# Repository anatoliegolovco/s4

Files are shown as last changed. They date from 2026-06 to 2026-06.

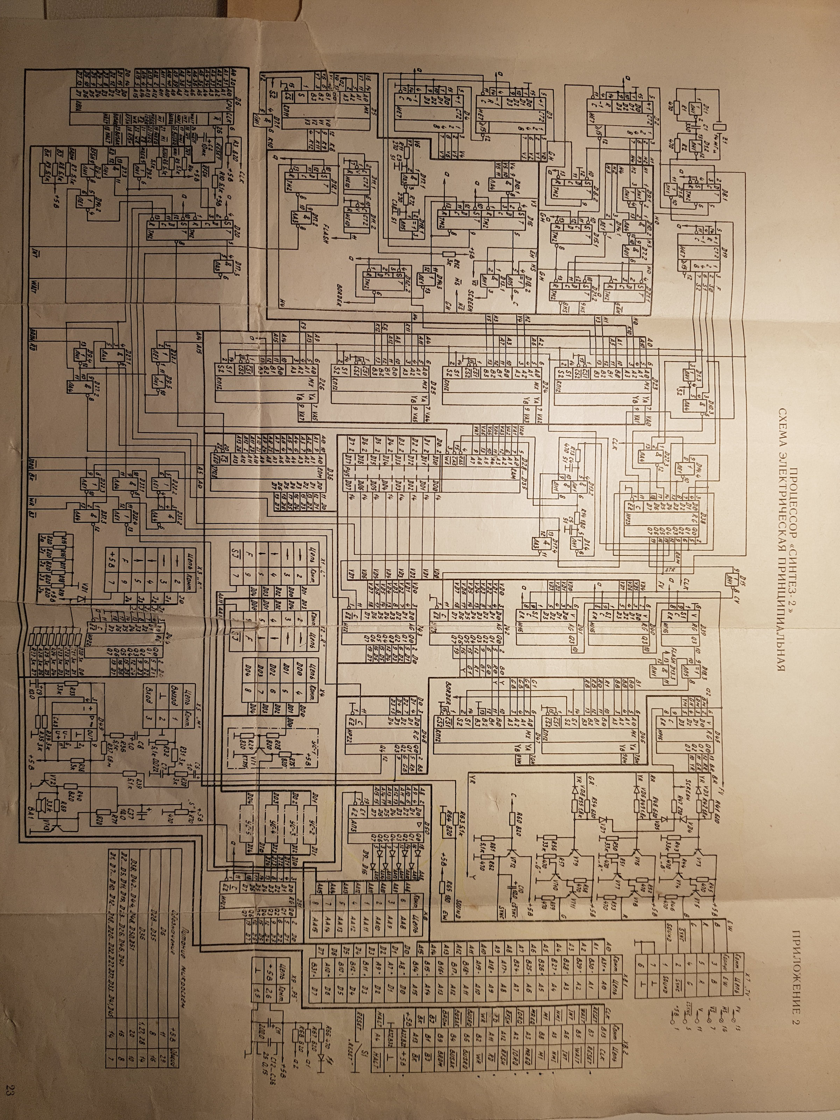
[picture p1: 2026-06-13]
reference/schematics/sintez2-mainboard-photo.jpg

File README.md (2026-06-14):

# s4 — Sintez 4

**Sintez 2 — Modern Reconstruction & LLM-Driven Visual Simulation.**

A modern, sourceable recreation of the Soviet/Moldovan discrete-TTL ZX Spectrum
clone (keeping a real Zilog Z80), a visual open-source simulator (SimulIDE) the
owner can watch, and a text-only LLM control plane that drives the full
iterate→simulate→verify→layout loop with zero clicks. KiCad is the source of
truth for the PCB.

## Start here

- **Technical spec (canonical):** [`docs/spec/sintez2-recon-spec.md`](./docs/spec/sintez2-recon-spec.md)
- **Docs index:** [`docs/README.md`](./docs/README.md)
- **Decisions:** [`docs/decisions/`](./docs/decisions/)
- **Discussion ledger:** [`docs/ledger/README.md`](./docs/ledger/README.md)
- **Repo layout:** [`docs/repo-layout.md`](./docs/repo-layout.md)

## Source tree

`schematics/` · `kicad/` · `bridge/` · `sim/` · `llm/` · `cpu/` · `tests/` ·
`parts_map.json` — all currently skeletons, populated per milestones T0–T9 in
the spec. All Markdown lives under `docs/` (project rule).

## License

**Proprietary and confidential — © 2026 Lightcypher SRL. All rights reserved.**
This is **not** open-source software. See [`LICENSE`](./LICENSE). Third-party
tools (KiCad, SimulIDE, ngspice, SKiDL) keep their own licenses; mirrored
datasheets/scans under `reference/` belong to their respective owners.

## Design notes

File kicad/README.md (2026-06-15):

# kicad — canonical project (source of truth for the PCB)

See `docs/spec/sintez2-recon-spec.md` §5.1 and milestones T2/T8.
Gerbers ordered from here. The LLM mostly edits `.kicad_sch` as text and uses
`kicad-cli` for ERC/DRC/netlist/Gerber export (IPC API is PCB-only in 9.0).

(Skeleton — no project authored yet.)

## T8 — PCB (in progress)

The PCB is seeded from the SKiDL netlist (no hand layout):
```bash
# 1. netlist -> board with all footprints (run once to seed)
PYTHONPATH=/usr/lib/python3/dist-packages KICAD9_FOOTPRINT_DIR=/usr/share/kicad/footprints \
  .venv/bin/kinet2pcb -i kicad/sintez2.net -o kicad/sintez2.kicad_pcb -w
# 2. spread footprints + add board outline
PYTHONPATH=/usr/lib/python3/dist-packages python3 kicad/place_board.py
# 3. fab outputs
kicad-cli pcb export gerbers -o kicad/gerbers/ kicad/sintez2.kicad_pcb
kicad-cli pcb export drill   -o kicad/gerbers/ kicad/sintez2.kicad_pcb
```
**Status:** `kicad/sintez2.kicad_pcb` has all 85 footprints placed on a 9×10 grid
(337×320 mm) with an Edge.Cuts outline; Gerber + drill export verified (26 files).
DRC: 23 courtyard/silk overlaps + 421 unconnected pads = **not routed yet**.
**Next:** tighten placement by block; route (manual or Freerouting .dsn/.ses);
then DRC-clean + final Gerbers/BOM. `kicad/sintez2.kicad_pcb` is the layout source
of truth — do NOT re-run kinet2pcb once routing starts (it overwrites the board).

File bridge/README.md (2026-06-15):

# bridge — KiCad ↔ SimulIDE converter

See `docs/spec/sintez2-recon-spec.md` §7 and milestone T3.

- `net2sim.py` — KiCad netlist (`kicad/sintez2.net`, from SKiDL) → SimulIDE
  circuit (`sim/circuits/*.sim1`), canonical direction.
- `sim2net.py` — optional reverse.

Mapping is driven by `../parts_map.json`.

## SimulIDE `.sim1` format (1.1.0-SR2, learned from `examples/Logic/*.sim1`)

```xml
<circuit version="" rev="2221" stepSize="1000000" stepsPS="1000000" ...>
  <item itemtype="Subcircuit" CircId="74XX90-3" Pos="x,y" label="7490"
        Input_High_V="2.5 V" Out_High_V="5 V" Out_Low_V="0 V" Out_Imped="40 Ω"
        Tpd_ps="10000 ps" Tr_ps="3000 ps" Tf_ps="4000 ps" .../>     <!-- IC -->
  <item itemtype="Clock" CircId="Clock-2" Freq="2 Hz" Voltage="5 V" .../>
  <item itemtype="Node"  CircId="Node-112" Pos="x,y" />              <!-- fan-out -->
  <item itemtype="Connector" uid="connector-113"
        startpinid="Clock-2-outnod" endpinid="74XX90-3-CP0" pointList="x,y,..." />
</circuit>
```
- Each component = one `<item>`; pins referenced as `"<CircId>-<pinname>"`.
- Each net with N endpoints → one `Node` + N `Connector`s (star), or chained connectors.
- **Per-part logic-family timing** (`Tpd_ps`, `Out_High_V`, `Out_Imped`, input
  thresholds/impedance) is set on each Subcircuit — this is where the К555 (LS) vs
  К1533 (ALS) distinction lives (spec §3). net2sim sets these from `parts_map.json`.

## Part mapping (Soviet → SimulIDE library item)

SimulIDE ships everything needed (data dir): a **Z80** model (`z80.xml` — use it,
NOT "ULA ZX48k"), the full 74xx series (`data/ic74.xml`), RAM/ROM/EEPROM, CD4000
(`icCD.xml`), and a USSR lib (`ussr.xml`).

| Sintez (ref) | KiCad/SKiDL part | SimulIDE item |
| --- | --- | --- |
| D6 Z80 | Z84C00 | `Z80` |
| D36 ROM 27128 | 27128 | `Memory`/`EEPROM` (16Kx8, load ROM bin) |
| D28-D35 К565РУ5 | K565RU5 | `RAM` (initial); behavioral РУ5 w/ RAS-CAS = T5 custom |
| ИЕ7 (D2/3/4/19) | K1533IE7 | `74HC193` |
| КП11 (D5) | K1533KP11 | `74HC257` |
| КП12 (D23-26) | K1533KP12 | `74XX253` |
| ИР22 (D43/44/48/51) | K1533IR22 | `74HC373` |
| ИР23 (D42) | K1533IR23 | `74HC374` |
| ИР27 (D38) | KR1533IR27 | `74XX273` |
| АП3 (D50) | K1533AP3 | `74XX244` |
| ИР16 (D39-41/45) | K555IR16 | 4-bit shift (`74XX166`-class), KEEP LS timing |
| ЛН1/ЛА3/ЛА4/ЛИ1/ЛЕ1 | K1533LN1/LA3/LA4/LI1/LE1 | `74XX04/00/10/08/02` |
| СА3 (D49) | K544SA3 | comparator (analog) |

## Validation goal (why the bridge exists)

Load the generated `.sim1` in SimulIDE, run, and validate the nodes the
trace-verify workflow could NOT resolve visually (see
`docs/references/validation-trace-verify-2026-06-14.md`): ROM /CE-/OE gating,
the arbitration screen-address select, RAS-before-CAS, beep/port-0xFE — and the
overall "boots to the © prompt" bar (spec T7). Contention tests must NOT pass.

## Status

- **net2sim.py — v1, LOADS CLEANLY in SimulIDE (0 errors).** Parses
  `kicad/sintez2.net` and emits `sim/circuits/sintez2.sim1`:
  - **Z80** → `itemtype="MCU"` (pins PORTA*/PORTD*/CPORT0*); 74xx → `Subcircuit`
    (pin number→id from SimulIDE `.package`, `_LS` variant for К555 timing);
    R/C → Resistor/Capacitor; crystal → 14 MHz Clock.
  - **Nets → drawn orthogonal wires, channel-routed.** Components sit in a single
    ROW; each net gets a unique horizontal TRACK in the channel BELOW the row, with
    a 3-pin Node under each pin and a vertical drop from pin→track. Because every
    track is below the components, **no wire crosses a component body** (wires only
    cross each other — SimulIDE has no auto-router; confirmed via its docs). Run:
    36 comps → 27 items, 98 nodes, 171 connectors.
  ```bash
  .venv/bin/python bridge/net2sim.py
  DISPLAY=:0 simulide sim/circuits/sintez2.sim1 &   # opens cleanly
  ```
  Verified headless: `simulide <file>` reports **0 load errors**.
  Coverage caveats it prints: DRAM (D28–D35) + ROM (D36) skipped (need SimulIDE
  Memory/DynamicMemory items — next); D5 follows the netlist (still КП12 in SKiDL —
  set to КП11 when arbitration is finished); КП12→74HC153, ИР16→74XX166 (8 vs 4-bit),
  ЛА4→74HC00 (no 3-in NAND in lib) are approximations.
- **Next:** (a) add ROM (`itemtype="Memory"`, load the ROM bin) + DRAM
  (`itemtype="DynamicMemory"` — ideal for РУ5 RAS/CAS) with their pin maps;
  (b) set per-part family timing (Tpd/Out_V) from parts_map on each Subcircuit;
  (c) run + validate boot-to-© and RAS-before-CAS.
- **Template:** `examples/Micro/Z80/ZX_Spectrum/ULA_Z80-MCU.sim1` (a ZX48 in
  SimulIDE) — reference for Z80-MCU + Memory + Tunnel wiring (but it uses a ULA,
  which the Sintez does NOT — we keep discrete TTL).

(`sim/circuits/*.sim1` is a generated build artifact — gitignored; regenerate.)

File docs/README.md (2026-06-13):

# s4 — Documentation

Code name **Sintez 4**.

**Project:** *Sintez 2 — Modern Reconstruction & LLM-Driven Visual Simulation.*
A modern, sourceable recreation of the Soviet/Moldovan discrete-TTL ZX Spectrum
clone (keeping a real Zilog Z80), a visual open-source simulator the owner can
watch, and a text-only LLM control plane that drives the whole
iterate→simulate→verify→layout loop zero-click.

The canonical technical specification is
[`spec/sintez2-recon-spec.md`](./spec/sintez2-recon-spec.md). **Read it first.**

## Layout

| Path | Purpose |
| --- | --- |
| `docs/README.md` | This index. Start here. |
| `docs/RULES.md` | Rules for writing and maintaining docs and the ledger. |
| `docs/spec/` | Canonical technical specification. |
| `docs/decisions/` | Decision records (ADR-style) for lasting choices. |
| `docs/datasheets/` | Datasheet links + key parameters per part. |
| `docs/references/` | Catalog of owner-supplied primary sources (in `reference/`). |
| `docs/repo-layout.md` | The source-tree layout (spec §9) and deviations. |
| `docs/templates/` | Reusable templates for docs, decisions, and ledger entries. |
| `docs/ledger/` | Discussion ledger: timestamped Q&A grouped by topic. |

## Key decisions (non-negotiable constraints)

- [0001 — Keep a genuine Zilog Z80](./decisions/0001-keep-real-zilog-z80.md)
- [0002 — KiCad is the source of truth for the PCB](./decisions/0002-kicad-source-of-truth-for-pcb.md)
- [0003 — Text-only, zero-click LLM control plane](./decisions/0003-text-only-llm-control-plane.md)
- [0004 — Fidelity over improvement: no memory contention](./decisions/0004-fidelity-no-memory-contention.md)

## Conventions (summary)

- **Language:** every written record is in **English**, even when the
  discussion happened in another language.
- **Files and folders:** `kebab-case` (lowercase, words joined by `-`).
- **Timestamps:** UTC, ISO 8601 (`YYYY-MM-DDTHH:MM:SSZ`).

See [`RULES.md`](./RULES.md) for the full set of rules.

## Quick start

1. Understand the project → read [`spec/sintez2-recon-spec.md`](./spec/sintez2-recon-spec.md).
2. See where work stands → [`ledger/README.md`](./ledger/README.md) (open questions).
3. Adding a doc? Copy [`templates/doc.md`](./templates/doc.md).
4. Recording a decision? Copy [`templates/decision-record.md`](./templates/decision-record.md).
5. Logging a discussion? See [`ledger/README.md`](./ledger/README.md).

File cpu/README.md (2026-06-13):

# cpu — Z80 soft-core integration (simulation only)

See `docs/spec/sintez2-recon-spec.md` §4. In simulation we always use a
behavioral Z80 core (TV80 / A-Z80); the real Z84C00 only lives on the
fabricated PCB.

(Skeleton — not yet implemented.)

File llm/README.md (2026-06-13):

# llm — text-only LLM command surface

See `docs/spec/sintez2-recon-spec.md` §6 and milestone T4. Zero-click, text in/out.

- `kicad_cmds.py` — kicad-cli / kicad-python / IPC wrappers.
- `sim_cmds.py` — SimulIDE control + probe/scope/assert.
- `vcd_to_json.py` — compact JSON from VCD.
- `verdicts.py` — M1 timing, RAS/CAS, sync, boot checks.

(Skeleton — not yet implemented.)

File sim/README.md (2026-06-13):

# sim — SimulIDE components & generated circuits

See `docs/spec/sintez2-recon-spec.md` §5.2, §6.2 and milestones T5/T6.

- `components/` — extended SimulIDE component classes / subcircuits
  (К565РУ5 behavioral DRAM, КП12 mux, ИЕ7 counter, ИР16 shift register).
- `circuits/` — generated `.sim` files (not committed).

(Skeleton — not yet implemented.)

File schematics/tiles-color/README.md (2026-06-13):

# Color schematic (redraw) — tiles & extraction

The colorized **vector** redraw `reference/schematics/sintez2-original.pdf`
(842×595 pt, A4 landscape) is far cleaner than the photographic scan and, decisively,
**names its nets and prints exact part numbers**. It is the *primary* source for
the netlist; the scan (`../tiles/`) is the cross-check.

## Color semantics (decoded from per-color layer separations)

| Stroke RGB | Meaning |
| --- | --- |
| `(0.63,0,0)` dark red | **component symbols + pins** (IC bodies, R/C, transistors, connectors) |
| `(0,0,1)` blue | **text labels** — net names, bus names, designators, pin names |
| `(0,0.63,0.63)` cyan, `(0,0.63,0)` green, `(0,0,0.75)` dk-blue, `(1,0,0)` red, black | **wires/nets**, color-grouped for routing legibility |

The text is vector outlines (not selectable — `get_text()` returns 0 chars), so
labels are still read visually, but at this clarity transcription is reliable.

## Files

- `c_r{row}c{col}.png` — 4×3 overlapping grid @400 dpi (same scheme as `../tiles/`).
- `_overview.png` — whole sheet @200 dpi.
- `_grid_overview.png` — overview with a 50-pt magenta coordinate grid (use it to
  pick clip rectangles for tight high-zoom crops).
- `layers/layer_<color>.png` — each stroke color rendered in isolation. `layer_darkred`
  = the parts layer; `layer_blue` = the net-name layer; the rest are wire groups.
  **These are the net-tracing aid**: follow one wire color to see a net group alone.
- `zoom/zoom_*.png` — high-zoom crops where exact part numbers / pinouts were read
  (color stage, DRAM, RGB output + connectors, X8 bus pinout).

## Reproduce a tight crop

```python
import fitz
p = fitz.open("reference/schematics/sintez2-original.pdf")[0]
p.get_pixmap(matrix=fitz.Matrix(1000/72, 1000/72),
             clip=fitz.Rect(615, 278, 725, 340)).save("zoom_x8.png")  # X8 bus pinout
```

## What this pass corrected vs the scan

- **Logic family is К1533** (≈74ALS/F), not К555, for the glue/counters/muxes.
  Registers/shift-registers are **К555ИР16/ИР22/ИР23** (LS) and DRAM is **К565РУ5**.
- **D41** (not "D61") is the third pixel shift register — matches the spec text.
- **D13 = К1533ЛИ1** generates **/RAS** and **/CAS** (with R15 470 + C5).
- **D14 = К1533ЛЕ1** (NOR) — original scan read was right.
- CPU is labeled **Z80A** (D6); D28–D35 block is labeled **DRAM**.
- Net names harvested: see `../wiring.json`.

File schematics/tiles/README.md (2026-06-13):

# Schematic tiles — segmentation map

High-resolution segments of the Sintez-2 mainboard schematic, kept so the
visual extraction is reproducible and reviewable without re-rendering.

- **Source:** `reference/schematics/sintez2-schematic.pdf` (page is 2040×1560 pt).
- **Render:** PyMuPDF at **350 DPI** with overlapping clip rectangles.
- **Naming:** `t_r{row}c{col}.png` — a 3-row × 4-col grid (rows top→bottom,
  cols left→right). Overlap avoids cutting components at seams.

## Grid → page rectangle (PDF points) and dominant content

| Tile | clip rect (x0,y0,x1,y1) | Dominant content |
| --- | --- | --- |
| `t_r1c1` | 15,25,560,500 | Z1 14 MHz; sync counters D2/D19; D8 ТМ2; D1 ЛН1 |
| `t_r1c2` | 520,25,1060,500 | address mux D23; RAM addr latch D38; sheet title |
| `t_r1c3` | 1020,25,1545,500 | pixel chain D39/D40/D61; color D45/D46; RGB ladder |
| `t_r1c4` | 1480,25,2035,500 | connectors X7 "TV", X8.1/X8.2 bus; RGB transistors |
| `t_r2c1` | 15,470,560,930 | vertical counters D3/D4; sync gates; D31 ИЕ10 |
| `t_r2c2` | 520,470,1060,930 | **DRAM D28–D35**; address muxes D24/D25 |
| `t_r2c3` | 1020,470,1545,930 | video latches D42/D43/D48; attr mux D47; D50 |
| `t_r2c4` | 1480,470,2035,930 | connectors X8 cont.; D50 buffer; sync transistors |
| `t_r3c1` | 15,895,560,1305 | **CPU D6 (Z80)**; WAIT D20; keyboard mux КП11 |
| `t_r3c2` | 520,895,1060,1305 | **ROM D36**; addr mux D26; decode gates |
| `t_r3c3` | 1020,895,1545,1305 | tape X5 "M"; УС-1 (VT1 КТ315); modules УС-2..5 |
| `t_r3c4` | 1480,895,2035,1305 | D51 latch; X9 power; **"Питание микросхем"** table |

Extra full-context renders:
- `_full_overview.png` — whole sheet at 150 DPI.
- `_right_connectors_top.png` / `_right_connectors_bot.png` — the right-edge
  connector + power tables at 300 DPI.

## Reproduce

```python
import fitz
d = fitz.open("reference/schematics/sintez2-schematic.pdf"); p = d[0]
m = fitz.Matrix(350/72, 350/72)
p.get_pixmap(matrix=m, clip=fitz.Rect(15, 895, 560, 1305)).save("t_r3c1.png")  # CPU
```

Extraction results live in `../bom.json` (parts) and `../wiring.json` (nets).

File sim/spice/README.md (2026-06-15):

# sim/spice — analog corner validation (ngspice)

Batch SPICE decks (`ngspice -b *.cir`) validating the analog parts of the Sintez-2
that digital simulation can't (spec §5.3). Run, e.g.:

```bash
ngspice -b sim/spice/psu_mod.cir
```

## psu_mod.cir — the factory 39 Ω GND-lift mod ✅ VALIDATED

The unit had a 39 Ω resistor between the LM7805 GND pin and ground; the repair video
measured **~5.35 V** no-load. A 78xx regulates 5 V between OUT and its GND pin, and
its ground-pin current `Ignd` flows through that resistor: **Vout = 5 + Ignd·Rgnd**.

| Ignd | Vout (39 Ω, factory) | Vout (39‖15 = 10.6 Ω, repair) |
| --- | --- | --- |
| 4.3 mA (typ) | 5.17 V | 5.05 V |
| 6 mA | 5.23 V | 5.06 V |
| 8 mA | 5.31 V | 5.08 V |
| 9 mA | **5.35 V** | 5.10 V |

**Result:** the measured 5.35 V corresponds to Ignd ≈ 9 mA — exactly the documented
behavior. The 15 Ω parallel repair pulls Vout back to ~5.05–5.10 V (near nominal,
effect reduced but not removed — matches the video). Mechanism confirmed quantitatively.

## rgb_level.cir — RGB output levels (КТ315 follower) ✅ representative

One colour channel: TTL colour + BRIGHT bits → resistor DAC → КТ315 emitter follower
→ 75 Ω TV/SCART input. Validates distinct, monotonic levels and that the КТ315
(Vbe/hFE) sets them (spec class-4: 2N3904/BC237 would shift the levels).

| State | Vout into 75 Ω |
| --- | --- |
| OFF | ~0 V |
| NORMAL | 0.96 V |
| NORMAL + BRIGHT | 1.37 V |

**Result:** normal vs bright are cleanly separated → the analog levels are real and
КТ315-dependent. ⚠ Weights here are representative (R48 620, R49 1.8k, R43 33k);
the exact per-board ladder topology is still to be traced
(`docs/references/validation-trace-verify-2026-06-14.md`), after which this deck
becomes the board-exact RGB model (milestone T6).

## Not modeled here
- **14 MHz crystal oscillator** — high-Q crystal start-up is impractical in plain
  transient SPICE; treat the clock as an ideal source in the digital/SimulIDE model.
- **К565РУ5 DRAM RAS/CAS timing** — behavioral, belongs in the SimulIDE model (T5).

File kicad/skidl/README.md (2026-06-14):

# kicad/skidl — canonical schematic authored in SKiDL (text → KiCad netlist)

Per decision [0005](../../docs/decisions/0005-skidl-text-schematic.md), the
Sintez-2 schematic (spec milestone T2) is authored as **Python/SKiDL**, which
emits a **KiCad netlist** that feeds Pcbnew for layout (T8, decision 0002) and
`bridge/net2sim.py` for SimulIDE. SKiDL is the text-only surface the LLM drives
zero-click (decision 0003); no graphical `.kicad_sch` is hand-drawn.

## Files
- `sintez_parts.py` — the Sintez part library: each IC defined with its real pin
  list (number/name/type) from `docs/datasheets/` + `schematics/bom.json` (v0.3).
  No KiCad symbol library needed; footprints reference KiCad's standard `Package_DIP:*`.
- `sintez2.py` — the top-level design, built block by block. Generates
  `kicad/sintez2.net` and runs ERC.

## Run
```bash
.venv/bin/python kicad/skidl/sintez2.py
```
(`.venv` has `skidl`; create with `python3 -m venv .venv && .venv/bin/pip install skidl`.)
The generated `*.net` is a build artifact (gitignored) — regenerate from the Python.

## Status — block by block (spec §8)
- [x] **Block 1 — CPU + clock + reset** (D6 Z80, Z1 14 MHz osc + D1 К1533ЛН1,
      reset RC C2/R10, control-input pull-ups R4–R7). Netlist generates, **0 ERC
      errors** (warnings are unconnected bus pins — expected until the blocks
      below are wired).
- [x] **Block 2a — ROM (D36 27128)** wired to the A0–A13 / D0–D7 buses + power
      (VPP/PGM=VCC). Verified: A0=D6.30+D36.10 … D0=D6.14+D36.11; A14 CPU-only
      (27128 is 16K). /CE,/OE are named decode nets pending the decode sub-block.
- [x] **Block 2b — ROM decode** (D22 ЛЕ1, D9 ЛН1, D17 ЛА3): ~ROMCS =
      NAND(A14 NOR A15, ¬/MREQ); ROM /OE = /RD. Logic verified in the netlist,
      0 ERC errors. ⚠ Functional: exact gate-section/pin mapping to verify vs the
      scan. Screen / I/O (port 0xFE) selects + D10/D27/D37/D26 still to add.
- [x] **Block 3 — DRAM array (D28–D35 К565РУ5)** — 8×1-bit = 64 KB, sharing VA0–VA7
      (address-pin map from wiring.json), /RAS, /CAS, /WE; per-bit DIN←Dn, DOUT→DDn.
      /RAS,/CAS from D13 ЛИ1; /WE=/WR. Verified, 0 ERC errors. ⚠ Timing strobes into
      D13 + refresh come from the arbitration/sync blocks (4/5); РУ5 timing model = T5.
- [~] **Block 4 — bus arbitration ("crown jewel"), PARTIAL.** D5/D23/D24/D25/D26
      КП12 + D38 ИР27 placed + powered; mux outputs mapped to VA0–VA5 (drives the
      DRAM address bus). ⚠ The data-INPUT mapping (screen-address generator: which
      CPU/video bit → which 4:1 input, + select/enable timing) is deliberately NOT
      guessed — it must be traced pin-by-pin from the scan (most intricate logic on
      the board). VA6/VA7 source + D26 paging + D38 latch nets also pending.
- [~] **Block 5 — /4 CPU-clock divider + sync counters.** D8 ТМ2 ripple-divides
      CLK14 → 7 MHz (dot) → 3.5 MHz **CLK** (resolves the CPU clock; was undriven).
      D2/D19 (H) + D3/D4 (V) ИЕ7 counters placed/powered/clocked + cascaded.
      ⚠ H/V sync DECODE (counter bits → HSYNC/VSYNC/blank via D10/D14/D21) functional/TODO.
- [ ] Block 6 — pixel chain (D39/D40/D41 ИР16) + colour (D42–D48) + RGB out.
- [ ] Block 7 — tape/audio (D49 К544СА3, beep) + disk I/O (D44/D50/D51) + connectors.

Each block draws its pin-level nets from `schematics/wiring.json` (filled in as
blocks are traced).

## KiCad version
For PCB layout + headless ERC you need **KiCad 9** (kicad-cli 7 has no `sch erc`):
```bash
sudo add-apt-repository -y ppa:kicad/kicad-9.0-releases
sudo apt update && sudo apt install -y kicad
```
The SKiDL netlist generation here does **not** need KiCad installed.

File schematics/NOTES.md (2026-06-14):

# schematics/NOTES.md — block inventory & scan-error reconciliation

> **Status: T1 essentially COMPLETE (v0.3).** Every functional block listed with
> source + discrepancies resolved; **all 51 ICs identified** (see `bom.json`).
> Deliverable for T1 in the spec (`docs/spec/sintez2-recon-spec.md` §8). Primary
> sources in the repo (`reference/`, catalogued in
> `docs/references/sources-catalog.md`). Remaining work is pin-level net tracing
> (→ `wiring.json`, milestone T2).

## Sources in hand

| Source | Location | Used for | Notes |
| --- | --- | --- | --- |
| Sintez-2 mainboard schematic (scan) | `reference/schematics/sintez2-schematic.pdf` | mainboard nets + BOM | "ПРИЛОЖЕНИЕ 2", clean scan, BOM table on right edge |
| Sintez-2 mainboard schematic (redraw) | `reference/schematics/sintez2-original.pdf` | cross-check | colorized re-draw of the same sheet |
| Beta Disk board photo | `reference/photos/betadisk-original.png` | TR-DOS controller | КР1818ВГ93 (WD1793) confirmed |
| 128 KB expansion writeup | `reference/photos/sintez128.jpg` | banking mod | port #7FFD paging |
| SCART/Jack video mod | `reference/pinouts/video-pinout.png` | RGB output stage | 200 Ω sync resistor note |
| MCbx (corrected pinouts) | https://oldcomputer.info/8bit/sintez/index.htm | TBD | online cross-check |
| speccy.info (RU) | https://speccy.info/Sintez | TBD | online cross-check |
| zx-pk.ru | https://zx-pk.ru | TBD | repair threads |

## Block inventory

Designators below were transcribed from the segmented tiles
(`schematics/tiles/`). Full structured data is in `schematics/bom.json`
(parts) and `schematics/wiring.json` (nets). `[x]` = block identified;
pin-level nets are tracked in `wiring.json`'s per-block `status`.

- [x] **CPU & clock** — **D6 = Z80** (power pins 11/29 confirm DIP-40); Z1
      14 MHz pixel clock; clock R3 820, reset C2 10µF + R10 5.1k, pull-ups
      R4/R5 5.1k; WAIT gen D20/D12 ТМ2. (tile r3c1)
- [x] **Address decode** — D26 КП12 mux (A9/A13/A14/A15); decode gates
      D22 (ЛЕ1), D9 (ЛН1), D10/D27/D37 (ЛА4), D17 (ЛА3); ROM /CE pin20, /OE pin22;
      decode signals /BROM,/RD,/WR,/IORQ,/BK,/WAIT,/BJ. (tiles r2c1, r3c2)
- [x] **DRAM + refresh** — **D28–D35 = К565РУ5** ×8 (power pins 8/16); address
      muxes D24/D25 → VA; refresh address from ИЕ7 counters; WAIT to slow РУ5.
      (tile r2c2)
- [x] **Video bus arbitration ("crown jewel")** — D23/D24/D25/D26 КП12
      (≈74ALS253) + D38 ИР23 latch → VADDR + RAS/CAS. (tiles r1c2, r2c2)
- [x] **Sync generation** — D2/D19 (H), D3/D4 (V) = ИЕ7 (СТ2 counters); D8/D21
      ТМ2; D10 ЛА4; D14 ЛЕ1; D18 ЛП5 (FLASH). (tiles r1c1, r2c1)
- [x] **Pixel chain** — **D39/D40/D41 = К555ИР16** @ 14 MHz; **keep LS timing**.
      ⚠ К555ИР16 is a **4-bit / 14-pin** shift register (PE/SI/C/OE, D0-D3→Q0-Q3),
      **NOT 74LS165** (which is 8-bit/16-pin). D39=VD0-VD3, D40=VD4-VD7 (=8-bit
      pixel shifter), D41=3rd nibble/attribute. (redraw symbols, tile r1c3)
- [x] **RGB output stage** — VT3–VT18 (КТ315Г/КТ361Г) + ladder R41 620/R42
      1.8k/R47 270/R48 620/R49 1k/R54 620/R55 1.8k/R60 820 + VD3–VD8; УС-1
      emitter follower (VT1). SCART mod: **200 Ω sync** (100 Ω → color loss).
      Color stage D42/D43/D45/D46/D47/D48. (tiles r1c3, r2c3, r3c3)
- [x] **Audio/tape** — port 0xFE (BEEP/border/tape); X5 "M" connector
      (TAPE_IN/GND/TAPE_OUT); R30/R31 3k, R32 5.1k. ⚠ Tape-IN is squared by
      **D49 = К544СА3, an analog COMPARATOR** (R37 1.8M feedback) — **NOT** a
      К5545АЗ/LM567 tone decoder as the spec §2.5 states. BEEP: port-0xFE bit →
      R69 33k → VT2/VT13 КТ315 → BA1 speaker. (tiles r3c3, r3c4)
- [x] **TR-DOS / Beta Disk** — **КР1818ВГ93 ≈ WD1793** (FDC on daughterboard;
      schematic now in `reference/schematics/betadisk-controller-bdi.pdf`).
      Mainboard carries **D50 = К1533АП3** (74244 buffer, AA8-AA15 disk address
      via КД522 diodes) + **D51/D44 = К1533ИР22** (74373 disk-data latches).
      Joystick/disk connectors X1('L')/X2('R')/X3('K')/X4/X6. Board `СМП59-96Г-16-2`.
- [ ] **(Optional) 128 KB expansion** — port `#7FFD` paging; mod chips
      К555ТМ9 / К1533КП11 / К555ЛЛ1 / К1533ЛА3 (`reference/photos/sintez128.jpg`).
      Opt-in variant — see `docs/ledger/architecture/bank-switching-ram-size.md`.

## Two source documents

- **Scan** `reference/schematics/sintez2-schematic.pdf` — authoritative original;
  carries the connector + power tables. Tiled in `schematics/tiles/`.
- **Colorized vector redraw** `reference/schematics/sintez2-original.pdf` — cleaner,
  **names nets and prints exact part numbers**. Tiled in `schematics/tiles-color/`
  (+ `layers/` per-color separations, + `zoom/` high-zoom crops). **Primary**
  net-naming source; the scan is the cross-check. Color code: dark-red=parts,
  blue=net labels, other colors=wire groups.

## Redraw cross-check corrections (v0.2)

- Logic family is **К1533** (≈74ALS/F); registers **К555ИР16/ИР22/ИР23** (keep LS);
  DRAM **К565РУ5**; CPU labeled **Z80A**.
- **D41** (not "D61") is the 3rd pixel shift register (К555ИР16) — matches spec.
- **D13 = К1533ЛИ1** generates **/RAS** and **/CAS** (R15 470 + C5).
- **D14 = К1533ЛЕ1** (NOR). **D45 = К555ИР16** color register; **D46/D47 = К1533КП12**.
- **X8** is a 64-pin expansion bus, pinout now high-confidence (`tiles-color/zoom/zoom_x8.png`).
- **УС-1…УС-5 = YC-1…YC-5**: five identical single-transistor analog driver modules.

## BOM & wiring — structured outputs

- `schematics/bom.json` — every identified package (ref → Soviet type → western
  equivalent → block), with `confidence` flags and a `gaps_to_resolve` list.
- `schematics/wiring.json` — buses, control signals, connector pinouts, power
  pins, and block-to-bus relations; pin-level intra-block nets are the next pass.
- Pipeline & status: `docs/schematic-extraction.md`.

## v0.3 — full IC resolution & corrections (2026-06-14)

Read directly from the **KiCad/Eeschema redraw** `Sintez_II_orig.sch` (NPO Signal
Chișinău, 29 oct 2012 — title block confirms it), rendered at 600–800 dpi from
`reference/schematics/sintez2-original.pdf` and cross-checked against the
"Питание микросхем" power table for pin counts.

**Previously-open designators — now resolved:**

| Ref | Type | ≈ Western | Pins | Role |
| --- | --- | --- | --- | --- |
| D37 | К1533ЛА4 | 74ALS10 | 14 | triple 3-in NAND — keyboard/joystick decode |
| D44 | К1533ИР22 | 74ALS373 | 20 | octal latch — disk-data path |
| D49 | **К544СА3** | LM311-class comparator | 14 | **tape-IN comparator** |
| D50 | К1533АП3 | 74ALS244 | 20 | octal buffer — disk address AA8-AA15 |
| D51 | К1533ИР22 | 74ALS373 | 20 | octal latch — disk data-in |

**Corrections to the spec / earlier BOM:**

1. **D38 = КР1533ИР27** (74273 octal D-FF, 20-pin) — earlier read as ИР23/74LS374.
2. **К555ИР16 (D39/D40/D41/D45) is a 4-bit / 14-pin shift register, NOT 74LS165**
   (8-bit/16-pin). The redraw symbol shows PE/SI/C/OE + D0-D3→Q0-Q3; the power
   table puts them in the 14-pin group. D39(VD0-3)+D40(VD4-7) = the 8-bit pixel
   shifter. This resolves the v0.2 "discrepancy to reconcile". Exact 74xx
   equivalent (4-bit, 14-pin, 3-state, parallel-load) still TBD.
3. **Tape decoder is wrong in the spec:** the part is **К544СА3 (a comparator)**,
   not К5545АЗ/LM567. Spec §2.5 / §3 / §11 should be updated when convenient.

**Connectors captured (→ `wiring.json`):** X7 "TV" (SOUND/SYNC/B/G/R/GND, +
monitor group FV/HS/VS/Y/CSYNC/+5V), X8 64-pin expansion = full Z80 bus
(SNP58-64), X5 tape "M", X1/X2 Sinclair joysticks, X3 keyboard, X4/X6 disk,
X9 power. Full power-pin table transcribed.

## Known scan errors to reconcile

- [ ] Some connector pinouts in public scans relate to the mainboard rather
      than the wired connectors → cross-check MCbx re-mastered pinouts.
- [ ] Cross-check the in-repo scan against the colorized redraw
      (`sintez2-original.pdf`); log any net that disagrees here with resolution.

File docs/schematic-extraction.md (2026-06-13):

# Schematic extraction pipeline

How the paper Sintez-2 schematic becomes machine-readable design data, and the
text format we capture **before** anything goes into KiCad or SimulIDE.

## Two source documents

1. **Scan** `sintez2-schematic.pdf` (2040×1560 pt raster) — the authoritative
   original; has the connector + "Питание микросхем" power tables. Tiled in
   `schematics/tiles/`.
2. **Colorized redraw** `sintez2-original.pdf` (842×595 pt **vector**) — cleaner,
   and it **names nets and prints exact part numbers**. Tiled in
   `schematics/tiles-color/` with per-color layer separations. This is the
   **primary** source for the netlist and part numbers; the scan is the cross-check.

The redraw's color code: dark-red = parts/pins, blue = net-name labels, other
colors = wire groups. Text is vector outlines (not selectable), so labels are
still read visually — but at this clarity, transcription is reliable. Rendering
one wire color in isolation (`tiles-color/layers/`) is the net-tracing aid.

## Pipeline

```
sintez2-schematic.pdf (scan)      sintez2-original.pdf (vector redraw)
   │ render @350dpi, grid             │ render @400dpi grid + per-color layers
   ▼                                  ▼
schematics/tiles/             schematics/tiles-color/  (+ layers/, zoom/)
   └──────────────┬───────────────────┘
                  ▼  visual transcription (designators, types, nets, pins)
   schematics/bom.json    ← parts: ref → type → western equiv → block
   schematics/wiring.json ← nets: buses, connectors, power, block relations
                  │  (incremental, per-block, with confidence flags)
                  ▼
   parts_map.json + bridge/net2sim.py → KiCad (.kicad_sch) / SimulIDE (.sim)
```

The two JSON files are the **canonical intermediate**. They are plain text, so
the LLM owns them (spec §6), and they are filled **one block at a time** with a
`confidence`/`status` flag on every entry — we never silently promote a guess.

## Why JSON before software

- KiCad's schematic API is text-only in 2026 (decision
  [0003](./decisions/0003-text-only-llm-control-plane.md)); authoring from a
  structured netlist is far more reliable than drawing by hand.
- The same JSON drives the KiCad→SimulIDE bridge (spec §7), so BOM and wiring
  stay in one source of truth.
- Confidence flags let us author the **high-confidence blocks first** (CPU,
  ROM, DRAM) and leave low-confidence nets clearly marked for verification
  against the colorized redraw (`sintez2-original.pdf`) and zx-pk.ru.

## Current status (2026-06-13)

- **Tiles:** both sources segmented and committed — scan (3×4 grid,
  `schematics/tiles/`) and color redraw (4×3 grid + 7 color-layer separations +
  high-zoom crops, `schematics/tiles-color/`).
- **Redraw cross-check (v0.2):** logic family confirmed **К1533** (≈74ALS/F),
  registers **К555ИР16/22/23**, DRAM **К565РУ5**, CPU **Z80A**. Corrections:
  **D41** (not "D61") is the 3rd pixel shift register; **D13 = ЛИ1** makes
  /RAS+/CAS; **D14 = ЛЕ1**. **X8** 64-pin bus pinout now high-confidence.
- **BOM:** ~40 packages identified — CPU **D6 = Z80** (confirmed via power
  table), **D28–D35 = К565РУ5 DRAM**, **D36 = 16 KB ROM**, pixel chain
  **D39/D40/D61 = ИР16 (74LS165)**, address arbitration **D23–D26 = КП12
  (74ALS253) + D38 ИР23 latch**, sync counters **D2/D3/D4/D19 = ИЕ7**. See
  `schematics/bom.json`.
- **Wiring:** buses, control signals, connectors (X5/X9 high-confidence;
  X7/X8 medium), power pins, and block-to-bus relations captured. Pin-accurate
  intra-block nets are the next pass (`schematics/wiring.json` → `todo`).

## Next

Trace nets pin-by-pin in milestone order: **cpu → decode → dram →
addr-arbitration** (T2/T3), mark each block `status: done`, then feed it to
`bridge/net2sim.py` for a SimulIDE smoke test. See `schematics/NOTES.md`.

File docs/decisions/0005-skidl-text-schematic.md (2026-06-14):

# 0005 — Author the schematic in SKiDL (Python → KiCad netlist)

- **Status:** accepted
- **Date:** 2026-06-14
- **Deciders:** project owner
- **Related:** [0002 KiCad source of truth](0002-kicad-source-of-truth-for-pcb.md) ·
  [0003 text-only LLM control plane](0003-text-only-llm-control-plane.md) ·
  spec §5.1 / §8 (T2)

## Context

T2 needs the canonical Sintez-2 schematic (~51 ICs). The spec §5.1 assumed we
"edit `.kicad_sch` as text". Hand-authoring KiCad `.kicad_sch` S-expressions
(symbol placement coordinates, wires, labels) for 51 ICs is slow and error-prone,
and KiCad has **no Soviet-part symbols** anyway. kicad-cli 7 (Ubuntu noble) also
lacks headless `sch erc` (added in v8+).

## Decision

**Author the schematic as Python using SKiDL**, which emits a **KiCad netlist**.
- Parts are defined once in `kicad/skidl/sintez_parts.py` from the datasheets /
  `schematics/bom.json` (pin number/name/type) — these definitions ARE the parts;
  no KiCad symbol library is required to produce a netlist.
- Standard through-hole **DIP footprints are reused** from KiCad's `Package_DIP:*`
  (every Sintez IC is a DIP) — no custom footprints to draw.
- The generated netlist → Pcbnew for PCB layout (T8) and → `bridge/net2sim.py`
  for SimulIDE. **KiCad remains the source of truth for the PCB** (decision 0002
  unchanged); SKiDL is just the text front-end that authors it.

## Consequences

- Positive: the design is plain Python — ideal for the zero-click LLM loop
  (decision 0003), git diffs, parameterization, and reuse; SKiDL runs its own ERC
  without KiCad installed.
- Trade-off: no hand-drawn graphical `.kicad_sch`. If a human-viewable schematic
  is ever wanted, generate `.kicad_sym`/a schematic from the same pin data — it is
  not on the fabrication path.
- Follow-ups: KiCad **9** still needed for Pcbnew layout + headless ERC at T8
  (`ppa:kicad/kicad-9.0-releases`); `parts_map.json` continues to drive the bridge.

## Alternatives considered

- **Hand-author `.kicad_sch` text** (spec §5.1 literal) — rejected: too tedious /
  error-prone for 51 ICs, no Soviet symbols, needs KiCad 8+ for headless ERC.
- **Generate `.kicad_sch` from `wiring.json`** — real graphical schematic, but
  requires building a robust auto-placement generator first; deferred (can still
  be added later for human viewing).

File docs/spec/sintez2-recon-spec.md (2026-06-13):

# Sintez 2 — Modern Reconstruction & LLM-Driven Visual Simulation

## Technical Specification / Hand-off Brief for a Claude Code Context

> **Read me first.** You are a fresh Claude Code agent inheriting an ongoing
> retro-computing project. You did **not** participate in the prior design
> conversations; this document is your entire context. It is intentionally
> dense and self-contained. Treat every section as authoritative project
> knowledge. Where you must search, the canonical links are in
> [§12 References](#12-references). When in doubt about Sintez-specific
> hardware quirks, the Russian community at **zx-pk.ru** has people with the
> physical machine and corrected schematics.

-----

## 0. TL;DR — What we are building

Three deliverables, one loop:

1. **A modern recreation of the Sintez 2** — a Soviet/Moldovan ZX Spectrum
   clone built entirely from discrete TTL logic (no ULA chip) — rebuilt with
   **modern, sourceable components** while keeping a **real Zilog Z80** CPU.
1. **A visual, open-source electronics simulator** where the human owner can
   **watch the signals propagate** (buses, /MREQ, RAS/CAS, pixel clock, RGB).
1. **An LLM “puppeteering” layer**: the simulator and EDA tools are open
   source so we **extend their internal classes / APIs** with **text-friendly
   functions** an LLM can drive **fully automatically, zero-click** — no GUI
   pixel-clicking, no human in the inner loop.

The board is fabricated by exporting to / authoring in **KiCad** (Gerbers →
PCB fab). The visual play happens in **SimulIDE**. A **text↔text bridge**
connects the two so the LLM owns the full iterate→simulate→verify→layout loop.

**Non-negotiable constraints**

- Keep a genuine **Zilog Z80** (Z84C00 family) in the physical build.
- **KiCad is the source of truth for the PCB** (you order from its Gerbers).
- Everything the LLM touches must be **text** (netlists, `.kicad_sch`, SimulIDE
  XML, VCD, JSON) — never screen automation.
- **Fidelity over “improvement”:** the Sintez has no memory contention. If a
  contention-dependent test passes, the model is *wrong* for this machine.

-----

## 1. Project background — what the Sintez 2 actually is

- **Origin:** Soviet-era ZX Spectrum 48K-compatible clone manufactured at the
  **“Signal” plant (НПО «Сигнал»)** in **Chișinău, Moldovan SSR**, ~1989.
  It is **not** a Romanian clone (do not confuse with ICE Felix HC-85, Cobra,
  CIP from Băneasa/Politehnica) and **not** Băneasa.
- **CPU:** Uses the Soviet **UA 880D / КР1858ВМ1**-class part, which is
  **pin- and opcode-compatible with the Zilog Z80**. Runs at **3.5 MHz**.
- **Defining hardware trait — NO ULA.** Unlike a real Spectrum (Ferranti ULA),
  the Sintez 2 implements all video/timing/glue with **discrete TTL** (Soviet
  К555 / К1533 families ≈ 74LS / 74ALS). The RGB output is generated directly
  at TTL level (clean digital), not through a ULA.
- **Consequence — NO MEMORY CONTENTION.** There is no ULA disputing the bus,
  so the Z80 runs at a constant 3.5 MHz with **no slowdown** on any memory
  region. This is the single most important behavioral fact:
  - The Z80 core uses **canonical T-state counts** — no contention table, no
    `6,5,4,3,2,1,0,0` pattern.
  - Software that depends on tight contention timing (multicolor demos,
    Nirvana engine, rainbow-border effects) **will not run** on real Sintez 2
    hardware and must **not** run in our model. That is fidelity, not a bug.
- **ROM/BASIC:** Runs the **stock ZX Spectrum 48K 16 KB ROM**. All BASIC
  interpreter / FP-calculator internals are standard Spectrum documentation.
- **Storage:** Beta Disk + **TR-DOS** (WD1793 FDC, separate TR-DOS ROM with
  bank switching) on 5.25” floppies, in addition to tape.

**Schematic caveat:** the publicly scanned Sintez schematics contain **known
errors** (some connector pinouts relate to the mainboard rather than the
wired connectors). A re-mastered schematic on the MCbx page has corrected
pinouts. Always cross-check against zx-pk.ru repair threads.

-----

## 2. Target hardware architecture (what the recreation must implement)

### 2.1 CPU & clock

- **Z80** @ **3.5 MHz** (canonical T-states; 69,888 T-states per 50 Hz frame:
  224 × 312).
- **Pixel clock 14 MHz = 2× CPU clock**, asynchronous to the CPU clock. Drives
  the pixel shift register chain.

### 2.2 Memory map (standard 48K Spectrum)

|Region |Address |Notes |
|---|---|---|
|ROM (BASIC + FP calculator + I/O) |`0x0000–0x3FFF` |16 KB, stock 48K ROM |
|RST handlers / vectors |`0x0000, 0x0008, 0x0010, …, 0x0038`|entry points |
|BASIC interpreter |`0x0000–0x1CFF` |main logic |
|FP calculator (5-byte float stack machine)|`0x1D00+` (`CALCULATE` ≈ `0x335B`) |RPN-like calc stack |
|Keyboard scan |`~0x028E` | |
|Character font (8×8) |`0x3D00–0x3FFF` |96 chars × 8 bytes = 768 bytes|
|Screen bitmap |`0x4000–0x57FF` |256×192, ZX interleaved layout|
|Screen attributes |`0x5800–0x5AFF` |32×24, byte = `FLASH |
|System vars / BASIC area / RAM |`0x5B00–0xFFFF` | |

- **Bank switching:** native Z80 addresses 64 KB. If the modern build wants
  more RAM, page it through a window with latches/registers holding a wide
  bank address (the Z80 doesn’t care what’s behind the address decoder).
  128–512 KB is typical; >1 MB is possible but software-impractical. The
  Z180/Z280 have built-in MMUs (up to ~1 MB) if a successor CPU is ever
  considered — but **we keep the Z80**.

### 2.3 Video subsystem (the most Sintez-specific part — all discrete TTL)

- **ULA-replacement logic:** discrete TTL generates H/V sync and bus
  arbitration. **No ULA chip exists** — this entire arbitration circuit is the
  “crown jewel” to visualize.
- **Sync/refresh counters:** **К1533ИЕ7** counters (≈ 74ALS counter) generate
  H/V sync and the DRAM refresh addresses.
- **CPU/video bus arbitration:** **КП12** multiplexers switch the address/data
  bus between CPU and video fetch.
- **Pixel shift registers:** **D39/D40/D41 = К555ИР16** (≈ **74LS165**),
  clocked at **14 MHz** to serialize pixel data. **Deliberately К555 (LS), not
  К1533 (ALS)** — the designer chose the slower family for more forgiving
  setup/hold margin against the pixel clock. **Preserve this choice.**
- **RGB output stage:** emitter-follower level shifters built from
  **КТ315Г (NPN) / КТ361Г (PNP)** transistors (VT13–VT18 region), with trimmer
  resistors (~R41–R60 region) to calibrate output levels per transistor batch.

### 2.4 Memory (DRAM) — timing is analog and matters

- **DRAM:** **К565РУ5** (≈ 4164, 64Kx1 DRAM). Requires **RAS-before-CAS**
  refresh; **RAS-only refresh cycles interleaved** with CPU accesses, addressed
  by the К1533ИЕ7 counter.
- The Sintez **WAIT generator was calibrated to the *slow* Soviet РУ5 timing**
  (tRAS, tCAS, tRCD, precharge, sense-amp recovery). zx-pk.ru repair threads
  confirm that dropping faster imported 4164s in can cause **instability**
  (WAIT pulse mismatch, marginal address setup). For simulation, **model DRAM
  behaviorally with actual К565РУ5 timing parameters** — do not silently swap
  to a generic 4164 or SRAM model, which would make the machine look more
  reliable than reality.

### 2.5 Audio & tape

- **BEEP** via port `0xFE` (also border + tape). Port `0xFE` writes must be
  **timestamped in T-states**, not collapsed at end-of-frame, because the
  raster exists regardless of TTL-vs-ULA implementation.
- **Tape tone decoder:** **К5545АЗ** ≈ **LM567**. **Do not substitute** for
  accurate analog behavior.

-----

## 3. Soviet → modern component substitution guide (encyclopedic)

Soviet ICs were **clones, not exact copies** — same nominal datasheet, but
different process nodes and fab tolerances, occasionally subtle circuit
changes. Risk of behavioral divergence splits into categories:

|#|Class |Examples |Substitution risk |Rule |
|-|---|---|---|---|
|1|**Pure Boolean logic** (~95% of the board)|К1533ЛА3 ≈ 74ALS10, decoders, bus muxes, control glue|**Zero** for logic state|Free to swap to 74ALS/74HC equivalents; truth tables identical |
|2|**DRAM** |К565РУ5 ≈ 4164 |**High (timing)** |Model with real РУ5 timing; swapping to fast 4164/SRAM changes WAIT behavior |
|3|**Pixel shift registers** |К555ИР16 ≈ 74LS165 (D39/D40/D41) |**Subtle (setup/hold)** |Keep **LS** family timing (~20–25 ns setup) — ALS (~7–10 ns) gives ~3× false margin |
|4|**Video-output transistors** |КТ315Г/КТ361Г (VT13–VT18) |**Analog levels** |RGB level depends on Vbe/hFE; real boards used trimmers. 2N3904/BC237 ≈ wrong levels|
|5|**Tape tone decoder** |К5545АЗ ≈ LM567 |**Do not substitute** |Keep equivalent function exactly |

**Practical guidance for the recreation:**

- For everything in **Class 1**, choose modern, **sourceable** logic
  (74HC/74HCT or 74ALS) — these are the parts you can buy and put on a PCB.
- For **Class 2 (DRAM)**: a real recreation may legitimately replace DRAM with
  **modern SRAM + glue** to drop the refresh complexity *in hardware*, but the
  **simulation model must keep РУ5 timing** if you want bug-for-bug fidelity.
  Decide explicitly per build target (faithful vs. “improved & reliable”).
- For **Class 3/4/5**: preserve family/part choices where analog/timing
  behavior is observable (pixel chain, RGB stage, tape).

> Tool note: AI-assisted “legacy → modern part” suggestion exists in
> **Flux (flux.ai / buildwithflux)** — Copilot can propose cheaper/in-stock
> alternatives, create parts from datasheets, and import **KiCad** libraries
> (schematic import from Altium ASCII / Cadence EDIF; **layout import not
> supported**). Optional aid, not a core dependency.

-----

## 4. Keeping a real Z80 — sourcing

|Part |What |Notes / where |
|---|---|---|
|**Zilog Z84C00** (e.g. Z84C0020)|Genuine modern CMOS Z80, in production|€3–5 at Mouser / Digi-Key / TME; ships to Moldova; **recommended default**|
|КР1858ВМ1 / КР1858ВМ3 |Soviet NMOS/CMOS Z80 clone |eBay / au.ru / orion43.ru; shipping restrictions vary |
|U880 / UB880D |East German (MME) clone |eBay; often easier to find than Soviet parts |
|MMN 80 CPU |Romanian (Microelectronica) clone |from Romania (EU neighbor) |
|MME “80A CPU” |Z80A 4 MHz NMOS clone |~$10 + shipping from Ukraine |

**FPGA fallback (if a physical Z80 ever becomes unavailable):** run an
open-source soft core — **TV80** or **A-Z80** — on a small FPGA
(Lattice iCE40, Gowin GW1N; boards: iCEBreaker, Tang Nano), optionally
pin-compatible with a Z80 socket. **In simulation we always use a soft/
behavioral Z80 core** (TV80 / A-Z80) because a physical chip can’t be
co-simulated; the real Z84C00 only lives on the fabricated PCB.

-----

## 5. Tool stack

### 5.1 KiCad — schematic + PCB + fabrication (source of truth for the board)

- **License:** GPL v3. Full EDA: schematic capture, PCB layout, Gerber output;
  runs on Windows/Linux/macOS.
- **Why it’s the hub:** you **order the PCB from KiCad’s Gerbers** — it is the
  destination, so there is **no “export to KiCad” step** if the schematic is
  authored here. Huge symbol/footprint libraries (74xx, Z80, modern parts).
- **Built-in simulation:** integrates **ngspice** for graphical SPICE
  simulation inside the Schematic Editor (good for analog: PSU, clock, RGB
  output path). Improved substantially in KiCad 8; usable for mixed-signal.
- **Puppeting surface (text/Python — this is the LLM control plane):**
  - **IPC API** (KiCad **9.0+**): stable, language-agnostic interface to a
    running KiCad session over a Unix socket / named pipe. **In 9.0 it covers
    the PCB editor only**; schematic-editor support is on the roadmap.
  - **`kicad-python`** (PyPI): official Python bindings for the IPC API.
    Requires a running KiCad with the API server enabled
    (Preferences → Plugins). Depends on `protobuf`, `pynng`.
  - **Legacy SWIG `pcbnew`** bindings: still present in 9/10, **deprecated**,
    **removed in KiCad 11** — do not build new work on SWIG.
  - **`kicad-cli`**: headless CLI for ERC/DRC, netlist export, plotting
    Gerbers, BOM, etc. — the backbone for zero-click batch steps.
  - **Schematic automation reality (2026):** because IPC doesn’t yet cover the
    schematic editor, the LLM mostly **edits `.kicad_sch` / `.kicad_pro` as
    text** and uses `kicad-cli` for netlist/ERC/exports. Plan around this.

### 5.2 SimulIDE — the visual signal playground (what the human watches)

- **License:** AGPL v3. C++/Qt. Real-time, drag-drop, “push the power button”
  interactive simulation; optimized for speed/low CPU.
- **Why it fits the TTL machine:** **event-driven engine, 1 ps accuracy**, and
  **no digital/analog split — everything runs in analog mode**: logic pins have
  **configurable impedance, output voltage, and LH/HL thresholds**, so it
  models **fan-in/fan-out and different logic families** (LS vs ALS vs HC) —
  exactly the К555-vs-К1533 distinction we must preserve.
- **Observability built-in:** **Oscilloscope**, **Logic Analyzer**, **circuit
  animation**, **VCD export** (configurable base time step, e.g. 100 ps; can
  export at pause), serial-port connection, subcircuits, DIP/logic symbols.
- **Extensibility (your “extend its classes” requirement):** custom components
  via **(a) subcircuits, (b) modular components, (c) script-based components**;
  modules exist for memories, displays, console, comms. For Sintez-specific
  parts (К565РУ5 behavioral DRAM, КП12 mux, ИЕ7 counter, ИР16 shift register)
  you add component classes in the C++ source and/or as subcircuit/script
  modules.
- **Limitation:** SimulIDE is a *simulator*, **not** a PCB/layout tool — it
  does **not** export KiCad/Gerber. Hence the bridge in §7.

### 5.3 ngspice

- The SPICE engine inside KiCad; also usable standalone in **batch mode
  (`-b`)** for the analog corners (PSU, 14 MHz/3.5 MHz clock generation, RGB
  emitter-follower levels with КТ315/КТ361 models). Text netlist in, data out.

### 5.4 Optional reference / cross-check tooling (from prior project work)

- **Software emulator** (separate track): C23 → WASM Z80 core + passive video
  renderer; validated headless via **ZEXDOC/ZEXALL** (Frank Cringle, CRC),
  **FUSE test suite** (`tests.in`/`tests.expected`, per-instruction T-states &
  memory accesses), **Patrik Rak** contention/floating-bus tests. **For Sintez
  2, contention tests must NOT pass** (no contention) — passing them means a
  wrong machine. Use ZEXDOC + “boots to the `©` prompt” as the bar.
- **Disassembly/RE:** Fuse (+ gdbserver fork `github.com/speccytools/fuse`,
  `--gdbserver <port>`), `z80dasm`, Ghidra (Z80 module), radare2/rizin,
  `z88dk-gdb`.
- **Floppy ingest (TR-DOS):** SAMdisk, Keir Fraser’s `disk-utilities`,
  `trdtool`/`trd2scl`, Fuse/libspectrum utils.

-----

## 6. LLM puppeteering layer (the core new work)

**Goal:** a thin, text-only control plane so an LLM iterates the design with
**zero clicks**. The LLM never drives a GUI; it edits text artifacts and calls
functions that return text/JSON.

### 6.1 Principle

- **GUI automation is forbidden.** No Playwright/Selenium pixel puppeting.
- The LLM operates on: `.kicad_sch`, `.kicad_pcb`, KiCad netlists (`.net`),
  SimulIDE circuit XML, VCD waveforms, and JSON status blobs.
- We **extend the open-source tools’ internal classes/APIs** to expose exactly
  the verbs the LLM needs, each producing **parseable text**.

### 6.2 The command surface to build (wrap, don’t reinvent)

Expose a small CLI/library (Python preferred) with verbs such as:

- **KiCad side (via `kicad-cli` + `kicad-python`/IPC + text edits):**
  - `kicad.netlist_export()` → canonical netlist (text)
  - `kicad.erc()` / `kicad.drc()` → JSON pass/fail + violations
  - `kicad.plot_gerbers()` → fab outputs
  - `kicad.place(ref, x, y)` / `kicad.list_footprints()` (PCB, IPC API)
  - `kicad.sch_edit(...)` → structured edits to `.kicad_sch` text (until IPC
    covers eeschema)
- **SimulIDE side (via extended C++ classes + a control socket/CLI you add):**
  - `sim.load(circuit.sim)` / `sim.run(t)` / `sim.pause()` / `sim.reset()`
  - `sim.probe(net)` → current logic level / voltage
  - `sim.scope(net, window)` → samples
  - `sim.export_vcd(path)` → waveform file
  - `sim.add_component(type, params)` / `sim.connect(a_pin, b_pin)`
  - `sim.assert(net, expected, at_t)` → JSON verdict
- **Analysis glue (write this):**
  - `vcd_to_json(path, nets=[…])` → compact JSON the LLM reads cheaply
  - Verdict helpers: “Is `/MREQ` low at T2 of an M1 fetch?”, “Is RAS-before-CAS
    honored?”, “Does boot reach the `©` prompt?”, “Are H/V sync periods within
    spec?”

> **Why this matches the requirement:** these are the “internal functions that
> are already text-compatible for an LLM.” KiCad’s Python/IPC API *is* such a
> surface (text in/out); for SimulIDE you create the equivalent by extending
> its classes and adding a headless control entry point.

### 6.3 The zero-click loop

```
        ┌─────────────────────────────────────────────────────┐
        │  LLM (Claude Code)                                   │
        │  reads JSON/VCD verdicts → edits netlist / sch text  │
        └───────────────┬─────────────────────────────────────┘
                        │ text edits + CLI calls
        ┌───────────────▼───────────────┐     ┌──────────────────┐
        │ KiCad (source of truth)        │     │ SimulIDE          │
        │ .kicad_sch / .kicad_pcb        │◄───►│ circuit XML       │
        │ kicad-cli: ERC/DRC/netlist/    │ §7  │ run → scope/LA →  │
        │ gerbers ; IPC(PCB) ; py edits  │bridge│ VCD export        │
        └───────────────┬───────────────┘     └─────────┬────────┘
                        │ netlist                        │ VCD/JSON
                        ▼                                ▼
                ┌───────────────────────────────────────────────┐
                │ Analysis glue: vcd_to_json + verdict library   │
                │ returns PASS/FAIL + reasons (text/JSON)         │
                └───────────────────────────────────────────────┘
                        ▲                                │
                        └────────── verdicts ────────────┘
```

One iteration: LLM edits canonical netlist/schematic → bridge regenerates the
SimulIDE circuit → `sim.run` → `export_vcd` → `vcd_to_json` + verdicts →
LLM reads text result → corrects. Periodically: `kicad-cli` ERC/DRC and
Gerber plot as sanity gates. **No human click anywhere in the inner loop.**
The human watches SimulIDE’s animated schematic when they *want* to (“vreau să
văd și eu”), but it is not required for progress.

-----

## 7. KiCad ↔ SimulIDE bridge (build this — both ends are text)

**Problem:** SimulIDE doesn’t export KiCad/Gerber; KiCad’s digital-logic
*visualization* is weak compared to SimulIDE’s animated TTL. **Solution:** keep
**one canonical design in KiCad** (so the PCB is automatic) and **generate the
SimulIDE circuit from it** (so the human sees signals and the LLM gets VCD).

- **Canonical direction (recommended):** `KiCad netlist (.net) → SimulIDE circuit XML`. Map each KiCad component (by value/footprint) to a SimulIDE
  component class + parameters (incl. the family timing: LS vs ALS vs HC), and
  each KiCad net to SimulIDE wires/tunnels.
- **Reverse direction (optional):** `SimulIDE XML → KiCad netlist` if you ever
  prefer to draft in SimulIDE; then KiCad imports the netlist for layout.
- Both formats are **plain text/XML**, so the **LLM owns the converter** and
  can extend the mapping table as new Sintez parts are modeled.
- **Component mapping table** is a first-class artifact: `parts_map.json`
  (Soviet part ↔ modern part ↔ KiCad symbol/footprint ↔ SimulIDE class ↔
  timing params). Drives both substitution (§3) and the bridge.

-----

## 8. Concrete tasks (milestones with “done” criteria)

> Execute roughly in order; each task is self-contained enough to hand to a
> sub-agent. “Done” = the stated, machine-checkable criterion.

**T0 — Environment & repo skeleton**

- Install KiCad 9+ (IPC API enabled), SimulIDE (latest dev), ngspice, Python.
- Create repo layout (§9). Commit `parts_map.json` stub.
- **Done:** `python -c "import pcbnew"` works *and* `kicad-cli version` works
  *and* SimulIDE launches and runs a 2-gate test circuit headlessly.

**T1 — Acquire & sanity-check the Sintez schematics**

- Pull schematics/pinouts from the §12 sources; flag the known scan errors;
  reconcile against the re-mastered MCbx pinouts and zx-pk.ru threads.
- **Done:** a `schematics/NOTES.md` listing every block (CPU, decode, DRAM+
  refresh, video arbitration, pixel chain, RGB, audio, tape, TR-DOS) with the
  source used and any discrepancy resolved.

**T2 — Canonical KiCad schematic, block by block**

- Author the schematic in KiCad using **modern Class-1** logic, behavioral
  decisions per §3 for Classes 2–5. Keep Z80 socket for a real Z84C00.
- **Done:** `kicad-cli sch erc` passes (no unconnected/no ERC errors), netlist
  exports cleanly.

**T3 — KiCad→SimulIDE bridge v1**

- Implement `net2sim` using `parts_map.json`. Start with the CPU + memory
  decode + DRAM blocks only.
- **Done:** generated `.sim` loads in SimulIDE; the Z80 (TV80/A-Z80 model)
  fetches from ROM and address/data lines toggle in the scope.

**T4 — LLM command surface (§6.2)**

- Wrap `kicad-cli`/`kicad-python` and the SimulIDE control entry point; build
  `vcd_to_json` + verdict library.
- **Done:** a single script runs sim, exports VCD, and prints JSON verdicts for
  at least: M1 fetch timing, RAS-before-CAS, H/V sync periods.

**T5 — DRAM timing model (К565РУ5)**

- Behavioral DRAM with real РУ5 tRAS/tCAS/tRCD/precharge; refresh via ИЕ7
  counter; correct WAIT generation.
- **Done:** verdict “RAS-before-CAS honored & refresh interleaved” passes;
  swapping to a fast-4164 timing profile *changes* the WAIT verdict (proves the
  model is timing-sensitive, per §2.4).

**T6 — Video chain & RGB**

- КП12 bus arbitration, ИЕ7 sync, К555ИР16 pixel chain @14 MHz, RGB stage
  (ngspice for КТ315/КТ361 levels). Preserve LS timing on the shift chain.
- **Done:** generated framebuffer matches the standard ZX screen layout for a
  known test image; pixel-clock vs CPU-clock asynchrony visible in scope;
  contention tests are confirmed **inapplicable**.

**T7 — Boot validation**

- Run the stock 48K ROM to the `©` prompt in the integrated model.
- **Done:** boot reaches `©`; ZEXDOC passes on the CPU core; Patrik Rak
  contention tests are intentionally **not** run / documented as N/A.

**T8 — PCB layout & fabrication outputs**

- Lay out in KiCad Pcbnew; DRC clean; generate Gerbers/drill/BOM; target a fab
  (e.g. JLCPCB) reachable from Moldova; source the Z84C00 and Class-1 parts.
- **Done:** `kicad-cli pcb drc` clean; Gerbers + BOM produced; a sourcing sheet
  lists in-stock modern equivalents for every line in `parts_map.json`.

**T9 — Full zero-click loop hardening**

- Make the entire iterate→simulate→verify→(layout sanity) loop runnable as one
  command with structured logs; add regression verdicts to CI.
- **Done:** a single `make iterate` (or equivalent) runs end-to-end with no GUI
  interaction and emits a pass/fail report.

-----

## 9. Suggested repository layout

```
sintez2-recon/
├─ SINTEZ2-RECON-SPEC.md        # this file
├─ schematics/
│  ├─ NOTES.md                  # block inventory + scan-error reconciliation
│  └─ sources/                  # downloaded references (uncommitted if large)
├─ kicad/                       # canonical project (.kicad_pro/.kicad_sch/.kicad_pcb)
├─ parts_map.json               # Soviet ↔ modern ↔ KiCad symbol ↔ SimulIDE class ↔ timing
├─ bridge/
│  ├─ net2sim.py                # KiCad netlist → SimulIDE XML
│  └─ sim2net.py                # (optional) reverse
├─ sim/
│  ├─ components/               # extended SimulIDE component classes / subcircuits
│  └─ circuits/                 # generated .sim files
├─ llm/
│  ├─ kicad_cmds.py             # kicad-cli / kicad-python / IPC wrappers
│  ├─ sim_cmds.py               # SimulIDE control + probe/scope/assert
│  ├─ vcd_to_json.py
│  └─ verdicts.py               # M1 timing, RAS/CAS, sync, boot checks
├─ cpu/                         # TV80 / A-Z80 model integration for sim
├─ roms/                        # NOT versioned; user supplies 48K ROM
└─ tests/                       # ZEXDOC/ZEXALL, FUSE tests harness, regressions
```

-----

## 10. Known pitfalls (read before you waste a day)

1. **No contention is a feature.** Do not “fix” missing slowdown. Passing
   Patrik Rak contention tests = wrong machine. Bar is ZEXDOC + boots to `©`.
1. **DRAM timing is analog-ish.** Don’t swap К565РУ5 → generic 4164/SRAM in the
   *model* without flagging it; the WAIT generator was tuned to slow Soviet
   parts (zx-pk.ru repair evidence). Hardware *may* modernize; the model must
   stay honest about which target it represents.
1. **Keep LS on the pixel shift chain.** К555ИР16 (LS) was a deliberate timing
   choice; ALS timing inflates setup margin ~3×.
1. **RGB transistors aren’t 1:1.** КТ315/КТ361 ≠ 2N3904/BC237 for output
   *levels*; real boards had trimmers. Only matters for the analog RGB path.
1. **KiCad schematic scripting is immature (2026).** IPC API in 9.0 is **PCB
   only**; SWIG is deprecated (gone in 11). Plan to edit `.kicad_sch` as text +
   use `kicad-cli` for ERC/netlist/exports. Don’t assume an eeschema Python API.
1. **SimulIDE has no PCB export.** That’s why the bridge exists — KiCad stays
   the fabrication source of truth.
1. **Schematic scans have errors.** Trust the re-mastered MCbx pinouts and
   cross-check zx-pk.ru before committing a net.
1. **14 MHz pixel clock is async to the 3.5 MHz CPU clock.** Visualizing it
   correctly needs sub-T-state resolution — SimulIDE’s 1 ps engine handles it,
   but keep the two clock domains explicitly separate in the model.

-----

## 11. Glossary (quick decode of Soviet part numbers)

|Soviet |Western ≈ |Role in Sintez |
|---|---|---|
|КР1858ВМ1 / UA880D / U880|Z80 |CPU |
|К1533… (e.g. ЛА3) |74ALS… (74ALS10) |fast glue logic |
|К555… (e.g. ИР16) |74LS… (74LS165) |shift registers, slower glue |
|К565РУ5 |4164 |64Kx1 DRAM |
|К1533ИЕ7 |74ALS-class counter |refresh address + H/V sync counters|
|КП12 |bus multiplexer |CPU/video bus arbitration |
|КТ315Г / КТ361Г |(≈) NPN / PNP small-signal|RGB output level shifters |
|К5545АЗ |LM567 |tape tone decoder |

-----

## 12. References

**Sintez 2 hardware / schematics**

- MCbx Old Computer Collection (best English deep-dive; corrected pinouts):
  `https://oldcomputer.info/8bit/sintez/index.htm`
- speccy.info (Russian, most detailed Sintez technical wiki):
  `https://speccy.info/Sintez`
- Sintez-M schematics (predecessor, shares logic design):
  `https://trastero.speccy.org/cosas/JL/Sintez-M/sintez-m.html`
- retropages.hu hardware photos:
  `https://retropages.hu/Gepek/Sintez`
- zx-pk.ru — Russian forum, most active for Soviet clones, repair threads, PCB
  scans, corrected schematics: `https://zx-pk.ru`

**ROM / BASIC internals (stock 48K ROM)**

- “The Complete Spectrum ROM Disassembly” (Logan & O’Hara) PDF:
  `https://primrosebank.net/computers/zxspectrum/docs/CompleteSpectrumROMDisassemblyThe.pdf`
- Annotated `.asm` (reclaimed/prettybasic):
  `https://github.com/reclaimed/prettybasic`
- Geoff Wearmouth annotated disassembly (search online)

**Z80 references**

- `https://z80.info`
- Opcode tables: `https://clrhome.org/tables/`
- Soft cores: TV80 (`https://github.com/hutch31/tv80`), A-Z80
  (`https://github.com/gdevic/A-Z80`)

**KiCad**

- IPC API for add-on developers:
  `https://dev-docs.kicad.org/en/apis-and-binding/ipc-api/for-addon-developers/index.html`
- APIs & bindings (SWIG deprecation notice, removed in v11):
  `https://dev-docs.kicad.org/en/apis-and-binding/index.html`
- `kicad-python` (PyPI): `https://pypi.org/project/kicad-python/`
- SPICE/ngspice integration: `https://www.kicad.org/discover/spice/`
- ngspice-in-KiCad examples (labtroll): `https://github.com/labtroll/KiCad-Simulations`

**SimulIDE**

- Site / features: `https://simulide.com/p/`
- Knowledge base (engine, custom components): `https://simulide.com/p/simulidekb/`
- Component list (scope/VCD/logic analyzer details): `https://simulide.com/p/component-list/`

**RE / debug / floppy ingest**

- Fuse + gdbserver fork: `https://github.com/speccytools/fuse`
- Keir Fraser disk-utilities: `https://github.com/keirf/disk-utilities`
- SAMdisk: `https://simonowen.com/samdisk/`

**Validation suites**

- ZEXDOC/ZEXALL (Frank Cringle) — CPU correctness via CRC
- FUSE test suite (`tests.in` / `tests.expected`) — per-instruction T-states &
  memory accesses
- Patrik Rak tests — contention/floating bus (**N/A for Sintez 2 — must NOT pass**)

-----

## 13. How to start (first three moves for the inheriting agent)

1. Confirm tools (T0). If KiCad’s IPC server or SimulIDE headless run isn’t
   available, say so and propose the text-file fallback path.
1. Build `schematics/NOTES.md` (T1) from §12 sources; surface every place the
   public scans disagree with zx-pk.ru / MCbx before drawing a single net.
1. Stand up `parts_map.json` + `bridge/net2sim.py` against the CPU+decode+DRAM
   blocks (T2→T3) so the zero-click loop has something real to chew on.

Keep the human’s two hard wants in view at all times: **(a) a real Zilog Z80 on
a KiCad-fabricated PCB, and (b) a visual simulator they can watch — driven by an
LLM through text functions, zero-click.**

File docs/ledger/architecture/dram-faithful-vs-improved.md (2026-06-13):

# Q: Faithful К565РУ5 timing vs modern SRAM in hardware?

- **Topic:** architecture ([index](./README.md))
- **Status:** open
- **Opened:** 2026-06-13T10:33:56Z
- **Resolved:** —
- **Decision:** —

## Context

Spec §2.4 / §3 (Class 2) / §10.2. The Sintez WAIT generator was calibrated to
the *slow* Soviet К565РУ5 DRAM timing. A real recreation *may* legitimately
replace DRAM with modern SRAM + glue to drop refresh complexity in hardware —
but the **simulation model must keep РУ5 timing** for bug-for-bug fidelity.
The build target must be decided explicitly: faithful vs "improved & reliable."

## Discussion

### 2026-06-13T10:33:56Z — claude

Opened from the spec. Two separable choices:
1. **Hardware build:** keep DRAM (К565РУ5-equiv 4164) with refresh + WAIT gen,
   OR modernize to SRAM + glue (simpler, more reliable, less authentic).
2. **Simulation model:** MUST model real РУ5 timing (tRAS/tCAS/tRCD/precharge)
   regardless, and a fast-4164 swap must *change* the WAIT verdict (T5 proves
   timing-sensitivity). This part is already settled by decision 0004's
   fidelity stance.

Open part is the hardware target. Recommendation: support **both as build
targets** with the choice recorded per fabrication run; default to faithful
DRAM for the first board to validate the model end-to-end.

## Outcome

<!-- pending owner decision on hardware target -->

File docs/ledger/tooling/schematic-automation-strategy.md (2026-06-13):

# Q: How does the LLM automate KiCad schematics in 2026?

- **Topic:** tooling ([index](./README.md))
- **Status:** resolved
- **Opened:** 2026-06-13T10:33:56Z
- **Resolved:** 2026-06-13T10:33:56Z
- **Decision:** [0003](../../decisions/0003-text-only-llm-control-plane.md)

## Context

Spec §5.1 / §10.5. KiCad's IPC API (9.0+) covers the **PCB editor only**;
schematic-editor support is on the roadmap. The legacy SWIG `pcbnew` bindings
are deprecated and **removed in KiCad 11**.

## Discussion

### 2026-06-13T10:33:56Z — claude

Resolved from the spec's stated reality. Strategy:

- **Schematic:** the LLM edits `.kicad_sch` / `.kicad_pro` **as text** and uses
  `kicad-cli` for ERC, netlist export, and Gerber/BOM plotting. Do **not**
  assume an eeschema Python API.
- **PCB:** use the IPC API via `kicad-python` (placement, footprints, DRC) once
  the netlist exists.
- **Do not** build new work on SWIG `pcbnew` (gone in v11).

## Outcome

Schematic automation = text edits + `kicad-cli`; PCB automation = IPC API.
Captured in decision 0003 and the `llm/` skeleton (`kicad_cmds.py`).
Re-evaluate if/when IPC gains eeschema coverage.

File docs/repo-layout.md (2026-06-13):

# Source repository layout

This repository follows the layout in the spec (`docs/spec/sintez2-recon-spec.md`
§9), with one deviation: **all Markdown lives under `docs/`** per the project
documentation rules (`docs/RULES.md`). The spec itself therefore lives at
`docs/spec/sintez2-recon-spec.md` rather than the repo root.

| Path | Purpose | Spec task |
| --- | --- | --- |
| `docs/` | All documentation, decisions, and the discussion ledger. | — |
| `schematics/` | Block inventory (`NOTES.md`) + downloaded references. | T1 |
| `kicad/` | Canonical KiCad project (source of truth for the PCB). | T2, T8 |
| `parts_map.json` | Soviet ↔ modern ↔ KiCad symbol ↔ SimulIDE class ↔ timing. | T0 |
| `bridge/` | `net2sim.py` (KiCad netlist → SimulIDE XML) + reverse. | T3 |
| `sim/` | Extended SimulIDE component classes + generated circuits. | T5, T6 |
| `llm/` | Text-only LLM command surface + analysis glue. | T4 |
| `cpu/` | TV80 / A-Z80 soft-core integration for simulation. | T3 |
| `roms/` | NOT versioned; user supplies the stock 48K ROM. | — |
| `tests/` | ZEXDOC/ZEXALL, FUSE harness, regression verdicts. | T7, T9 |

All code directories are currently empty skeletons; they are populated as the
T0–T9 milestones are executed. Track progress in the ledger
(`docs/ledger/`).

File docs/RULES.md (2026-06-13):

# Documentation & Ledger Rules

These rules govern how documentation and the discussion ledger are written
and maintained in this repository. They are intentionally short. When in
doubt, prefer clarity and consistency over cleverness.

## 1. Where things live

- All documentation is Markdown under `docs/`.
- No documentation Markdown lives outside `docs/`, with one exception:
  the top-level `README.md`, which stays minimal and links into `docs/`.
- The discussion ledger lives under `docs/ledger/`.
- Reusable templates live under `docs/templates/`.

## 2. Language

- **Every written record is in English.** Discussions may happen in any
  language (e.g. Romanian), but what gets committed is always English.
- Translate faithfully; do not summarize away meaning when translating.

## 3. Naming

- Files and folders use `kebab-case`: lowercase ASCII, words joined by `-`.
  - Good: `data-ingestion.md`, `why-postgres.md`
  - Bad: `Data Ingestion.md`, `whyPostgres.md`
- File names describe the content, not the date. Dates live inside the file.

## 4. Timestamps

- All timestamps are **UTC** in **ISO 8601**: `YYYY-MM-DDTHH:MM:SSZ`.
  - Example: `2026-06-13T10:20:11Z`.
- Dates without a time use `YYYY-MM-DD`.

## 5. The ledger

The ledger is an append-mostly record of discussions, grouped two ways:

1. **By topic** — one folder per topic under `docs/ledger/`.
2. **By question** — one Markdown file per question inside a topic folder.

Rules:

- One question per file. A file holds the full discussion of that one
  question as a chronological list of timestamped entries.
- **Append, don't rewrite.** Add new entries at the bottom. Do not edit or
  delete past entries; if something was wrong, add a correcting entry.
- Each entry records: timestamp, who/what said it, and the content.
- When a question is settled, set its `Status` to `resolved` in the header
  and, if a decision came out of it, link the decision record.
- Keep a `docs/ledger/README.md` index of topics and open questions.

See `docs/ledger/README.md` for the exact structure and `docs/templates/`
for the entry formats.

## 6. Decisions

- Decisions of lasting consequence get a decision record (ADR-style) under
  `docs/decisions/`, created from `docs/templates/decision-record.md`.
- A decision record is numbered (`0001-...`, `0002-...`) and never deleted;
  superseded ones are marked `superseded` and link to their replacement.

## 7. General writing

- One sentence per line is allowed and encouraged for clean diffs, but not
  required.
- Prefer relative links between docs so they survive moves and clones.
- Keep line length reasonable (~80–100 cols) for readability in diffs.

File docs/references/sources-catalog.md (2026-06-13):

# Primary-source materials catalog

Authoritative reference assets supplied by the project owner. The binaries live
under [`reference/`](../../reference/) at the repo root (committed so they
survive the ephemeral container); this catalog records what each one is, its
provenance hash, and what we learned from it.

> Language note: source documents are in Russian; all extracted notes here are
> in English per `docs/RULES.md`.

## Inventory

| File | Type | What it is | SHA-256 (short) |
| --- | --- | --- | --- |
| `reference/schematics/sintez2-schematic.pdf` | PDF, 1 sheet (2040×1560 pt) | **"ПРОЦЕССОР «СИНТЕЗ-2» — СХЕМА ЭЛЕКТРИЧЕСКАЯ ПРИНЦИПИАЛЬНАЯ, ПРИЛОЖЕНИЕ 2."** Clean scan of the full mainboard schematic with a component table down the right edge (the BOM). | `1d8cf4f1…` |
| `reference/schematics/sintez2-original.pdf` | PDF, 1 sheet (A4) | Re-drawn / colorized version of the same mainboard schematic (KiCad-style nets). Useful cross-check against the scan. | `b37f7be2…` |
| `reference/photos/betadisk-original.png` | PNG 1200×1600 | Photo of the **original Beta Disk interface board** (TR-DOS controller), board marking `СМП59-96Г-16-2 8903`. | `a7975b58…` |
| `reference/photos/sintez128.jpg` | JPEG 560×920 | **"Расширение памяти Синтеза-2 до 128 кб"** — ©1997 PREDATOR/FAST Group writeup of the 128 KB RAM expansion mod, including its schematic. | `d2e74c1b…` |
| `reference/pinouts/video-pinout.png` | PNG 921×2048 | Screenshot (pvsm.ru) of a **SCART / Jack video output modification** with connector pinouts (RGB + sync + cassette). | `849fa38f…` |
| `reference/board/sintez2-element-placement.jpg` | JPEG (from 5144×3183 scan) | **"ПРИЛОЖЕНИЕ 2", page 25 — element-placement / silkscreen layout** of the mainboard. Locates every Dxx package physically; the single artifact that resolved the open designators D37/D44/D49/D50/D51. From the Muravyev Google-Drive set. | `99947620…` |
| `reference/schematics/sintez2-power-supply.jpg` | JPEG (from 5100×2989 scan) | **PSU schematic** — linear: toroidal transformer + LM7805, K50-24 main smoothing cap, K50-35 post-regulator. | `770eb3e2…` |
| `reference/schematics/sintez2-keyboard.jpg` | JPEG (from 5021×2879 scan) | **Keyboard schematic** — 8×5 = 40-key matrix (5-layer membrane); two Sinclair-joystick ports duplicating keypad 1–5 / 6–0. | `7ffcda00…` |
| `reference/manual/sintez2-user-manual.pdf` | PDF, 11 pages | **Full factory user manual** (signal characteristics, TV-mod instructions, keyboard schematic, PSU schematic, acceptance certificate dated March 1992). | `34e68014…` |

| `reference/schematics/betadisk-controller-bdi.pdf` | PDF, 2 pp (raster) | **"КОНТРОЛЛЕР ДИСКОВОДА «Ленинград 2»"** — the Beta-Disk / TR-DOS controller schematic (WD1793-class FDC + ИР16/ИЕ10/ТМ9 glue, system connector, board layout). Fills the TR-DOS block that previously had only a board photo. From the zx-pk t-29397 mods thread. | `48e7a4c4…` |
| `reference/schematics/sintez2-128k-ay-mod.pdf` | PDF, 7 pp (raster) | **128 KB RAM + AY sound-processor expansion** schematics (Odessa boards, Leningrad-2 origin). Feeds the optional banking + audio paths. | `bce3afa7…` |
| `reference/schematics/sintez2-mainboard-photo.jpg` | JPEG (from 4032×3024) | Photographed copy of the Sintez-2 mainboard schematic — independent cross-check of the canonical scan. | `6b68875e…` |

> Full-resolution originals of the rows above (incl. the 8283×6956
> `Schematic_Full.png`, the raw manual PNGs, and the author's EasyEDA keyboard
> redesign) are kept locally under `schematics/sources/sintez2-drive-2022/`
> (gitignored per repo policy — large reference downloads are not versioned).
> The ROM, captured as an audio tape signal `roms/sintez2-rom.wav`, and the
> Sintez-**M** ROM dump `roms/sintez-M.rom` (José Leandro, 2007), also live
> under the gitignored `roms/`.

## Key facts extracted

### Mainboard schematic (`sintez2-schematic.pdf`)
- Confirms the discrete-TTL design (К555 / К1533 families), matching the spec.
- Right-edge component table is the canonical BOM — to be transcribed in full
  during milestone T1 (high-resolution renders are reproducible via PyMuPDF;
  see `schematics/NOTES.md`).

### Beta Disk / TR-DOS controller (`betadisk-original.png`)
- FDC is **КР1818ВГ93 ≈ WD1793** (Western FDC), per the spec's TR-DOS section.
- Carries a ROM (TR-DOS) + К555 / КР1533 glue logic and bank-switch control.
- Board ident: `СМП59-96Г-16-2`, date code `8903` (1989, week 03) — consistent
  with the ~1989 manufacture date.

### 128 KB expansion (`sintez128.jpg`)
- Adds **port `#7FFD` paging** (ZX-128-style) to expand the stock 48 K to 128 K.
- Mod chips: **К555ТМ9** (≈74LS175 quad D latch — the paging register),
  **К1533КП11** (≈74ALS257 mux), **К555ЛЛ1** (≈74LS32 OR),
  **К1533ЛА3** (≈74ALS00 NAND).
- Documents screen selection and full system-port blocking behavior.
- Feeds the open question
  [`architecture/bank-switching-ram-size`](../ledger/architecture/bank-switching-ram-size.md).

### Video output / SCART mod (`video-pinout.png`)
- RGB + sync wiring to SCART and a 3.5 mm jack; cassette connector pinout.
- Note: a **200 Ω resistor on the sync channel**; dropping it to **100 Ω causes
  loss of color** — an analog-level detail relevant to the RGB stage (spec §2.3).

### Element-placement layout + power table (`sintez2-element-placement.jpg` + schematic)
- **Physically locates all 51 ICs.** Resolved the previously-open designators:
  - **D37** — small DIP, left-centre near D9/C16 (a 14-pin gate).
  - **D44** — wide DIP, top-centre by connector X4 + R31/R32 (tape/IO area), 20-pin.
  - **D49** — wide DIP, bottom-left near D17, 20-pin.
  - **D50** — wide DIP, top-right by X6/X9, 20-pin (the disk/IO address buffer).
  - **D51** — wide DIP, top-left by X1/X2, 20-pin.
- The **"Питание микросхем" (chip-power) table** down the schematic's right edge
  gives the package size of every IC by its power pins (authoritative inventory):

  | Power (+5 V / GND) | Pins | Designators |
  | --- | --- | --- |
  | 11 / 29 | 40 | D6 (Z80) |
  | 8 / 16 | 16 | D28…D35 (DRAM К565РУ5) |
  | 1,27,28 / 14 | 28 | D36 (ROM 27128) |
  | 20 / 10 | 20 | D38, D42…D44, D48, D50, D51 (octal latch/buffer) |
  | 16 / 8 | 16 | D2…D5, D11, D19, D23…D26, D46, D47 (counters/muxes) |
  | 14 / 7 | 14 | D1, D7…D10, D12…D18, D20…D22, D27, D37, D39…D41, D45 (gates) |

  > ⚠ **Discrepancy to reconcile:** the table places the pixel/colour shift
  > registers **D39–D41 and D45 in the 14-pin group**, but the spec/earlier
  > reads call them К555ИР16 (a 16-pin part). Re-check the ИР16 symbol vs. a
  > 14-pin shift register before freezing the BOM. Pin-count is from the scan;
  > the type letter must come from the schematic symbol.

### Connector pinouts (schematic right-edge tables)
- **X7 "TV":** FV=13, HS=16, VS=7, Y=11, CSYNC=5, +5 V=1; B=3, R=5, G=4,
  SYNC=2, SOUND=1 (pins 6,7 = GND). Matches the video-output stage (spec §2.3).
- **X8.1 / X8.2 (expansion bus):** full Z80 bus on the card edge — A0–A15 plus
  CLK, RESET, WAIT, INT, NMI, M1, MREQ, IORQ, RFSH, RD, WR. This is the
  **SNP58-64** connector the manual/video call out ("all CPU pins + power").

### Video transcript corroboration (`transcripts/sintez2-repair-short-*.txt`)
- **CPU = КР1858ВМ1**, fitted in place of a Z80A ("higher speed", per the
  manual page read on camera). Crystal **14.3 MHz ÷ 4 ≈ 3.575 MHz** CPU clock —
  note this is master ÷4, refining the spec's "14 MHz = 2× CPU" wording.
- **ROM is a UV-erasable EPROM** (window sealed on camera) → confirms the
  27128-class D36.
- **PSU:** linear, toroidal transformer + LM7805; a factory **39 Ω resistor**
  to ground biases the output to ~5.35 V (intentional). Caps K50-24 / K50-35.
- **RGB trimmers = SP3-38A**; **piezo buzzer = ЗП-3** (support parts present on
  board even when the buzzer itself was omitted at the factory).
- Keyboard: **5-layer membrane, 8×5 = 40 keys**; two Sinclair joystick ports
  (1–5 and 6–0), **no Kempston** (would need a register chip). Built **03/1992**.

### KiCad-source search (owner request — outcome)
- The colorized redraw `sintez2-original.pdf` was produced by **Eeschema (KiCad)
  on 2012-11-09** (PostScript title `Sintez_II_orig.ps`) — so a KiCad redraw
  exists, but its **`.sch` source is not published anywhere reachable**: not on
  GitHub, not on habr, not in the zx-pk t-240/27280 threads, not in José
  Leandro's trastero set (that's Sintez-M, a JPEG). We only have the exported
  PDF (already vector, re-renderable at any DPI — `pdftocairo -svg/-r 600`).
- **Useful adjacent KiCad assets found** (for authoring our own T2 schematic):
  `github.com/alvaroalea/8bits_kicad_libraries` (К155/К555/К1533 + Spectrum
  symbols) and `github.com/krzys9876/ZX_Spectrum_diy` (full DIY Spectrum in
  KiCad). Per the spec, **KiCad is our source of truth**, so we author the
  canonical `.kicad_sch` fresh rather than inherit the 2012 file.

## Online sources (web)

Not committed binaries — links discovered/used during research. External content;
treat as secondary to the committed primary sources above.

| Link | Type | Notes |
| --- | --- | --- |
| https://youtu.be/0_mFe5sdLsc | Video (YouTube) | **Dmitry Muravyev**, "Импортозамещение" (2022-07-30) — Sintez-2 revival, supplied by the project owner. Auto-caption transcript saved at `docs/references/transcripts/sintez2-repair-short-{ru,en}.txt`. |
| https://youtu.be/hP12QHBkZDM | Video (YouTube) | Muravyev's **full 36-min restoration** of the same unit (no captions available; visual board close-ups only). |
| https://drive.google.com/drive/folders/1PBfw-9AaOMJzl4I1Lhckx7aKGpiDoIub | Google Drive | **Muravyev's reference set** linked in the video description: full schematic scan, board element-placement, PSU + keyboard schematics, 11-page user manual, ROM-as-audio, and his EasyEDA keyboard redesign. Mirrored into the repo (see inventory above). |
| https://trastero.speccy.org/cosas/JL/Sintez-M/sintez-m.html | Page | **José Leandro Novellan** (2007): Sintez-**M** (predecessor) schematic JPEG + a 16 KB `sintez-M.rom` dump. The M shares the logic design; not the same board. |
| https://zx-pk.ru/threads/29397-dorabotki-klona-sintez-2.html | Forum | **"Доработки клона SINTEZ 2"** (user *jil2*, 2018) — owner of a Sintez-2 with Odessa 128K + AY + Beta-Disk(PLL) mods originally for Leningrad-2; discusses INT-signal fix and port #FF. Found via Yandex during the forum dig. |
| https://cloud.mail.ru/public/MwCe/wVycd7nSd | File host | **SCHEMES.zip** (24 MB) linked from thread 29397: BDI, 128K+AY, Leningrad-2 PLL schematics (photos + raster PDFs). Mirrored into the repo. **No KiCad source here — all raster.** |
| https://habr.com/ru/articles/222569/ | Article | "Синтез-2 — отечественный клон ZX-Spectrum"; source of the 1920×1278 board photo (`reference/photos/sintez2-board-habr.jpg`) and rear-panel shot. |
| https://zx-pk.ru/threads/27280-remont-sintez-2.html | Forum | "Ремонт Синтез 2"; text corroborates D39–D42 / КР1533КП12 / ИР16; 27128 ROM → W27C512 flash. |
| https://zx-pk.ru/archive/index.php/t-240.html | Forum | Sintez-2 schematic/repair; 128K mod lifts 3 pins of the КП12 A14/A15 mux. |
| https://priborazbor.ru/sintez-2-sintez-evm-kompyuter-igrovoj/ | Page | Scrap/teardown; rough IC count (~18 DRAM + 17 155/1533 + Z80 + 17 КТ315) and a 696px top-view board photo. |

> Reachability note (this environment): image CDNs (habrastorage, wp.com,
> zx-pk attachments) are fetchable; **web.archive.org and archive.ph are blocked**
> by the egress policy. No higher-res board photo than 1920px exists online.

## Reproducing the renders

PDFs render with PyMuPDF (no poppler needed):

```python
import fitz
d = fitz.open("reference/schematics/sintez2-schematic.pdf")
pix = d[0].get_pixmap(matrix=fitz.Matrix(400/72, 400/72),
                      clip=fitz.Rect(1470, 40, 2040, 1300))  # right-edge BOM
pix.save("bom.png")
```

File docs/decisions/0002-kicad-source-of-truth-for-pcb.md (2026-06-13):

# 0002 — KiCad is the source of truth for the PCB

- **Status:** accepted
- **Date:** 2026-06-13
- **Deciders:** project owner (via spec)
- **Related question:** [tooling/schematic-automation-strategy](../ledger/tooling/schematic-automation-strategy.md)

## Context

The board is fabricated by ordering from Gerbers. SimulIDE — the visual
playground — has no PCB/Gerber export. We need one canonical design that
produces the fab outputs.

## Decision

**KiCad is the single canonical design and the source of truth for the PCB.**
Gerbers/drill/BOM are produced from KiCad. SimulIDE circuits are *generated
from* the KiCad netlist via the bridge (`bridge/net2sim.py`), never the other
way around for fabrication purposes.

## Consequences

- Positive: no "export to KiCad" step; fabrication is automatic from the hub.
- Trade-offs: KiCad's digital-logic visualization is weak → hence SimulIDE +
  the bridge (decision 0003 / spec §7).
- Follow-ups: keep `parts_map.json` as the mapping that drives the bridge.

## Alternatives considered

- **Draft in SimulIDE, import to KiCad** — allowed as optional reverse path,
  but KiCad remains authoritative for the PCB.

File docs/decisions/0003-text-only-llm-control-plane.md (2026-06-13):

# 0003 — Text-only, zero-click LLM control plane (no GUI automation)

- **Status:** accepted
- **Date:** 2026-06-13
- **Deciders:** project owner (via spec)
- **Related question:** [tooling/schematic-automation-strategy](../ledger/tooling/schematic-automation-strategy.md)

## Context

The owner wants an LLM to own the full iterate→simulate→verify→layout loop
with zero clicks. GUI pixel-puppeting (Playwright/Selenium) is brittle and
forbidden.

## Decision

Everything the LLM touches is **text**: `.kicad_sch`, `.kicad_pcb`, KiCad
netlists, SimulIDE circuit XML, VCD waveforms, JSON. We **extend the
open-source tools' internal classes/APIs** to expose exactly the verbs the LLM
needs, each returning parseable text/JSON (spec §6.2). **GUI automation is
forbidden.**

## Consequences

- Positive: robust, scriptable, CI-able; human watches SimulIDE only when they
  want to ("vreau să văd și eu"), never required for progress.
- Trade-offs: SimulIDE needs a headless control entry point we must build.
- Follow-ups: build `llm/` command surface (T4) and the bridge (T3).

## Alternatives considered

- **GUI automation** — rejected: brittle, against the core requirement.

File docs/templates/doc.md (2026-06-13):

<!--
Template: generic document.
Copy this file into docs/, rename to kebab-case, and fill it in.
Delete these comments before committing.
-->

# <Document title>

- **Status:** draft | active | deprecated
- **Last updated:** YYYY-MM-DD
- **Owner:** <name or role>

## Summary

One short paragraph: what this document is about and who should read it.

## Details

The body of the document.

## References

- Related docs, ledger questions, or decision records.

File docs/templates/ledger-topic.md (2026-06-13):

<!--
Template: ledger TOPIC index.
A topic is a folder under docs/ledger/. This file is that folder's README.md.
Copy into docs/ledger/<topic>/README.md and fill it in.
Delete these comments before committing.
-->

# Topic: <topic name>

- **Created:** YYYY-MM-DD
- **Status:** active | dormant | closed

## Scope

One short paragraph describing what belongs in this topic.

## Questions

| Question file | Title | Status | Opened | Resolved |
| --- | --- | --- | --- | --- |
| [`<file>.md`](./<file>.md) | <short title> | open / resolved | YYYY-MM-DD | YYYY-MM-DD or — |

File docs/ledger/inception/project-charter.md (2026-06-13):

# Q: What are we building and what are the hard constraints?

- **Topic:** inception ([index](./README.md))
- **Status:** resolved
- **Opened:** 2026-06-13T10:33:56Z
- **Resolved:** 2026-06-13T10:33:56Z
- **Decision:** [0001](../../decisions/0001-keep-real-zilog-z80.md),
  [0002](../../decisions/0002-kicad-source-of-truth-for-pcb.md),
  [0003](../../decisions/0003-text-only-llm-control-plane.md),
  [0004](../../decisions/0004-fidelity-no-memory-contention.md)

## Context

A technical specification was handed off as the project inception document:
*Sintez 2 — Modern Reconstruction & LLM-Driven Visual Simulation*
(`docs/spec/sintez2-recon-spec.md`).

## Discussion

### 2026-06-13T10:33:56Z — user

Provided the full spec and instructed: use it as the tech spec and project
inception.

### 2026-06-13T10:33:56Z — claude

Registered the spec as the canonical document. Extracted the charter:

**Three deliverables, one loop:**
1. A modern recreation of the **Sintez 2** — a Soviet/Moldovan ZX Spectrum 48K
   clone built from discrete TTL (no ULA), rebuilt with modern sourceable parts
   while keeping a **real Zilog Z80**.
2. A **visual open-source electronics simulator** (SimulIDE) where the owner
   can watch signals propagate (buses, /MREQ, RAS/CAS, pixel clock, RGB).
3. An **LLM puppeteering layer**: extend the open-source tools' classes/APIs
   with text-friendly functions the LLM drives fully automatically, zero-click.

**Non-negotiable constraints (→ decision records):**
- Keep a genuine Zilog Z80 (Z84C00) in the physical build — [0001](../../decisions/0001-keep-real-zilog-z80.md).
- KiCad is the source of truth for the PCB — [0002](../../decisions/0002-kicad-source-of-truth-for-pcb.md).
- Everything the LLM touches is text; no GUI automation — [0003](../../decisions/0003-text-only-llm-control-plane.md).
- Fidelity over improvement: **no memory contention** — [0004](../../decisions/0004-fidelity-no-memory-contention.md).

Also created the §9 repository skeleton, `parts_map.json` stub,
`schematics/NOTES.md` stub (T1), and opened follow-up questions under the
`architecture`, `tooling`, and `sourcing` topics.

## Outcome

Project formally inaugurated. The spec is canonical
(`docs/spec/sintez2-recon-spec.md`); the four hard constraints are recorded as
accepted decisions; the repo skeleton and open questions are in place. Next
concrete work is milestones T0→T3 (environment, schematic notes, parts map +
bridge against CPU/decode/DRAM).

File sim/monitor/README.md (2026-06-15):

# sim/monitor — "monitor output" of the simulation (headless screenshot)

The Sintez-2 video hardware displays exactly the screen-RAM contents
(0x4000–0x57FF bitmap + 0x5800–0x5AFF attributes). So a connected monitor's image
can be reconstructed **zero-click, headless** by rendering that RAM — no SimulIDE
GUI, no screen capture needed.

`scr2png.py` renders a 6912-byte ZX screen dump to a colour PNG (ZX palette, ×3).

## Pipeline
```bash
tests/boot/boot                      # boots the ROM, dumps /tmp/s4work/screen.scr
.venv/bin/python sim/monitor/scr2png.py /tmp/s4work/screen.scr sim/monitor/boot-screen.png
```

## boot-screen.png — the reconstructed machine's video output at boot
Shows the ZX sign-on screen with **"© 1990 Intercomplex"** — the clone ROM in
`roms/sintez-M.rom`. This is the "monitor as if connected to our electronic
simulation" the project wants, produced from the simulated screen RAM.

## On SimulIDE extensibility (researched 2026-06-15)
- SimulIDE's scripting language is **AngelScript** (`.as` component scripts:
  `getPin()/getPort()/setVoltage()`, `setup()/reset()/voltChanged()` callbacks,
  RAM/ROM/interrupt access). Good for **behavioural** parts (e.g. a К565РУ5 DRAM
  model) — but scripted components **cannot draw graphics** ("custom draw" is only a
  forum feature-request).
- A true in-SimulIDE raster/CRT monitor would be a **C++ built-in/modular component**
  compiled into SimulIDE's (AGPL) source — the spec's "extend its classes" path.
- Until/unless that's built, this RAM→PNG renderer is the practical monitor view.

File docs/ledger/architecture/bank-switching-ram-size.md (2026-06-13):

# Q: How much RAM / what bank-switching scheme?

- **Topic:** architecture ([index](./README.md))
- **Status:** open
- **Opened:** 2026-06-13T10:33:56Z
- **Resolved:** —
- **Decision:** —

## Context

Spec §2.2. The Z80 natively addresses 64 KB. The stock 48K layout is the
baseline. If the modern build wants more RAM, it is paged through a window via
latches/registers holding a wider bank address. 128–512 KB is typical; >1 MB is
possible but software-impractical.

## Discussion

### 2026-06-13T10:33:56Z — claude

Opened from the spec. Baseline = stock 48K (no banking) to reach the `©` boot
and run standard software. Optional extension: 128 KB (ZX-128-like paging) or
more. Recommendation: ship **48K faithful first**; treat banked RAM as an
opt-in later variant so it doesn't complicate the initial fidelity validation.

### 2026-06-13T11:31:15Z — claude

New evidence: the owner supplied a ©1997 PREDATOR/FAST Group writeup,
**"Расширение памяти Синтеза-2 до 128 кб"** (`reference/photos/sintez128.jpg`),
documenting a real **128 KB expansion** for this exact machine via **port
`#7FFD` paging** (ZX-128 style). Mod chips: К555ТМ9 (≈74LS175 paging latch),
К1533КП11 (≈74ALS257 mux), К555ЛЛ1 (≈74LS32), К1533ЛА3 (≈74ALS00). This makes
128 KB the natural, historically-attested banked variant.

Refined recommendation: **48 K stock as the faithful baseline** (first build,
boot-to-`©` validation), with the **#7FFD 128 KB expansion as the documented
opt-in variant** modeled from this writeup. Decision still pending owner sign-off.

### 2026-06-13T14:05:00Z — claude

Forum corroboration (zx-pk.ru t-240, `Sintez-128.zip`): the 128K mod **lifts 3
pins of the КП12 address mux that carry A14/A15** and feeds A14'/A15' from the
paging logic, plus a **2nd-storey row of К565РУ5 with CAS split** across levels.
This matches our extracted **D26 КП12 = A9/A13/A14/A15 mux** — i.e. the stock
board already routes A14/A15 through a КП12, and the 128K mod intercepts exactly
there. Strengthens the "#7FFD opt-in variant" plan with a concrete tap point.

## Outcome

<!-- pending owner sign-off: 48K baseline + optional #7FFD 128K variant -->

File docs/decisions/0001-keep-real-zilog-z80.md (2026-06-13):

# 0001 — Keep a genuine Zilog Z80 in the physical build

- **Status:** accepted
- **Date:** 2026-06-13
- **Deciders:** project owner (via spec)
- **Related question:** [sourcing/z80-part-selection](../ledger/sourcing/z80-part-selection.md)

## Context

The Sintez 2 is a discrete-TTL ZX Spectrum clone. The owner's first hard want
is a real Zilog Z80 on the fabricated board, not a soft core. The original used
a Soviet UA880D / КР1858ВМ1 Z80-compatible part.

## Decision

The physical build uses a **genuine modern CMOS Zilog Z80 (Z84C00 family)**.
In simulation, where a physical chip cannot be co-simulated, we use a
behavioral soft core (TV80 / A-Z80). An FPGA soft core is only a fallback if
a physical Z80 ever becomes unavailable.

## Consequences

- Positive: faithful to the machine; Z84C00 is in production and sourceable.
- Trade-offs: soft core in sim must match Z80 behavior (validated by ZEXDOC).
- Follow-ups: source Z84C00 (€3–5, Mouser/Digi-Key/TME) → see T8.

## Alternatives considered

- **Soviet КР1858ВМ1 / U880** — authentic but harder to source; kept as option.
- **Z180/Z280 with MMU** — rejected; changes the machine, owner wants Z80.

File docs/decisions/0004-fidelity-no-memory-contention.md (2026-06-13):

# 0004 — Fidelity over improvement: no memory contention

- **Status:** accepted
- **Date:** 2026-06-13
- **Deciders:** project owner (via spec)
- **Related question:** [architecture/dram-faithful-vs-improved](../ledger/architecture/dram-faithful-vs-improved.md)

## Context

A real Spectrum's ULA disputes the bus, causing memory contention. The Sintez 2
has **no ULA** (all discrete TTL), so there is **no memory contention** — the
Z80 runs a constant 3.5 MHz with canonical T-states. This is the single most
important behavioral fact about the machine.

## Decision

The model is **faithful, not "improved."** It uses canonical T-state counts
with **no contention table**. Software depending on tight contention timing
(multicolor demos, Nirvana, rainbow-border) **must not run** in our model, just
as it does not on real hardware. The validation bar is **ZEXDOC + boots to the
`©` prompt**. Patrik Rak contention tests are **N/A and must NOT pass** —
passing them means the model is a wrong machine.

## Consequences

- Positive: bug-for-bug fidelity to the actual Sintez 2.
- Trade-offs: some famous ZX demos won't run — this is correct, not a defect.
- Follow-ups: DRAM timing model keeps real К565РУ5 timing (T5); document the
  faithful-vs-improved hardware target separately (see related question).

## Alternatives considered

- **Add contention for broader software compat** — rejected: wrong machine.

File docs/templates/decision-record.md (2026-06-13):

<!--
Template: decision record (ADR-style).
Copy into docs/decisions/, name it NNNN-short-title.md (e.g. 0001-use-postgres.md).
Delete these comments before committing.
-->

# NNNN — <Decision title>

- **Status:** proposed | accepted | rejected | superseded
- **Date:** YYYY-MM-DD
- **Deciders:** <names or roles>
- **Related question:** <link to docs/ledger/...> (optional)
- **Supersedes / superseded by:** <link> (optional)

## Context

What is the problem or force that requires a decision? What constraints apply?

## Decision

The decision, stated plainly in one or two sentences.

## Consequences

- Positive: ...
- Negative / trade-offs: ...
- Follow-ups: ...

## Alternatives considered

- **<Option A>** — why not chosen.
- **<Option B>** — why not chosen.

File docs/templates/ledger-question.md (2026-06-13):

<!--
Template: ledger QUESTION file.
One question per file. Copy into docs/ledger/<topic>/<question>.md.
Append new entries at the bottom; never rewrite past entries.
Delete these comments before committing.
-->

# Q: <the question, phrased as a question>

- **Topic:** <topic name> ([index](./README.md))
- **Status:** open | resolved | parked
- **Opened:** YYYY-MM-DDTHH:MM:SSZ
- **Resolved:** YYYY-MM-DDTHH:MM:SSZ or —
- **Decision:** <link to docs/decisions/...> or —

## Context

Why this question came up. One short paragraph.

## Discussion

<!-- Append one block per entry. Newest at the bottom. -->

### YYYY-MM-DDTHH:MM:SSZ — <author>

The point made at this timestamp.

### YYYY-MM-DDTHH:MM:SSZ — <author>

The next point.

## Outcome

<!-- Fill in when Status becomes resolved. -->

The conclusion, and a link to any decision record or doc that resulted.

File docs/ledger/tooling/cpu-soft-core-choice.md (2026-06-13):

# Q: TV80 or A-Z80 for the simulation core?

- **Topic:** tooling ([index](./README.md))
- **Status:** open
- **Opened:** 2026-06-13T10:33:56Z
- **Resolved:** —
- **Decision:** —

## Context

Spec §4 / §5.4. A physical Z80 can't be co-simulated, so simulation always uses
a behavioral soft core. Two open-source candidates: **TV80**
(`github.com/hutch31/tv80`) and **A-Z80** (`github.com/gdevic/A-Z80`).

## Discussion

### 2026-06-13T10:33:56Z — claude

Opened from the spec. Selection criteria: ZEXDOC correctness, accurate
per-instruction T-states (FUSE suite), ease of integration into the SimulIDE
model, and clean reset/M1 timing for the verdict library (T4). A-Z80 is a
gate-level reconstruction (very accurate timing); TV80 is a compact synthesizable
core (easier to embed). Decision deferred until T3 integration trials.

## Outcome

<!-- pending integration trial in T3 -->

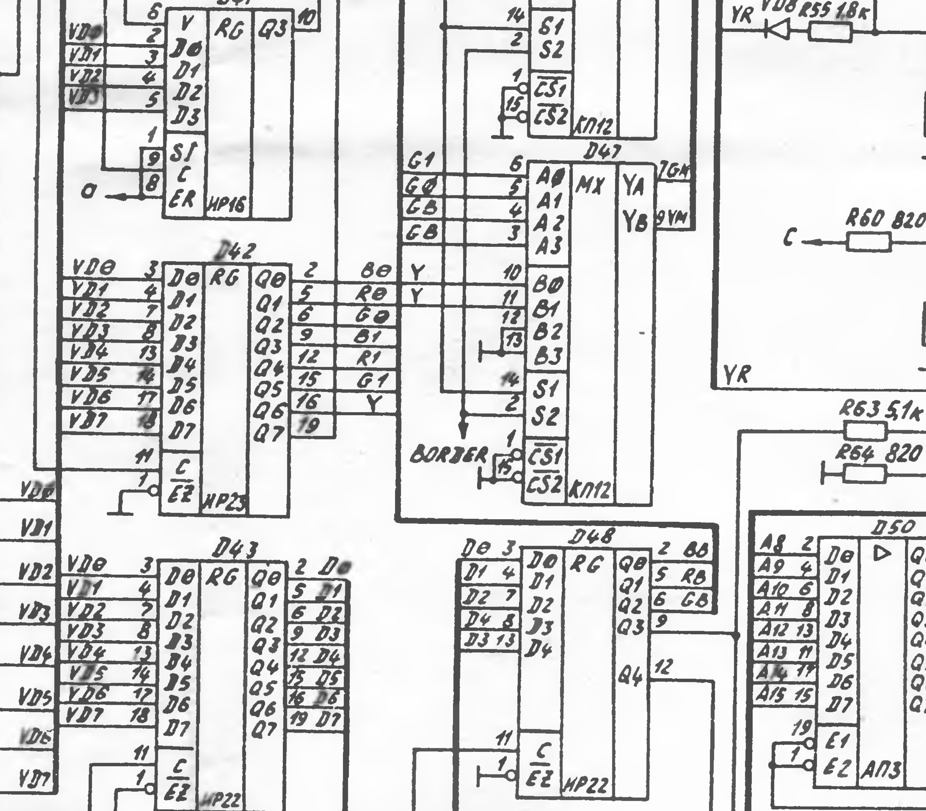
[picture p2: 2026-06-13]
schematics/tiles/t_r2c3.png

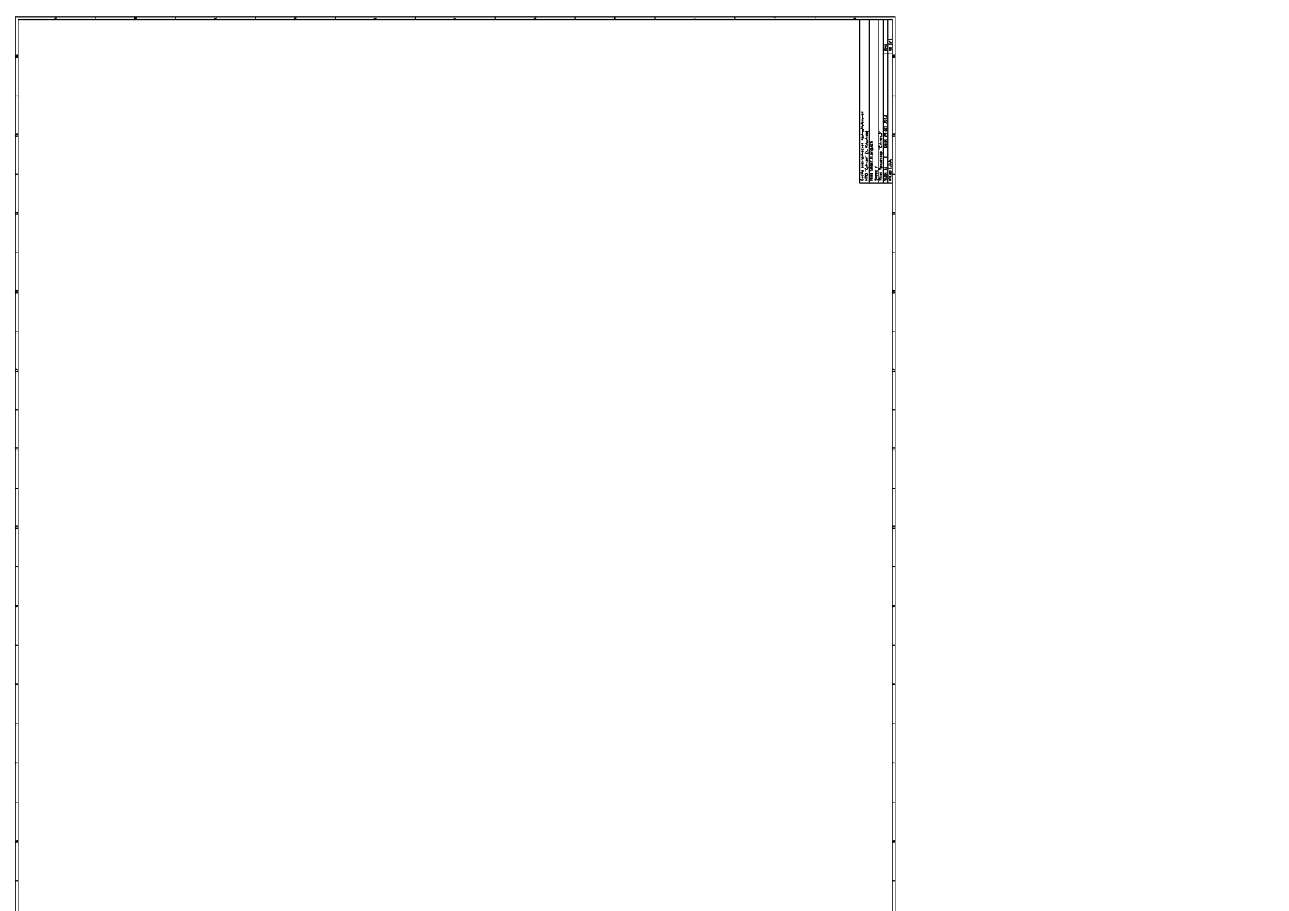
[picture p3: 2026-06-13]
schematics/tiles-color/layers/layer_black.png

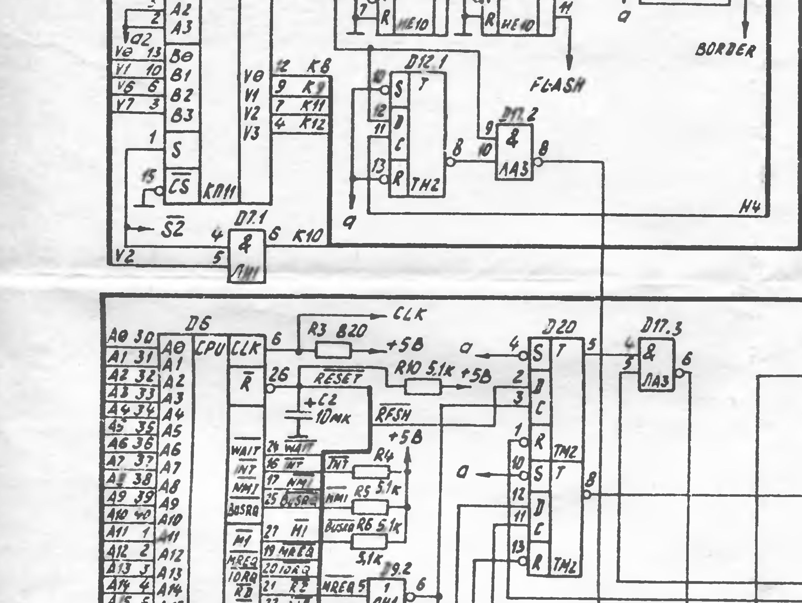
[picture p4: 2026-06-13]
schematics/tiles/t_r3c1.png

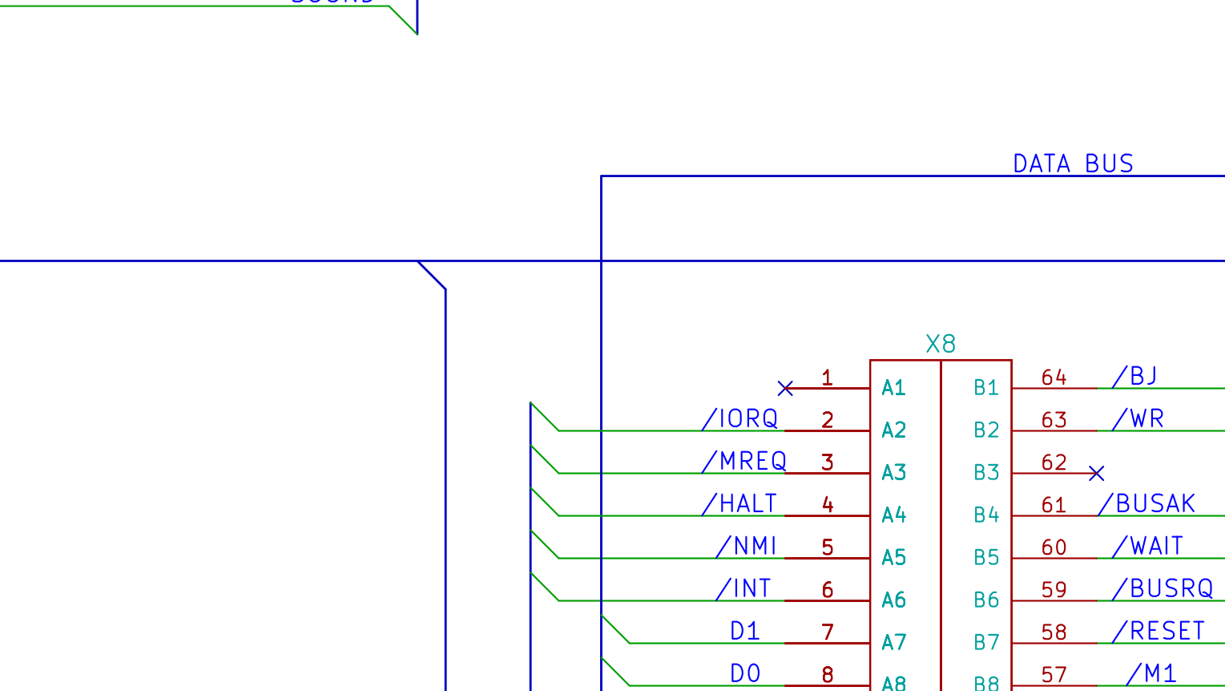
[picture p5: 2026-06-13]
schematics/tiles-color/zoom/zoom_x8.png

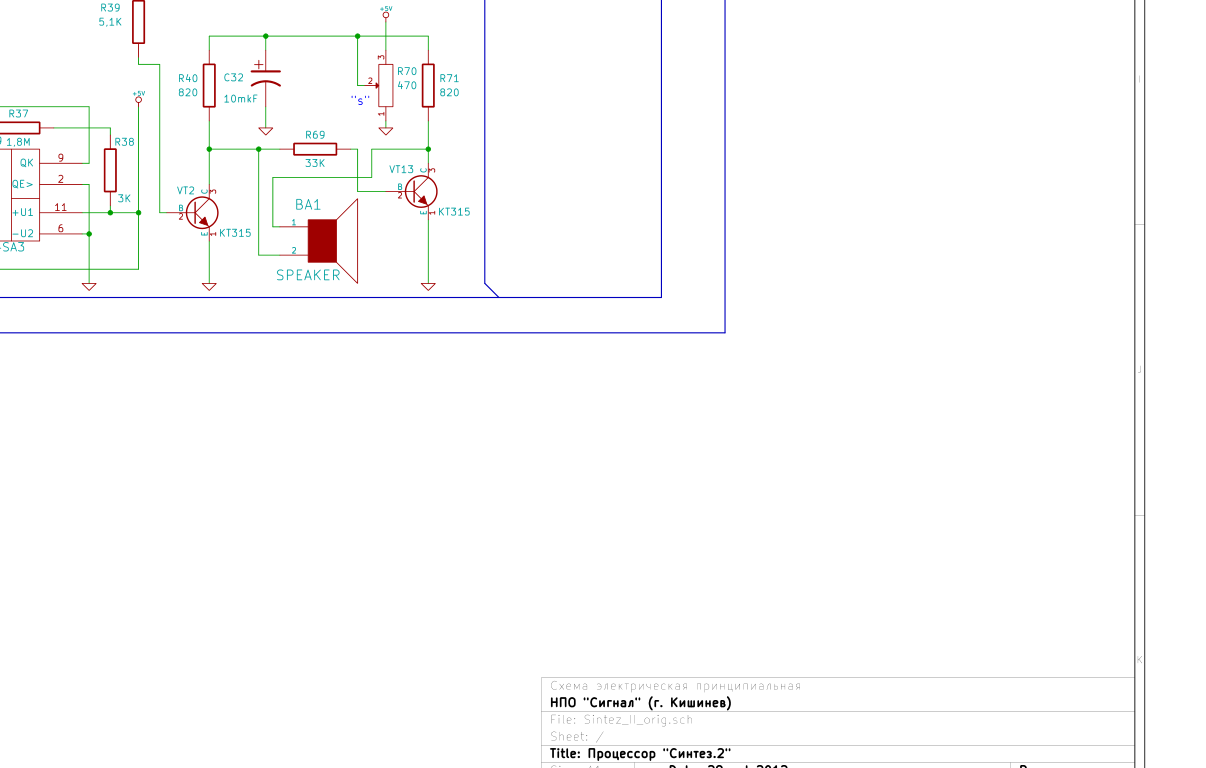
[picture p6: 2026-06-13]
schematics/tiles-color/c_r3c4.png

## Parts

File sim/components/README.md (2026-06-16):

# sim/components — SimulIDE behavioral component models

AngelScript (`.as`) behavioral models for the Sintez-2 custom / timing-critical
parts, loaded by SimulIDE 1.1.0 scripted components. See spec
`docs/spec/sintez2-recon-spec.md` §2.4 and decision
[0004](../../docs/decisions/0004-fidelity-no-memory-contention.md).

## Files

- `k565ru5.as` — К565РУ5 behavioral DRAM (≈ 4164, 64K × 1).

## SimulIDE AngelScript API used

Template: `…/SimulIDE_1.1.0-SR2_Lin64/data/scripted/DAC/dac_core.as` and the
MCS65 cores (`data/MCS65/6532/6532_core.as`, `6522_core.as`).

The global `component` object exposes the script's host component. Pins/ports
are fetched once at file scope:

| Call | Returns | Notes |
| --- | --- | --- |
| `component.getPin("Name")` | `IoPin@` | a single pin |
| `component.getPort("Name")` | `IoPort@` | a parallel bus (read as an int) |
| `component.addEvent(picoseconds)` | — | schedule a `runEvent()` callback after a delay; **unit is picoseconds** (the 6532 core uses `10000 // 10 ns`) |
| `component.addCpuReg/addCpuVar` | — | expose registers in the inspector (optional) |

Pin / port methods:

| Call | Meaning |
| --- | --- |
| `pin.setPinMode(mode)` | `undef=0, input=1, openCo=2, output=3, source=4` |
| `pin.setVoltage(v)` | drive an output pin (volts) |
| `pin.getVolt()` | read pin voltage (volts) |
| `pin.setOutState(bool)` / `getInpState()` | logic-level helpers |
| `port.getInpState()` | read the whole bus as an integer |
| `port.setOutState(int)` / `setPinMode(mode)` | drive / configure the bus |
| `pin.changeCallBack(element, true)` | register the pin so its transitions invoke `voltChanged()` |
| `port.changeCallBack(element, true)` | same, for a bus |

Script callbacks SimulIDE invokes:

| Callback | When |
| --- | --- |
| `setup()` | component created |
| `reset()` | simulation start — set pin modes, register callbacks |
| `voltChanged()` | any registered pin/port changed (re-sample levels yourself) |
| `runEvent()` | a previously scheduled `addEvent()` delay elapsed |
| `extClock(bool)` | clock-pin edge (clocked components only) |
| `getCpuReg/getStrReg` | inspector reads (optional) |

## К565РУ5 model (`k565ru5.as`)

64Ki × 1 dynamic RAM: 256 rows × 256 columns, multiplexed 8-bit address bus.

Pins expected on the package/subcircuit:

- `PORTA` — A0..A7 multiplexed address bus (input)
- `RAS` — /RAS row strobe (active-low, input)
- `CAS` — /CAS column strobe (active-low, input)
- `WE` — /WE write enable (active-low, input)
- `DIN` — data in (input)
- `DOUT` — data out (output, tri-state-ish: parked at 0 V when /CAS high)

Behavior:

- **RAS-before-CAS**: row address latched on **/RAS falling**, column latched on
  **/CAS falling**.
- **/WE low at /CAS fall ⇒ write** (early-write): DIN is sampled and stored.
- **/WE high ⇒ read**: the cell is fetched and driven on DOUT after the access
  delay.
- **/CAS-before-/RAS** (no row latched) is treated as a RAS-only / CBR
  **refresh** cycle — no data access, DOUT unchanged.
- **/CAS rising** disables the output (DOUT → 0 V) after `tOFF`.

### Timing — slow Soviet К565РУ5 (the point of the model)

Per `docs/datasheets/README.md` (РУ5 ≈ 4164 **−20 grade or slower**) and spec
§2.4 / decision 0004, the model reproduces the **slow** part. A fast 4164 must
change the WAIT verdict; do **not** swap in a generic fast 4164 / SRAM model.

| Param | Value | Meaning | Source |
| --- | --- | --- | --- |
| tRAC | 200 ns | access from /RAS (row-access read path) | datasheet −20 |
| tCAC | 100 ns | access from /CAS → DOUT valid | datasheet −20 |
| tRAS | 200 ns | min /RAS pulse width | datasheet −20 |
| tCAS | 100 ns | min /CAS pulse width | datasheet −20 |
| tRP | 120 ns | /RAS precharge | datasheet −20 |
| tOFF | 40 ns | /CAS rising → DOUT high-Z | model estimate |

`addEvent()` delays are in picoseconds (`NS = 1000`). A read drives DOUT after
`tRAC` on the first /CAS fall after /RAS (row-access path dominates), then
`tCAC` for subsequent page-mode-style accesses within the same /RAS.

> Exact tRAC/tCAC from the original РУ5 ТУ are **(to confirm)** — datasheet notes
> quote ~200–230 ns access; the −20-grade 200 ns / 100 ns figures are used as the
> slow baseline. `tRAS`, `tCAS`, `tRP` are also used as documented bounds; the
> WAIT generator on the real board enforces precharge/pulse-width spacing.

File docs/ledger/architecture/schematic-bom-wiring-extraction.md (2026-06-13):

# Q: What are the mainboard's BOM and wiring, extracted from the schematic?

- **Topic:** architecture ([index](./README.md))
- **Status:** open (in progress — block-by-block)
- **Opened:** 2026-06-13T11:50:07Z
- **Resolved:** —
- **Decision:** —

## Context

The owner supplied the original mainboard schematic and asked whether we have a
complete BOM yet, then directed: segment the sheet, **keep the segments**, and
document the **wiring in JSON** before importing anything into software.

## Discussion

### 2026-06-13T11:50:07Z — user

Asked if the BOM is complete from the schematics, or if segmentation/extraction
is still needed. Chose: **full BOM, tile by tile.**

### 2026-06-13T11:58:49Z — user

Added: keep the segments, and document the wiring in a JSON format before
putting it all into software.

### 2026-06-13T12:05:00Z — claude

The schematic has **no single BOM table** — only connector pinout tables
(X7/X8/X9…) and a "Питание микросхем" power-pin table; component types are
annotated next to each symbol. Segmented the sheet into a 3×4 grid at 350 DPI,
**kept the tiles** in `schematics/tiles/` (committed), and transcribed:

- **BOM** → `schematics/bom.json` (~40 packages, `confidence` per entry):
  CPU **D6 = Z80** (power pins 11/29 confirm it), **D28–D35 = К565РУ5 DRAM**,
  **D36 = 16 KB ROM**, pixel chain **D39/D40/D61 = ИР16 (74LS165)**, address
  arbitration **D23–D26 = КП12 (74ALS253) + D38 ИР23**, sync counters
  **D2/D3/D4/D19 = ИЕ7**, plus glue (ЛН1/ЛА3/ЛА4/ЛИ1/ЛЕ1/ЛП5/ТМ2) and modules
  УС-1…УС-5.
- **Wiring** → `schematics/wiring.json`: buses (ADDR/DATA/VADDR/VCOUNT…),
  control signals, connector pinouts, power pins, block-to-bus relations.
  Pin-accurate intra-block nets flagged as the next pass.
- Pipeline documented in `docs/schematic-extraction.md`.

### 2026-06-13T13:18:41Z — user

Asked whether the **color schematic** (the redraw whose netlist uses color
codes) was captured too — it needs its own tiling + extraction.

### 2026-06-13T13:40:00Z — claude

It had not been tiled. The redraw `sintez2-original.pdf` is a **vector** file:
text is outlined (not selectable) but strokes are color-coded — **dark-red =
parts/pins, blue = net-name labels, other colors = wire groups**. Tiled it (4×3
@400 dpi) into `schematics/tiles-color/`, rendered **per-color layer
separations** (`layers/`) as a net-tracing aid, and high-zoom crops (`zoom/`).
The redraw prints exact part numbers and names nets, so it is now the **primary**
source; the scan is the cross-check. Bumped BOM/wiring to **v0.2** with
corrections: family **К1533** (registers К555ИР16/22/23, DRAM К565РУ5, CPU
Z80A); **D41** (not "D61") is the 3rd shift register; **D13 = ЛИ1** makes
/RAS+/CAS; **D14 = ЛЕ1**; **D45 = ИР16**, **D46/D47 = КП12**; **X8** 64-pin bus
pinout high-confidence; **УС-1…5 = YC-1…5** analog driver modules.

### 2026-06-13T13:50:38Z — user

Asked to web-search Russian forums for the still-missing details.

### 2026-06-13T14:05:00Z — claude

Searched zx-pk.ru / Habr / Pikabu. **No per-designator BOM or netlist is
published anywhere** — our schematic (originally from **ZX-Club #7** magazine)
is the authoritative source; forums only confirm top-level specs. Concrete gains
recorded to `bom.json` → `external_corroboration`:

- Specs match: Z80A @3.5 MHz, 48 KB base / 128 KB upgrade, 16 KB ROM (BASIC),
  board **СМП59**, the 200-Ω sync resistor.
- zx-pk t-240: the **128K upgrade lifts 3 pins of the КП12 mux that carry
  A14/A15** and feeds A14'/A15' from paging logic — **corroborates D26 КП12 as
  the A14/A15 paging mux**, and the "2nd-storey РУ5 row + CAS split" method.
- **D36 ROM** is a 28-pin 16Kx8 EPROM (27128-class; Soviet К573РФ6/РФ8 or
  imported 27128) — exact marka to confirm from a board photo.
- Further docs: `Sintez-128.zip`, ZX-Club #7, zx-pk thread t-240.

The unresolved low-confidence parts (D37/D44/D49/D50/D51, ИЕ10) are **not
obtainable from forums** — they must come from high-zoom reads of the color
tiles and (ideally) a clear board photo. Logged as such.

### 2026-06-13T14:20:00Z — claude

Owner has no physical Sintez and asked to try the Internet Archive for the 404s.
**web.archive.org and archive.ph are unreachable from this environment** (egress
policy: `curl`→"Blocked by egress policy", WebFetch→"unable to fetch"); the
`archive.org/wayback/available` API responds but has no snapshot for those URLs,
and the surviving forum mirrors are dead (one hijacked to a casino, one 503).

Pivoted to the **color tiles** (no board/internet needed) with targeted high-zoom
crops, which resolved most remaining gaps to high confidence:
- **D5 = К1533КП12** — generates video-fetch address K8–K12 from the V-counters.
- **D11 = К561ИЕ10 (CD4520)** — CMOS dual counter; resolves the "ИЕ10" question.
- **D26 = К1533КП12** — A/K address mux; **D36 = 27128** (labeled literally).
- **D48 = К1533ИР22** — border register (D0–D4 → BB/RB/GB).
- Captured the К565РУ5 address-pin → VADDR map (`wiring.json` `dram_addr_map`).

Still open (not online, no board): **D37, D44, D49, D50, D51** (disk/keyboard area).

### 2026-06-13T16:16:12Z — user

Asked to search the Russian web (Yandex/Mail.ru/etc.) for Sintez-2 **motherboard
photos** (to read the remaining chip markings).

### 2026-06-13T16:30:00Z — claude

Found and **downloaded** board photos (egress allows image CDNs even though
web.archive.org is blocked): `habr.com/ru/articles/222569` →
`reference/photos/sintez2-board-habr.jpg` (1920×1278, original SONY shot) and a
priborazbor.ru top view. They confirm the **CPU is an imported Zilog Z8400**
(ceramic, bottom-centre) and the **layout matches our schematic** (chip rows,
blue X-connectors, КТ315 output transistors); priborazbor's scrap-content count
(~18 DRAM-class + 17 155/1533-series + 1 Z80 + 17 КТ315) is a rough total-IC
cross-check. **But 1920px is too low** to read individual silkscreen designators
(each DIP ≈90px), so **D37/D44/D49/D50/D51 remain unresolved** — they need either
a higher-res board photo or more high-zoom reads of the color redraw (the better
route, and within reach without a board).

### 2026-06-13T16:24:10Z — user

Asked to search deeper for higher-resolution images.

### 2026-06-13T16:40:00Z — claude

Went deeper: extracted **all 8** images from the habr article and downloaded each
at the max `getpro` resolution — but **habrastorage caps everything at 1920px**,
and only **one** of the eight is a board shot (the rest: case, rear panel,
nameplate "SINTEZ 2"/1995, running setup, TV screen). The true full-res host
(`beta.hstor.org`) is **dead (no DNS)**. priborazbor=696px, festima=case only,
web.archive.org/archive.ph blocked. **Conclusion: no higher-res Sintez-2 board
photo exists online** than the 1920px habr shot, which is not enough for the tiny
silkscreen designators. Saved the **rear-panel** photo
(`reference/photos/sintez2-rear-panel.jpg`) — it corroborates the connector set
(PS/TV/RESET + card-edge X8 bus + DB9/DIN). D37/D44/D49/D50/D51 stay open; the
color redraw remains the only viable route for them.

### 2026-06-13T16:28:59Z — user

Asked whether I'd actually formulated the searches in Russian.

### 2026-06-13T16:55:00Z — claude

Yes — several queries were Russian; the real limit is the WebSearch tool being
US-indexed, which I'd under-exploited. Going deeper with Russian-targeted queries
surfaced the dedicated **Sintez-2 repair threads** (zx-pk.ru 27280, 19568;
zx-pk.com 17915). Outcome: their photos are **low-res thumbnails (799×599) + TV
diagnostic screens — no readable board close-up**; one attachment (S2_09.jpg) is
just a lower-res copy of OUR schematic (confirms it's **page 29, ПРИЛОЖЕНИЕ 2**,
canonical). The forum **text** did corroborate the BOM: **D39–D42 = pixel +
attribute generation, КР1533КП12 video muxes, ИР16**; plus rebuild notes
(К555↔К1533 interchangeable; РУ5 letters В/Г; 27128 → W27C512 flash). Conclusion:
**no high-res board photo exists online** even in repair threads — the color
redraw stays the route for D37/D44/D49/D50/D51.

## Outcome

<!-- in progress -->
BOM **v0.3** and wiring **v0.3**; board + rear-panel photos saved; forum text
corroborates the video-generator block (D39–D42 / КП12 / ИР16).
Remaining: trace pin-level nets per block (cpu → decode → dram → arbitration, per
T2/T3) using the color layers, complete the X8 lower-row pins and the IC power
table. Each completed block gets `status: done` and is fed to `bridge/net2sim.py`.

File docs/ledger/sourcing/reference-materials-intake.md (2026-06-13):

# Q: What primary-source materials do we have, and where are they kept?

- **Topic:** sourcing ([index](./README.md))
- **Status:** resolved
- **Opened:** 2026-06-13T11:23:03Z
- **Resolved:** 2026-06-13T11:32:15Z
- **Decision:** —

## Context

The owner supplied original Sintez-2 reference materials (schematics, board
photos, a memory-expansion writeup, a video-output pinout) and asked that they
all be saved in the repository.

## Discussion

### 2026-06-13T11:23:03Z — user

Provided `sintez2_sch.pdf` (mainboard schematic) and then `Sintez_II_orig.pdf`,
a betadisk photo, `Sintez128.jpg`, and a video pinout PNG. Instruction: save all
PDFs, the betadisk image, and the next PDF too.

### 2026-06-13T11:32:15Z — claude

Saved all five assets under `reference/` (committed, so they survive the
ephemeral container — overriding the earlier "don't commit large sources"
default). Catalogued with provenance hashes in
`docs/references/sources-catalog.md`. Rendered the PDFs with PyMuPDF (poppler
was not installable) and extracted key facts:

- Mainboard schematic = "ПРОЦЕССОР «СИНТЕЗ-2», ПРИЛОЖЕНИЕ 2"; BOM table on the
  right edge (to be transcribed in T1).
- Beta Disk board → **КР1818ВГ93 ≈ WD1793 FDC** confirmed (added to
  `parts_map.json`).
- 128 KB expansion → port `#7FFD` paging (feeds the bank-switching question).
- SCART/Jack video mod → 200 Ω sync resistor note (RGB stage detail).

## Outcome

All materials are in `reference/` and catalogued; `schematics/NOTES.md` (T1) and
`parts_map.json` updated with confirmed parts. See
[`docs/references/sources-catalog.md`](../../references/sources-catalog.md).

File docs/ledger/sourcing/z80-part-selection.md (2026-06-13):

# Q: Which Z80 part for the physical build?

- **Topic:** sourcing ([index](./README.md))
- **Status:** open
- **Opened:** 2026-06-13T10:33:56Z
- **Resolved:** —
- **Decision:** [0001](../../decisions/0001-keep-real-zilog-z80.md) (keep a real Z80)

## Context

Spec §4. Decision 0001 mandates a genuine Z80. Which exact part to buy, and
shipping to Moldova, is still open.

## Discussion

### 2026-06-13T10:33:56Z — claude

Candidates from the spec:

| Part | What | Notes |
| --- | --- | --- |
| **Zilog Z84C00** (e.g. Z84C0020) | Genuine modern CMOS Z80, in production | €3–5 Mouser/Digi-Key/TME; ships to Moldova; **recommended default** |
| КР1858ВМ1 / КР1858ВМ3 | Soviet NMOS/CMOS clone | eBay/au.ru; shipping restrictions vary |
| U880 / UB880D | East German (MME) clone | eBay; often easier to find |
| MMN 80 CPU | Romanian clone | from Romania (EU neighbor) |
| MME "80A CPU" | Z80A 4 MHz NMOS clone | ~$10 + shipping from Ukraine |

Recommendation: **Z84C00** as default (in production, sourceable, ships to MD).
Buy 2–3 for spares. FPGA soft core (TV80/A-Z80 on iCE40/Gowin) is the fallback
only if physical Z80s become unavailable.

## Outcome

<!-- pending purchase at T8 -->

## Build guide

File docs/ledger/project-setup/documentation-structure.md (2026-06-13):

# Q: How should docs and the discussion ledger be structured?

- **Topic:** project-setup ([index](./README.md))
- **Status:** resolved
- **Opened:** 2026-06-13T10:20:11Z
- **Resolved:** 2026-06-13T10:20:11Z
- **Decision:** —

## Context

The s4 ("Sintez 4") repository started essentially empty. Before the first
technical task, we need a home for documentation and a durable record of
discussions, so reasoning is not lost between sessions.

## Discussion

### 2026-06-13T10:20:11Z — user

Requested: create a `docs/` directory and keep all Markdown there. Keep a
discussion ledger with date-time under `docs/ledger/`, grouped by topics and
by questions. Generate templates and rules. Note: discussion may happen in
Romanian, but everything written down must be in English. A technical task
will follow.

### 2026-06-13T10:20:11Z — claude

Implemented the structure:

- `docs/README.md` — documentation index.
- `docs/RULES.md` — rules for docs and the ledger (location, language,
  naming, timestamps, append-only ledger, decisions).
- `docs/templates/` — `doc.md`, `decision-record.md`, `ledger-topic.md`,
  `ledger-question.md`.
- `docs/ledger/` — ledger root with `README.md`, the `project-setup` topic,
  and this question file as the first entry.

Key conventions chosen: English-only written records; `kebab-case` names;
UTC ISO 8601 timestamps; ledger grouped by topic (folder) then question
(file); append-only entries.

## Outcome

The documentation and ledger structure is in place and documented in
`docs/README.md` and `docs/RULES.md`. Ready for the upcoming technical task,
which will open new topics/questions in the ledger as needed.

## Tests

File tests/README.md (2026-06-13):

# tests — validation & regression

See `docs/spec/sintez2-recon-spec.md` §5.4, §10 and milestones T7/T9.

- ZEXDOC/ZEXALL (CPU correctness via CRC) — the bar.
- FUSE test suite (per-instruction T-states & memory accesses).
- Patrik Rak contention/floating-bus tests: **N/A for Sintez 2 — must NOT pass**
  (no memory contention). Passing them = wrong machine.

(Skeleton — not yet implemented.)

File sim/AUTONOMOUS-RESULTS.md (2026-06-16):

# Autonomous workflow results (2026-06-16)

Fan-out workflow (16 agents, build + adversarial verify). Raw: `schematics/sources/autonomous-2026-06-16/result.json`.

## ngspice analog (sim/spice/)
| deck | verify | result |
| --- | --- | --- |
| clock_osc.cir | ✅ CONFIRMED | /4 ripple divider → 7 MHz dot / 3.5 MHz CPU; quartz AC-resonance 14.000 MHz (motional params = documented 14 MHz AT-cut typicals). |
| rgb_ladder_full.cir | ✅ CONFIRMED (caveat) | 8 distinct levels 0→0.718 V into 75 Ω; full-white ~0.72 V ≈ 0.7 Vpp std. Ladder NET topology = standard ZX diode-OR DAC (values exact, exact wiring TODO). |
| wait_gen.cir | ⚠ DISPUTED | WAIT ≈ 307 ns, SAFE vs РУ5 (200-230 ns), verdict CHANGES for fast-4164 (timing-sensitive, decision 0004). BUT the /CAS R13/R14/C4 network + 1-Tclk count are ASSUMED, not pin-traced. |

## К565РУ5 behavioral model (sim/components/k565ru5.as)
SimulIDE AngelScript: RAS-before-CAS, row/col latch, /WE early-write, DOUT after tCAC;
РУ5 slow timing (tRAC 200 / tCAC 100 / tRP 120 ns). **Fixed** the verifier-found bug
(`getVolt()` → `getInpState()`, the real SimulIDE 1.1 IoPin logic read). Needs GUI run to validate.

## Net traces (→ folded into wiring.json)
- **arbitration (crown jewel) ✅ CONFIRMED high-conf** — D5 КП11 makes K8-K12 from V-counters;
  D23-D26 КП12 screen-address mux DATA inputs fully resolved (only the A/B select + OE0 =
  arbitration timing remain ambiguous). The previously-unresolvable block.
- **ROM decode ✅ CONFIRMED** — real chain D22A NOR(A14,A15) → D9E → D27C NAND → ROM /CE
  (not the earlier functional D17 guess); D26 КП12 = A14/A15 paging.
- **sync flip-flops ⚠** — D16A/D16B/D8B traced (one error corrected by verify); some
  set/reset wraps still unresolved.

## Family timing (→ for net2sim)
ALS(К1533) Tpd 4 ns / LS(К555) 15 ns / CMOS(К561) 50 ns; **К555ИР16 forced LS (NOT ALS),
tpd ~27 ns, tsu ~22 ns** — the deliberate setup-margin choice (spec §3). ✅ verified.

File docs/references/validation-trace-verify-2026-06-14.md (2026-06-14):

# Schematic trace + adversarial-verify report (2026-06-14)

Output of the `sintez2-trace-verify` workflow: 8 schematic blocks, each traced by
one agent and adversarially verified by a second (16 agents). Raw results in
`schematics/sources/trace-verify-2026-06-14/` (gitignored). This file is the
human-readable distillation — what is **confirmed**, **ambiguous**, **missing**,
and what each finding changes.

> Purpose: resolve the netlist ambiguities/uncertainties/missing components before
> the SimulIDE validation pass. Items marked ⚠ need a targeted re-trace or a
> simulation check; items marked ✅ are safe to wire into the SKiDL netlist.

## Corrections to BOM / earlier work (applied)

| Item | Was | Now (verified) | Source |
| --- | --- | --- | --- |
| **D5** | КП12 (74ALS253) | **К1533КП11** (quad 2:1, 74ALS257) | schematic label, both agents |
| **R49** | 1k | **1.8K** (reads "1,8K") | RGB-ladder render |
| **VT13–VT18** | "RGB output VT13–VT18" | RGB drivers are **VT3–VT12**; VT13 is the **beep** driver; VT14–VT18 not found | RGB region scan |
| **Net `a`** | (unknown global) | **= GND/0V** (red global label on GND triangles); `a2` is distinct | sync block |

Still to confirm (flagged, not yet applied):
- **D15 / D16**: redraw draws them as **К1533ТМ2** (dual D-FF); BOM types them ЛН1
  (74LS04). Re-trace before trusting either. ⚠
- **D9–D16 designator collision**: the disk-address diodes (КД522) near D50 appear
  labelled D9–D16, which also name logic ICs. Likely the diodes are VD-series and
  the BOM's "D9..D16 disk-address diodes" was a misread. ⚠

## Per-block status

### pixel-chain — ✅ medium, consistent
- D39/D40/D41 = К555ИР16 (4-bit/14-pin). **Chain: D41(VD0-3) → D40(VD4-7) → D39 →
  D18 XOR (FLASH)**, via Q3→SI of the next stage. D40.Q3 also taps D13.12 (FLASH AND).
- OE(8) of all three + D41.SI tie to net `a` (= GND). PE(6) to GND. Outputs Q0-Q2 NC.
- ✅ Safe to wire. ⚠ Confirm the D13.12 tap is on D40.Q3 (verifier says yes).

### color — ✅ high (after fix), was inconsistent
- **D43 was FABRICATED by the trace** (duplicated D42's pins). Real members:
  **D42 (ИР23 octal register)** VD0-7 in → B0/R0/G0/B1/R1/G1/Y color/attr out;
  **D46/D47 (КП12)** mux those → BM/RM/GM/YM; **D48 (ИР22)** border latch D0-D4 →
  BB/RB/GB; **D45 (ИР16)** colour shift register.
- A real **D43 (ИР22 video-data latch) exists in the BOM but was NOT located** in
  this crop — find it (likely just outside the window). ⚠ missing
- D48 input order as drawn is D0,D1,D2,**D4,D3** (D3/D4 swap — read clearly).
- D46/D47 OE0 ← D13D (FLASH-gated SCREEN); A1 select = BORDER; A0 select source ⚠.

### rgb-output — ✅ high, analog (ngspice T6)
- VT3–VT12 КТ315/КТ361 emitter-followers + ladder (R41 620/R42 1.8k/R47 270/
  R48 620/**R49 1.8k**/R54 620/R55 1.8k/R60 820) + VD3–VD8 (КД522). 26 nets confirmed.
- ⚠ B-channel pulldown 33k shown as "R?" (likely R43); G-channel diode "VD?" (likely VD8).
- No DIP ICs here → analog model only.

### tape-audio — ⚠ medium, needs re-trace (trace had errors, verifier corrected)
- ✅ **X5**: pin3=TAPE_IN, pin2=GND, pin1=TAPE_OUT (matches wiring.json).
- ✅ Beep push-pull: VT13 collector = {R71.2, +5V}; VT13 base = {R69.2, VT13.2, BA1.1}.
- ✅ D49 = К544СА3 comparator (tape-IN conditioning: R30/R31/C7 → R39 → comparator).
- ⚠ Passives R30/R31/R32/R33/C6/C7/C9 omitted by the trace — re-trace to place them.
- ⚠ The BEEP/port-0xFE drive net has **no visible label**; source must be found
  (decode/IO). This is a genuine ambiguity for the simulator (sound timing).

### disk-io — ✅ high, consistent on the ICs
- ✅ D44/D51 = К1533ИР22, D50 = К1533АП3 (both halves) — types/pins confirmed.
- ✅ X1 'L'/X2 'R' joysticks → AA11/AA12; X6 → AA8-AA15 disk address; КД522 diodes.
- ⚠ Net `a` (D44.11 latch enable + D51.11/14/17/18) source is off-block (D37A/D22D gate logic).
- ⚠ D50_OE, D51.17, D51.OE destinations route off-block — trace later.

### addr-decode — ⚠ medium, consistent; ROM select unreadable
- ✅ D26 = КП12 paging mux (A9/A13/A14/A15 + K9); OE1(pin15) tied GND (always enabled).
- ⚠ **ROM /CE (pin20) and /OE (pin22) could NOT be traced to a specific gate** even
  by a dedicated agent — the decode field's green wires are too dense. **This
  vindicates the "functional decode" choice in sintez2.py block 2b.** Resolve via
  simulation (does the functional decode boot the ROM?) or a much higher-zoom trace.
- ⚠ Glue-gate (D9/D17/D22/D27/D37) pin numbers read, but inter-gate nets unresolved.

### arbitration ("crown jewel") — ⚠ medium, inconsistent; partially resolved
- ✅ **D5 = К1533КП11** (corrected). D5 makes K8/K11/K12; K9→D26.4; K10 from D7B (ЛИ1).
- ⚠ **D38 (ИР27)**: the 'CLK' label wires to D38.6 (Q2) — illogical (Q→CLK); the
  real clock input is pin11. D38 outputs Q3(9)=RAM, Q5(15)=FV; other Q's route to
  the data/bus area unlabeled. Needs careful re-trace.
- ⚠ Mux select lines (A0=pin14, A1=pin2) + OE0 shared on unlabeled vertical wires —
  the arbitration-control source is **the single most important unresolved net**
  (it's the screen-address generator). Defer to a dedicated high-zoom trace +
  simulator validation, as planned.

### sync-decode — ✅ medium, consistent
- ✅ Net `a` = GND (counter DI pins, /S, /R ties). D2/D19 (H) + D3/D4 (V) ИЕ7 counters.
- ⚠ D15/D16 drawn as ТМ2 (see corrections). D8A/D10B/D14C present (trace mis-reported missing).
- ⚠ Counter cascade control inputs (L/CU/CD, carries) + HSYNC/VSYNC decode gate
  nets (D10A/D14A/D14D/D21) route across the sheet — far ends not all resolved.

## What this means for the two tracks

- **KiCad (SKiDL):** pixel-chain, color (minus the missing D43), rgb-output,
  disk-io ICs, sync counters are ✅ ready to wire. addr-decode ROM-select and the
  arbitration screen-address generator are the two ⚠ blocks where vision tracing
  hit its limit — wire them functionally + flag, exactly as block 2b/4 already do.
- **Electronics simulator (SimulIDE):** the unresolved items (ROM /CE/OE gating,
  arbitration select timing, beep/port-0xFE source, РУ5 timing) are precisely the
  ones to **validate by simulation** — boot the ROM, watch /MREQ→/RAS/CAS, confirm
  the functional decode/arbitration produce a correct screen address. Installing
  SimulIDE + the `bridge/net2sim.py` is the enabling next step.

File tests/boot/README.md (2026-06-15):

# tests/boot — headless boot validation (spec T7: "boots to the © prompt")

Runs the ZX-Spectrum-48K-compatible ROM (`roms/sintez-M.rom`) on a vendored Z80
core, using the Sintez-2 memory map our SKiDL/KiCad decode implements
(ROM 0x0000–0x3FFF read-only, RAM 0x4000–0xFFFF), and checks the machine boots.

This validates, **fully headless** (no SimulIDE GUI), the "functional" decode the
trace-verify workflow could not confirm visually: does the intended memory map
actually boot a real ROM? (It does not validate gate-level timing — RAS/CAS — which
needs the SimulIDE gate model.)

## Run
```bash
cc -O2 -o tests/boot/boot tests/boot/boot.c tests/boot/z80.c
tests/boot/boot                 # uses roms/sintez-M.rom
```

## Result (2026-06-15) — PASS ✅
- **P-RAMT (5CB4) = FFFF** — RAM-size probe found the top of 64 KB (RAM map works).
- **CHARS (5C36) = 3C00** — font base set; ROM init completed.
- **768 attributes + screen pixels set** — display initialised; the **© sign-on
  message** is rendered at screen rows 184–191 (confirmed by ASCII render).
- Conclusion: the ROM(0–3FFF)/RAM(4000+) map boots a ZX-compatible ROM to the
  © prompt — the T7 bar is met for the functional memory map.

`boot.c` is the harness; `z80.c`/`z80.h` are the **superzazu/z80** core
(github.com/superzazu/z80, MIT licence — third-party, retains its own licence;
passes ZEXALL). The ROM lives in the gitignored `roms/`.

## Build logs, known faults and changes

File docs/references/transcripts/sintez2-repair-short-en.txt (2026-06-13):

[00:00:01] O-o-oh, beauty!
[00:00:03] ...just for games and leisure activities...
[00:00:06] ...every decent person should have a soldering iron to organize their leisure time...
[00:00:09] ...such crystal needles have grown on the terminals of some elements...
[00:00:13] ...if we put them together, we find this diastema...
[00:00:17] This is how the artist imagines leisure.
[00:00:24] Hello, friends!
[00:00:26] Today is a bit unusual video: I decided to research what microcontrollers
[00:00:29] are being produced locally to substitute the imported versions.
[00:00:39] In general, the list isn't very large, but there is enough to choose from.
[00:00:43] But the truth is, it turned out to be absolutely impossible to buy any of them...
[00:00:47] And then I remembered that I have an old, ancient corpse of such a grandad.
[00:00:52] This is a Soviet clone of the ZX Spectrum, on TTL ICs.
[00:00:55] The most local ones.
[00:00:58] One of the latest Soviet engineerings.
[00:01:00] This box has not been opened for about 30 years and what's inside is a big, big surprise.
[00:01:05] Let's proceed with the exhumation.
[00:01:09] Maybe it has already decomposed into mold and lime honey...
[00:01:20] Well...
[00:01:22] Cable for a tape recorder.
[00:01:25] Cables for TV and power.
[00:01:33] Everything is very oxidized here.
[00:01:42] The power supply.
[00:01:47] O-o-oh, beauty!
[00:01:51] Well, let's try to resuscitate this grandad.
[00:01:55] Before giving it an electric charge, let's look at the state of the power supply.
[00:01:59] As far as I remember, it is linear, so it has a toroidal transformer and an LM7805.
[00:02:03] And I don't have any concerns about them, but the electrolytes (capacitors) need to be checked.
[00:02:12] The main smoothing capacitor here is the K50-24 batch.
[00:02:15] This is a good, high-quality batch.
[00:02:18] But after the LM7805 there is a K50-35 series, about which the reviews are not very good.
[00:02:22] In addition, there is a red "flag"-type capacitor installed here,
[00:02:25] in which over time the silver coating, which is the electrodes,
[00:02:28] can diffuse into the ceramic dielectric
[00:02:31] and cause noise, or even a short circuit.
[00:02:33] I desoldered the electrolyte and checked it with a tester.
[00:02:36] It turned out to be all right, the capacity and ESR are normal.
[00:02:39] I checked the "flag" and, surprisingly, it is also normal.
[00:02:42] So I connect the PSU directly to the smoothing capacitor,
[00:02:46] limit the current to 0.01A and leave it for several hours
[00:02:51] so that the oxide layer restored through anodization.
[00:02:55] Going further. I see that there is a 39 Ohm resistor installed between the ground and the LM7805,
[00:03:00] that is quite strange.
[00:03:02] Firstly, LM7805 (at least this version) does not imply adjustment of the output voltage,
[00:03:07] and secondly, as I later found out, there is no any resistor in the schematic.
[00:03:11] Because of it, the power supply gives an increased voltage
[00:03:14] of 5.35 volts without load, which is too much.
[00:03:17] And also under load, it gives out an increased voltage.
[00:03:20] I don't really understand why this was done,
[00:03:23] maybe to provide increased voltage when starting the computer
[00:03:26] or to reduce slightly the power dissipation of the LM7805, I don't know.
[00:03:29] Write in the comments if you know why this was done.
[00:03:33] Well, I decided not to remove this one,
[00:03:35] but to solder another 15 Ohms resistor in parallel with it.
[00:03:38] This will bring the output voltage closer to the required 5 volts,
[00:03:41] and the effect conceived by the developers will decrease, but still remain.
[00:03:46] That's it with the power supply. Now let's take care of the computer itself.
[00:03:49] It also has electrolytes, so I also connect it through the PSU with a current limit
[00:03:55] and slowly, gradually increase the current.
[00:04:04] And, it's a miracle, it turned on and gave out a picture.
[00:04:07] It is a bit in a green shade, but we'll fix it easily.
[00:04:11] But there's a problem with the keyboard: only 4 buttons work.
[00:04:14] And they don't work the way they should.
[00:04:17] This string is all I can type on it.
[00:04:20] The keyboard in it is made of flexible plastic and most likely it has already rotted.
[00:04:22] Anyway, we can't continue without an autopsy, so let's get started.
[00:04:27] And while I'm disassembling it, let's study the user manual,
[00:04:30] which, fortunately, I also have preserved.
[00:04:32] Gaming Computer.
[00:04:34] "EY"...
[00:04:35] Okay, let's have a look.
[00:04:39] "Attention!" - 4 stickers at once.
[00:04:42] When connecting the joysticks to the computer, make sure
[00:04:45] that the trapezoidal key and the connector contacts match... I see.
[00:04:48] In your computer, the piezoceramic ZP-3 buzzer, the SNP58 socket and plug are not installed
[00:04:51] due to the lack of supply (*problems of the Soviet Union with production and shipment).
[00:04:57] I see!
[00:04:58] In this computer, instead of the Z80A microprocessor,
[00:05:01] the KR1858VM1 microprocessor is installed, which has a higher speed.
[00:05:07] Great!
[00:05:08] Due to the lack of supply, this computer does not have
[00:05:11] a Sinclair-type joystick connector installed.
[00:05:14] (This joystick duplicates the numeric keypad buttons).
[00:05:17] Attention!
[00:05:19] The set of accessories is equipped with three fuses.
[00:05:22] Great, great!
[00:05:24] Further, general instructions.
[00:05:26] The gaming computer is programmatically compatible with the ZX Spectrum 48 computer.
[00:05:31] Everything is clear, good.
[00:05:32] You can use reel-to-reel recorder... Cassette recorder...
[00:05:35] An "Electronica" video monitor
[00:05:38] or a household color TV can be used as a display.
[00:05:42] Wonderful!
[00:05:44] The package of delivery.
[00:05:45] This is what we have in the box.
[00:05:48] Specifications.
[00:05:49] Microprocessor type - Z80 (but actually not).
[00:05:53] The clock frequency is 3.5 MHz.
[00:05:55] And here we have a quartz resonator installed at 14.3MHz,
[00:06:00] i.e., it is probably divided by 4 and it turns out 3.575 MHz.
[00:06:07] Well, really, a little faster.
[00:06:09] RAM capacity, ROM capacity... Screen resolution... Okay.
[00:06:14] A brief description of the product.
[00:06:16] The gaming computer is designed for users
[00:06:18] whose work or study is related to the use of computers,
[00:06:21] as well as for those who want to use a computer at home
[00:06:24] for self-study of the basics of computer science
[00:06:26] and just for games and leisure activities.
[00:06:29] Great! Let's get down to leisure.
[00:06:32] Preparation for work and the procedure for working with the product.
[00:06:35] Do not put objects on the power supply.
[00:06:38] Okay, we won't.
[00:06:40] Soooo, connect the joysticks, tape recorder... color adjustment... loading the program.
[00:06:46] Fine. Everything is clear here.
[00:06:50] Warranty obligations.
[00:06:53] Certificate of acceptance.
[00:06:55] March 1992.
[00:06:57] Next we have warranty cards.
[00:07:03] A lot of warranty cards.
[00:07:06] Aha, here! Recommendations for connecting a computer to a TV or video monitor.
[00:07:12] Characteristics of the signals.
[00:07:13] Here in detail about all the signals that we can get from the video part of the board.
[00:07:19] Got it, everything is clear.
[00:07:21] Before modifying the TV, you should study the TV schematic.
[00:07:26] We will! Of course!
[00:07:28] In case of difficulties during the modification,
[00:07:30] it is necessary to consult a TV workshop or an experienced radio ham
[00:07:33] (if you are not one of them))).
[00:07:36] Soooo, connecting to a TV.
[00:07:38] In order to switch... to display mode... la-la-la... connect the appropriate... so, everything is clear...
[00:07:44] Modification of TVs of type 3USCT and 4USCT, with chroma modules of type MC-31...
[00:07:51] I don't understand why there is no soldering iron included in the package?
[00:07:56] Well, although probably every decent person
[00:07:58] should have a soldering iron and everything else to organize their leisure time.
[00:08:02] Okay.
[00:08:03] Install and solder an additional socket of the DIN type.
[00:08:05] OK, done.
[00:08:07] .....
[00:08:11] Well, let's suppose. Okay )
[00:08:13] .....
[00:08:20] In general, it should be clear to a fool.
[00:08:22] Everything is simple, everything is clear.
[00:08:24] Any normal person, if he is not quite a moron,
[00:08:27] easily modifies the chroma module MC-31, MC-41, MC-402, 403...
[00:08:34] Well, what problems can there be?
[00:08:37] Everything is clear.
[00:08:38] Lets' go further.
[00:08:39] Here we have an upgrade of the chromaticity module.
[00:08:43] Well, in general, everything is clear, everything is simple.
[00:08:46] There are no questions.
[00:08:48] Let's digress from the user manual for a second, there's something interesting here.
[00:08:51] After disassembly, I immediately seal the ultraviolet erasure ROM,
[00:08:55] so that the flashlights do not accidentally erase the firmware,
[00:08:58] and then I notice an interesting physical phenomenon:
[00:09:00] such crystal needles have grown on the terminals of some elements.
[00:09:04] I don't really understand the nature of the phenomenon,
[00:09:06] if someone knows what caused it - write in the comments.
[00:09:09] I haven't checked, but I suspect that these crystals may be conductive,
[00:09:12] so it's a luck that nothing burned.
[00:09:16] Let's continue with manual.
[00:09:17] Here we have a schematic diagram.
[00:09:20] Large, detailed.
[00:09:22] I scanned it to a file and I'll leave a link in the description, so if you are interested, feel free to study it.
[00:09:26] Then we will not dwell on it in detail now.
[00:09:32] Then the location of the elements on the board.
[00:09:35] Also useful.
[00:09:38] Keyboard schematic.
[00:09:39] Well, it's pretty small and illegible here, but in general everything can be understood.
[00:09:43] Schematic of the power supply unit.
[00:09:48] And this is how the artist imagines leisure.
[00:09:53] Well, yes... Here's a fish...
[00:09:55] Good.
[00:09:57] Then the addresses of the service centers,
[00:10:00] well, that's all, that's the end of the manual.
[00:10:03] Back to our artifact.
[00:10:05] I cleaned the overgrown strange crystals, and examined the keyboard,
[00:10:09] which unfortunately finally decomposed.
[00:10:11] There is no way to restore it, and obviously I will have to order a new one.
[00:10:15] I tried to restore several tracks with the conductive glue,
[00:10:18] a few more keys worked, but the situation has not changed fundamentally.
[00:10:22] And the keyboard here is not simple, it is five-layered here:
[00:10:24] three contact layers and two intermediate ones.
[00:10:27] This is necessary for some additional keys to work,
[00:10:29] for example, such as left/right, up/down arrows and so on.
[00:10:32] I.e. for example, when you press the up arrow, two circuits are shorted at the same time,
[00:10:36] one is equivalent to Caps Shift and the other is equivalent to the "7" key.
[00:10:39] Just in case, let's make sure that the problem is in the keyboard, and not in some circuits on the board.
[00:10:44] To do this, I alternately close all the contacts of the first connector with all the contacts of the second one,
[00:10:48] which gives us 40 possible crosspoints
[00:10:51] and, accordingly, that is why there are 40 keys on the original ZX Spectrum
[00:10:55] (not the Spectrum+).
[00:10:56] Well, great, all the lines are working, so the problem is in the keyboard.
[00:11:00] Let's now compensate all the undelivered parts,
[00:11:03] so that finally, after 30 years, the device will be complete.
[00:11:06] We start with the SNP58-64 connector,
[00:11:09] to which literally all the pins of the processor and the power bus are connected.
[00:11:13] This is of course very convenient for designing and for connecting any peripherals.
[00:11:17] As I understood from the schematics found on the Internet, the original ZX Spectrum+ was done exactly the same,
[00:11:21] only the connector, of course, was different.
[00:11:24] In general, this particular clone is very different in its architecture from the original
[00:11:27] in that the original Spectrum used a custom IC
[00:11:30] that provides all the peripheral logic of the computer from the graphics system to the IO ports.
[00:11:36] Similar ICs were also made for Soviet clones,
[00:11:38] but this particular model is based on discrete elements, which of course made the design more expensive.
[00:11:44] But this is also why he is valuable.
[00:11:46] Next is the Sinclair joystick connector.
[00:11:48] There were two of them designed here, but the one is missing.
[00:11:51] Joysticks of this type duplicate the numeric keypad buttons:
[00:11:54] one from "1" to "5", and the second from "6" to "0".
[00:11:57] So no additional elements are required on the board,
[00:12:01] unlike the Kempston joystick,
[00:12:03] which requires a register chip and several strapping elements.
[00:12:10] Then I replaced the adjustable resistors SP3-38A,
[00:12:13] which were in terrible condition.
[00:12:15] Fortunately, all this can still be bought
[00:12:17] and we can keep the original design without any clumsy customization.
[00:12:21] But I have to say that even these new resistors are absolutely disgusting quality.
[00:12:25] Made from cardboard, tight and with very poor contact.
[00:12:28] But they are original.
[00:12:32] Well, the final touch is the piezoelectric buzzer ZP-3,
[00:12:36] it is also still on sale and also of terrible quality.
[00:12:39] All the elements for its operation are present on the board, so let's solder it...
[00:12:46] stick it to the board so that it does not hang out...
[00:12:51] and that's it!
[00:12:53] And while I haven't drawn and ordered a new keyboard yet,
[00:12:58] I decided to solder cable lines directly to its connectors so as not to poke wires into them and not to bend the contacts.
[00:13:02] I was known as Vladislav the Poker.
[00:13:06] After that, I built such a mini keyboard.
[00:13:09] There are only 6 buttons:
[00:13:11] this is the "J" button or the "LOAD" command,
[00:13:13] then the SHIFT button,
[00:13:15] then the "P" button, which in combination with the SHIFT gives quotes.
[00:13:19] The "R" button is also the "RUN" command
[00:13:21] and the ENTER button.
[00:13:22] To make it more fun to experiment,
[00:13:25] I found in my bins such a chip from 1988 year.
[00:13:28] There are three bidirectional 8-bit I/O ports with a set of various additional functions.
[00:13:34] In fact, this is of course a Soviet clone of an Intel 8255A,
[00:13:36] and at that time it was extremely rare,
[00:13:38] Soviet radio hams were ready to sell their soul for a set of this IC family.
[00:13:42] I'll connect everything according to this schematic.
[00:13:44] Everything is quite simple here.
[00:13:45] We will address according to the classical Spectrum idea,
[00:13:49] pulling one of the lines of the address bus to zero, in our case the first by number
[00:13:53] (that is, the second from zero).
[00:13:54] The next two bits will be used to address the desired port,
[00:13:58] i.e. there are four addresses: the 1st, 2nd, 3rd ports, and the 4th is the chip configuration register.
[00:14:04] I used such logical gates, because this is all that I found working, the rest turned out to be dead.
[00:14:09] But here it would be enough to have one two-input logical gate OR.
[00:14:13] The chip itself is made according to the progressive NMOS technology at that time,
[00:14:17] it is compatible with TTL and withstands a higher current at the low logical level than at the high level,
[00:14:22] and therefore we will connect the LEDs to the power bus
[00:14:25] and output inverted values to the ports so that the LED lights up
[00:14:29] when the output of the corresponding bit of the corresponding port will be a logical zero.
[00:14:34] Here I must say that according to the datasheet the outputs should hold 2.5mA,
[00:14:39] but I have 1k resistors here and therefore 5mA.
[00:14:42] Nevertheless, the forums are full of messages from people who connected lots of strange loads to this type of logic
[00:14:47] and it seems like in most cases it worked fine
[00:14:50] and even for a long time )
[00:14:51] So for simplicity, let's risk doing this.
[00:14:53] But let's remember for ourselves that this is not right and ay-yai-yai, you don't have to do it that way.
[00:15:03] Unfortunately, the rare chip turned out to be killed by life.
[00:15:07] Look at what an incredible shape it took.
[00:15:09] I also have a clone of the Intel 8080 processor,
[00:15:14] and if we put them together, we find this diastema )))
[00:15:18] And of course this chip does not work.
[00:15:20] I.e. surprisingly it sometimes starts, but it is very unstable.
[00:15:23] So I bought a new, fresh chip, 95th year of manufacture
[00:15:27] and assembled a breadboard on it.
[00:15:29] Then, in the first emulator I came across, I sketched a program in the native Basic.
[00:15:32] Of course, it was terrible.
[00:15:34] The language is quite primitive
[00:15:36] and I remembered why programming then took so much time.
[00:15:40] Very briefly about the code: Array initialization.
[00:15:42] Here each digit is either all bits equal to one, or one bit is zero.
[00:15:47] I did this because there are no shift operations here and it was easier and more versatile.
[00:15:51] Next, we initialize the chip,
[00:15:53] namely, we configure all three ports as outputs.
[00:15:56] Well, then we move the zero bit back and forth across the eight digits of all three ports.
[00:16:01] I will leave a link to the TAP file in the description.
[00:16:04] That's all, actually.
[00:16:05] Let's upload, I'm not afraid of this word, the SKETCH to our hmmm...
[00:16:08] macrocontroller and enjoy the result.
[00:16:21] It turned out to be a 24-bit garland the size of a couple of bricks.
[00:16:25] Although, if not for the size, then in terms of functionality it is quite a modern microcontroller.
[00:16:30] Here we can add more ports, attach the timer,
[00:16:33] add a DAC and ADC and there will be a good kit for children's experiments.
[00:16:37] By the way, write in the comments what else could we can invent on the basis of this grandad
[00:16:41] (options to throw in the trash and mine bitcoins are not accepted as too obvious).
[00:16:46] And finally, I would like to express my strong respect to the engineers of the Chisinau Scientific and Production Association "Signal".
[00:16:52] 30 years have passed, I hope some of them are still in good health.
[00:16:55] The device turned out to be very decent and reliable.
[00:16:58] It still works!
[00:16:59] There are small claims to the materials, but this is not question for engineers.
[00:17:03] Respect, guys!
[00:17:05] Well, that's all for today,
[00:17:05] subscribe, comment and and keep in touch!

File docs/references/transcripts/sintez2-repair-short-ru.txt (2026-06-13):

[00:00:01] О-о-о, красавец!
[00:00:03] ...просто для игр и организации досуга...
[00:00:06] ...каждый приличный человек должен для организации своего досуга иметь паяльник...
[00:00:09] ...на выводах некоторых элементов наросли вот такие кристаллические иглы...
[00:00:13] ...если их сложить вместе, то обнаруживается вот такая диастема...
[00:00:17] А это как художник представляет себе непосредственно досуг.
[00:00:24] Привет, друзья!
[00:00:26] Сегодня немного необычный ролик: я решил поинтересоваться импортозамещением
[00:00:29] и посмотрел какие микроконтроллеры у нас сейчас производятся.
[00:00:39] В общем, номенклатура хоть и не широкая, но выбрать есть из чего...
[00:00:43] но вот правда купить что-то из этого оказалось решительно невозможно.
[00:00:47] И тут я вспомнил что есть у меня старый, древний трупик вот такого дедушки.
[00:00:52] Это советский клон ZX-спектрума, на ТТЛ-чипах.
[00:00:55] Самых что ни на есть импортозаместительных.
[00:00:58] Одна из последних советских разработок.
[00:01:00] Коробка эта не открывалась лет 30 и что там внутри это большой-большой сюрприз.
[00:01:05] Давайте приступим к эксгумации.
[00:01:09] Может он уже разложился на плесень и липовый мёд.
[00:01:20] Тааак...
[00:01:22] Кабель для магнитофона.
[00:01:25] Кабели телевизора и питания.
[00:01:33] Изрядно, конечно тут всё окислилось.
[00:01:42] Блок питания.
[00:01:47] О-о-о, красавец!
[00:01:51] Ну что ж, давайте попробуем реанимировать этого дедулю.
[00:01:55] Прежде чем дать старику разряд давайте посмотрим на состояние блока питания.
[00:01:59] Как я помню, он линейный, в нём стоит тороидальный трансформатор и КРЕНка.
[00:02:03] И насчёт них у меня опасений особых нет, а вот электролиты надо проверить.
[00:02:12] Основной сглаживающий конденсатор тут серии К50-24.
[00:02:15] Это хорошая серия, качественная.
[00:02:18] А вот после КРЕНки стоит серия К50-35 о которой отзывы уже не очень.
[00:02:22] К тому же тут установили красный кондёр-флажок,
[00:02:25] у которого со временем серебряное напыление, которое и является обкладками,
[00:02:28] может диффундировать в керамическую пластину
[00:02:31] и вызывать шумы, а то и вовсе КоЗу.
[00:02:33] Электролит я отпаял и проверил тестером.
[00:02:36] С ним оказалось всё в порядке, ёмкость и ESR в норме.
[00:02:39] Флажок я прозвонил и на удивление он тоже в норме.
[00:02:42] Так что я подключаю ЛБП напрямую к сглаживающему конденсатору,
[00:02:46] ограничиваю ток до 0.01А и оставляю в таком виде на несколько часов,
[00:02:51] чтобы восстановилась оксидная плёнка электролитов.
[00:02:55] Дальше. Я вижу что тут между землёй и КРЕНкой установлен резистор на 39 Ом,
[00:03:00] что довольно странно.
[00:03:02] Во-первых КР142ЕН5В вроде как не подразумевает регулировки выходного напряжения,
[00:03:07] а во-вторых, как я потом выяснил, этого резистора и в схеме нет.
[00:03:11] Из-за него блок питания без нагрузки даёт повышенное напряжение
[00:03:14] в 5.35 вольта, что многовато.
[00:03:17] Ну и под нагрузкой он выдаёт повышенное напряжение.
[00:03:20] Для чего это было сделано я не очень понимаю,
[00:03:23] может чтобы обеспечить повышенное напряжение при запуске компьютера
[00:03:26] или чтобы немного снизить тепловыделение КРЕНки, не знаю.
[00:03:29] Напишите в комментариях если вы знаете зачем это нужно.
[00:03:33] В общем, я решил не убирать совсем этот резистор,
[00:03:35] а впаять параллельно с ним ещё один на 15 Ом.
[00:03:38] Это приблизит выходное напряжение к требуемым 5 вольтам,
[00:03:41] но и задуманный разработчиками эффект хоть и уменьшится, но сохранится.
[00:03:46] С блоком питания всё. Займемся теперь самим комплюктером.
[00:03:49] В нём тоже есть электролиты, так что его я тоже подключаю через ЛБП с ограничением тока
[00:03:55] и постепенно-постепенно этот ток увеличиваю.
[00:04:04] И, о чудо, он включился и выдал картинку.
[00:04:07] Правда в каком-то зелёном оттенке, но это мы без проблем исправим.
[00:04:11] А вот с клавиатурой тут беда: работают только 4 кнопки.
[00:04:14] И работают они не так как должны.
[00:04:17] Всё что можно на нём сейчас набрать это вот такая строчка.
[00:04:20] Клавиатура в нём плёночная и скорее всего она уже сгнила.
[00:04:22] В любом случае, без вскрытия не обойтись, так что приступим.
[00:04:27] А пока я буду его разбирать, давайте ознакомимся с руководством пользователя,
[00:04:30] которое к счастью, у меня тоже сохранилась.
[00:04:32] Компьютер игровой...
[00:04:34] "ЕЫ"...
[00:04:35] Хорошо, смотрим.
[00:04:39] "Внимание!" - сразу 4 вклеечки.
[00:04:42] При подключении джойстиков к компьютеру следите за совпадением
[00:04:45] трапециевидного ключа и контактов разъёма... Понятно.
[00:04:48] В вашем компьютере звонок пьезокерамический ЗП-3,
[00:04:51] розетка и вилка СНП58 не установлены в связи с отсутствием поставки.
[00:04:57] Понятно!
[00:04:58] В данном компьютере вместо микропроцессора Z80A установлен
[00:05:01] микропроцессор КР1858ВМ1, имеющий более высокое быстродействие.
[00:05:07] Отлично!
[00:05:08] В связи с недопоставками в данном компьютере не установлен
[00:05:11] разъём подключения джойстика типа Sinclair 1
[00:05:14] (этот джойстик дублирует цифровые кнопки клавиатуры).
[00:05:17] Внимание!
[00:05:19] Комплект принадлежностей комплектуется тремя предохранителями.
[00:05:22] Отлично, отлично!
[00:05:24] Так, общие указания.
[00:05:26] Компьютер игровой программно совместим с компьютером ZX Spectrum 48.
[00:05:31] Всё понятно, хорошо.
[00:05:32] Катушечный магнитофон... бытовой кассетный магнитофон...
[00:05:35] В качестве дисплея может быть использован видеомонитор "Электроника"
[00:05:38] или бытовой цветной телевизор.
[00:05:42] Замечательно!
[00:05:44] Так, комплект поставки.
[00:05:45] Это то что у нас в коробке.
[00:05:48] Характеристики.
[00:05:49] Тип микропроцессора Z80 (но на самом деле нет).
[00:05:53] Тактовая частота 3.5МГц.
[00:05:55] А тут у нас установлен кварцевый резонатор на 14.3МГц,
[00:06:00] т.е. соответственно, наверняка там делится на 4 и получается 3.575МГц.
[00:06:07] Ну действительно, чуть-чуть побыстрее.
[00:06:09] Ёмкость ОЗУ, ёмкость ПЗУ... Разрешение экрана... всё понятно.
[00:06:14] Краткое описание изделия.
[00:06:16] Компьютер игровой предназначен для пользователей,
[00:06:18] работа или учёба которых связана с применением компьютеров,
[00:06:21] а также для желающих использовать компьютер в домашних условиях
[00:06:24] для самостоятельного изучения основ информатики
[00:06:26] и просто для игр и организации досуга.
[00:06:29] Отлично! Сейчас организуем досуг.
[00:06:32] Подготовка к работе и порядок работы с изделием.
[00:06:35] На блок питания не ставить посторонние предметы.
[00:06:38] Хорошо, не будем.
[00:06:40] Тааак, подключаем джойстики, магнитофон... регулировка цветов... загружаем программу.
[00:06:46] Всё понятно. Здесь всё ясно.
[00:06:50] Гарантийные обязательства.
[00:06:53] Свидетельство о приемке.
[00:06:55] Март 1992 года.
[00:06:57] Так, дальше гарантийные талоны.
[00:07:03] Много гарантийных талонов.
[00:07:06] Ага, вот! Рекомендации по подключению компьютера к телевизору или видеомонитору.
[00:07:12] Характеристики сигналов.
[00:07:13] Тут подробно про все сигналы, которые можно получить с видеочасти платы.
[00:07:19] Всё понятно, всё ясно.
[00:07:21] Перед самостоятельной доработкой телевизора следует изучить схему телевизора.
[00:07:26] Изучим. А как же? Конечно!
[00:07:28] В случае затруднений при доработке необходимо обратиться
[00:07:30] для консультации в телеателье или к опытному радиолюбителю
[00:07:33] (если вы таковым не являетесь))).
[00:07:36] Тааак, подключение к телевизору.
[00:07:38] Для того чтобы перевести... в режим монитора... ла-ла-ла... подать соответствующие... так, всё ясно...
[00:07:44] Доработка телевизоров типа 3УСЦТ и 4УСЦТ, имеющих модули цветности типа МЦ-31...
[00:07:51] я не понимаю, почему в комплекте поставки нет паяльника?
[00:07:56] Ну, хотя наверное каждый приличный человек должен
[00:07:58] для организации своего досуга иметь паяльник и всё остальное.
[00:08:02] ОК.
[00:08:03] Установить и распаять дополнительную розетку типа ОНЦ.
[00:08:05] Хорошо, установили.
[00:08:07] .....
[00:08:11] Ну, допустим. Хорошо )))
[00:08:13] .....
[00:08:20] В принципе дураку ясно должно быть.
[00:08:22] Всё понятно, всё просто.
[00:08:24] Любой нормальный человек, если он не совсем дебил
[00:08:27] легко модернизирует модуль цветности МЦ-31, МЦ-41, МЦ-402, 403!
[00:08:34] Ну... какие могут быть проблемы?
[00:08:37] Всё понятно.
[00:08:38] Продолжаем.
[00:08:39] Так, здесь у нас доработка модуля цветности.
[00:08:43] Ну, в общем всё понятно, всё просто.
[00:08:46] Вопросов нет.
[00:08:48] На секунду прервёмся, тут есть кое-что интересное.
[00:08:51] После разборки я сразу заклеиваю ПЗУшку с ультрафиолетовым стиранием,
[00:08:55] чтобы фонарями случайно не стереть прошивку
[00:08:58] и тут я замечаю интересное физическое явление:
[00:09:00] на выводах некоторых элементов наросли вот такие кристаллические иглы.
[00:09:04] Я не очень понимаю природу явления,
[00:09:06] если кто-то знает чем это вызвано - пишите в комментариях.
[00:09:09] Я не проверял, но подозреваю что эти кристаллы могут быть проводящими,
[00:09:12] так что повезло что ничего не коротнуло.
[00:09:16] Продолжаем с инструкцией.
[00:09:17] Тут у нас принципиальная схема.
[00:09:20] Большая, подробная.
[00:09:22] Я её отсканировал. Ссылочку оставлю в описании, если интересно - изучите.
[00:09:26] Мы тогда сейчас не будем на ней подробно останавливаться.
[00:09:32] Дальше расположение элементов на плате.
[00:09:35] Тоже полезно.
[00:09:38] Схема клавиатуры.
[00:09:39] Ну тут довольно мелко и неразборчиво, но в принципе всё понять можно.
[00:09:43] Схема блока питания.
[00:09:48] А это как художник представляет себе непосредственно досуг.
[00:09:53] Ну, да... Вот, рыбка...
[00:09:55] Хорошо.
[00:09:57] Дальше адреса сервисных центров,
[00:10:00] ну и собственно всё, на этом инструкция заканчивается.
[00:10:03] Возвращаемся к нашему артефакту.
[00:10:05] Наросшие непонятные кристаллы я почистил, и занялся клавиатурой,
[00:10:09] которая к сожалению окончательно разложилась.
[00:10:11] Восстановить её уже не удастся и очевидно придётся заказывать новую.
[00:10:15] Я попробовал восстановить несколько дорожек контактолом,
[00:10:18] заработало ещё несколько клавиш, но принципиально ситуация не улучшилась.
[00:10:22] А клавиатура тут не простая, она тут пятислойная:
[00:10:24] три контактных слоя и два промежуточных.
[00:10:27] Это надо для работы дополнительных клавиш,
[00:10:29] например таких как стрелки влево/вправо, вверх/вниз ну и других.
[00:10:32] Т.е. при нажатии стрелки вверх, замыкаются одновременно две цепи,
[00:10:36] одна это как бы Caps Shift, а вторая как бы клавиша цифры 7.
[00:10:39] На всякий случай убедимся что проблема именно в клавиатуре, а не в каких-то цепях, на плате.
[00:10:44] Для этого я поочерёдно замыкаю все контакты одного разъёма со всеми контактами другого,
[00:10:48] что даёт нам 40 возможных пересечений
[00:10:51] и соответственно, именно отсюда идут 40 клавиш оригинального ZX Spectrum
[00:10:55] (не того, который плюс).
[00:10:56] Ну, отлично, все линии работают, значит проблема именно в клавиатуре.
[00:11:00] Давайте теперь возместим всё недопоставленное,
[00:11:03] чтобы наконец-то, спустя 30 лет, комплект уже был полным.
[00:11:06] Начнём с разъёма СНП58-64,
[00:11:09] на который выведены буквально все ножки процессора плюс шина питания.
[00:11:13] Это конечно очень удобно для проектирования и для подключения всякой периферии.
[00:11:17] Как я понял по найденным в инете схемам, в оригинальном ZX Spectrum+ было сделано точно так же,
[00:11:21] только разъём, само-собой, был другой.
[00:11:24] В целом, конкретно этот клон по своей архитектуре сильно отличается от оригинала тем,
[00:11:27] что в оригинальном Спектруме использовалась заказная микросхема,
[00:11:30] обеспечивающая всю периферийную логику компьютера от графической системы до портов.
[00:11:36] Для отечественных клонов тоже изготавливались подобные чипы,
[00:11:38] но конкретно эта модель построена на базе дискретных элементов, что конечно удорожало конструкцию.
[00:11:44] Но этим он в том числе и ценен.
[00:11:46] Дальше разъём джойстика Sinclair.
[00:11:48] Их тут задумывалось два, но один недодали.
[00:11:51] Джойстики этого типа дублируют цифровые кнопки клавиатуры:
[00:11:54] первый с единицы по пятёрку, а второй с шестёрки до нуля.
[00:11:57] Так что никаких дополнительных элементов для джойстика на плате не требуется,
[00:12:01] в отличие, например, от джойстика Kempston,
[00:12:03] для которого установлен 8-битный чип регистра и несколько элементов обвязки.
[00:12:10] Дальше я заменил подстроечные резисторы СП3-38А,
[00:12:13] которые были в ужасном состоянии.
[00:12:15] Благо всё это ещё продаётся
[00:12:17] и можно сохранить оригинальную конструкцию без всякого пионеринга.
[00:12:21] Но, надо сказать, что даже новые эти резисторы совершенно отвратительного качества.
[00:12:25] Картонные, тугие и с очень плохим контактом.
[00:12:28] Но зато оригинальные.
[00:12:32] Ну и последний штрих это пьезоэлектрическая пищалка ЗП-3,
[00:12:36] она тоже всё ещё есть в продаже и тоже ужасного качества.
[00:12:39] На плате все элементы для её работы присутствуют, так что припаиваем...
[00:12:46] подклеиваем к плате, чтобы не болталась...
[00:12:51] и готово!
[00:12:53] А пока я ещё не начертил и не заказал новую клавиатуру, я решил подпаяться напрямую к её разъёмам,
[00:12:58] чтобы не тыкать в них проводами и не погнуть хрупкие контакты.
[00:13:02] Меня звали Владислав Тыкающий
[00:13:06] После чего я соорудил вот такую мини-клаву.
[00:13:09] Тут всего 6 кнопок:
[00:13:11] это кнопка "J" или команда "LOAD",
[00:13:13] дальше кнопка SHIFT,
[00:13:15] следующая кнопка "P", которая в сочетании с шифтом даёт кавычки.
[00:13:19] Кнопка "R" она же команда "RUN"
[00:13:21] и кнопка ввода.
[00:13:22] Чтобы было веселее экспериментировать, я нашёл в своих закромах
[00:13:25] вот такую микросхемку 88 года выпуска.
[00:13:28] Это три двунаправленных восьмиразрядных порта ввода-вывода с кучей всяких дополнительных функций.
[00:13:34] На самом деле, это конечно же советский клон интеловского чипа,
[00:13:36] причём по тем временам довольно редкий,
[00:13:38] за комплект этой линейки советские радиолюбители готовы были душу продать.
[00:13:42] Подключаем всё вот по такой схеме.
[00:13:44] Тут всё элементарно просто.
[00:13:45] Адресоваться будем классическим спектрумовским способом,
[00:13:49] опуская в ноль один из разрядов адресной шины, в нашем случае первый по номеру
[00:13:53] (то есть второй по счёту с нуля).
[00:13:54] Следующие два разряда шины адреса будем использовать для адресации нужного порта,
[00:13:58] т.е. всего четыре адреса: 1-й, 2-й, 3-й порты, а 4-й это регистр конфигурации чипа.
[00:14:04] Логика тут такая, потому что это всё что нашлось у меня рабочего, остальное оказалось убитое.
[00:14:09] Но тут достаточно было бы одного двухвходового элемента ИЛИ.
[00:14:13] Сама микросхема выполнена по прогрессивной на то время технологии NMOS,
[00:14:17] она совместима с ТТЛ и выдерживает по уровню нуля больший ток, чем по уровню единицы,
[00:14:22] а следовательно будем подключать светодиоды к плюсовой шине
[00:14:25] и выдавать в порты инвертированные значения, чтобы зажигался тот светодиод,
[00:14:29] на выходе соответствующего разряда соответствующего порта которого будет логический ноль.
[00:14:34] Тут надо сказать, что по паспорту выходы вроде должны держать 2.5мА,
[00:14:39] а у меня тут резисторы по килоому и следовательно 5мА.
[00:14:42] Но на форумах полно сообщений от людей, которые чего только к этой логике не подключали
[00:14:47] и вроде как в большинстве случаев оно работало нормально.
[00:14:50] И даже долго )
[00:14:51] Так что для простоты рискнём сделать так.
[00:14:53] Но для себя запомним что это неправильно и ай-ай-ай, и так делать не надо.
[00:15:03] К несчастью, раритетная микросхемка оказалась убитая жизнью.
[00:15:07] Посмотрите, какую она приняла невероятную форму.
[00:15:09] У меня есть ещё клон интеловского процессора 8080 из той же серии,
[00:15:14] и если их сложить вместе, то обнаруживается вот такая диастема )))
[00:15:18] Ну и конечно же этот чип не работает.
[00:15:20] Т.е. на удивление он иногда запускается, но очень нестабильно.
[00:15:23] Так что я купил новую, свежую чипулину, 95-го года выпуска
[00:15:27] и собрал макетку на ней.
[00:15:29] Дальше в первом попавшемся эмуляторе я набросал программку на родном бейсике.
[00:15:32] Это конечно, было ужасно.
[00:15:34] Язык совсем примитивный
[00:15:36] и я вспомнил почему на программирование у меня тогда уходило столько времени.
[00:15:40] Совсем коротенечко по коду: Инициализируем массив.
[00:15:42] Тут каждая цифра это либо все биты в единице, либо один бит равен нулю.
[00:15:47] Сделал так, потому что сдвиговых операций тут нет и так было проще и универсальнее.
[00:15:51] Дальше инициализируем микросхему,
[00:15:53] а именно настраиваем все три порта в качестве выходов.
[00:15:56] Ну а дальше туда-сюда-обратно перемещаем нулевой бит по восьми разрядам всех трёх портов.
[00:16:01] Ссылку на TAP-файл я оставлю в описании.
[00:16:04] Вот, собственно и всё.
[00:16:05] Загружаем, не побоюсь этого слова, СКЕТЧ в наш мммм...
[00:16:08] мАкроконтроллер и наслаждаемся результатом.
[00:16:21] Получилась такая 24-разрядная гирлянда размером с пару кирпичей.
[00:16:25] Хотя, если бы не размеры, то по функционалу это вполне себе современный микроконтроллер.
[00:16:30] Сюда можно докинуть ещё портов, прикрутить таймер,
[00:16:33] добавить ЦАП и АЦП и будет нормальный стенд для детских экспериментов.
[00:16:37] Кстати, напишите в комментариях что ещё можно было бы придумать на базе этого старичка
[00:16:41] (варианты выкинуть на помойку и майнить биткойны не принимаются как слишком очевидные).
[00:16:46] Ну и напоследок хочется выразить мощнейший респектище разработчикам Кишинёвского НПО "Сигнал".
[00:16:52] 30 лет прошло, надеюсь кто-то из них ещё в добром здоровье.
[00:16:55] Устройство получилось очень достойное и надёжное.
[00:16:58] До сих пор работает!
[00:16:59] Есть небольшие претензии к материалам, но это уже не к разработчикам вопрос.
[00:17:03] Респект, ребята!
[00:17:05] Ну а у меня на сегодня всё.
[00:17:05] Подписывайтесь, комментируйте и до связи!

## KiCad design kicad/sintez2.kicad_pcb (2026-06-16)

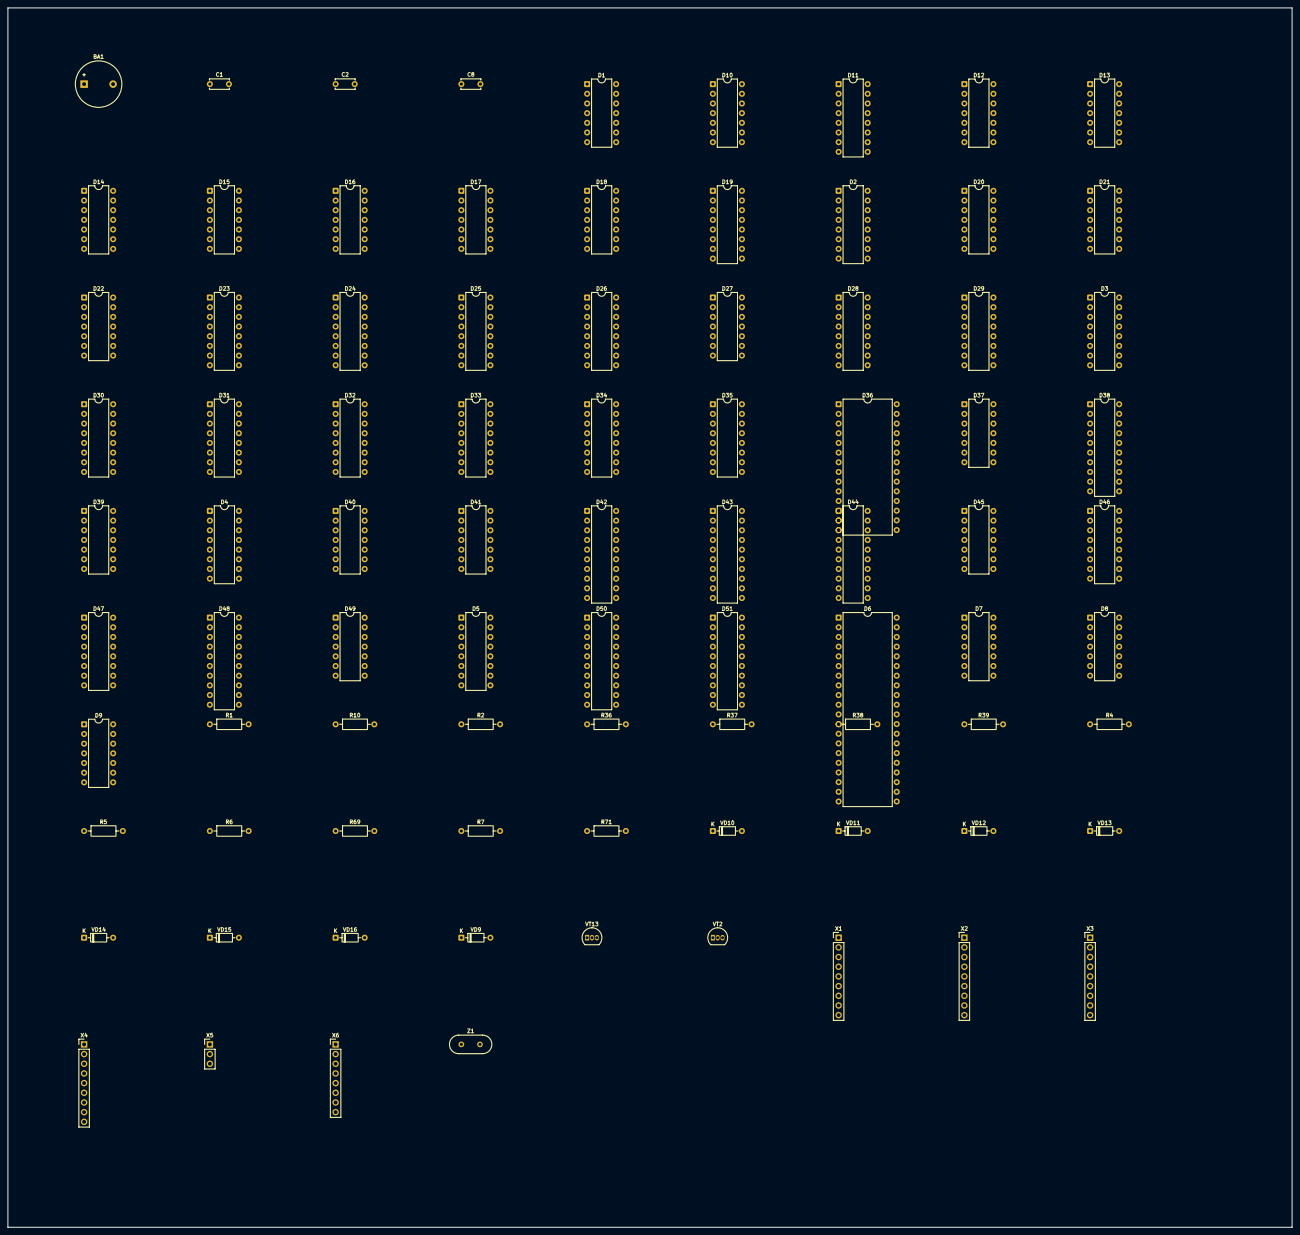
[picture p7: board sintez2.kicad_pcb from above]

Board: 2 copper layers, 337.0 x 320.0 mm, 85 parts (0 on the bottom side), 141 nets, no tracks yet.

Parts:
BA1: ЗП-3; Buzzer_12x9.5RM7.6
C1: 330p; C_Disc_D5.0mm_W2.5mm_P5.00mm
C2: 10u; C_Disc_D5.0mm_W2.5mm_P5.00mm
C8: 0.022u; C_Disc_D5.0mm_W2.5mm_P5.00mm
D1, D9, D15, D16: К1533ЛН1 (74LS04); DIP-14_W7.62mm
D2, D3, D4, D19: К1533ИЕ7 (74193); DIP-16_W7.62mm
D5: К1533КП11 (74LS257); DIP-16_W7.62mm
D6: КР1858ВМ1/Z84C00; DIP-40_W15.24mm
D7, D13: К1533ЛИ1 (74LS08); DIP-14_W7.62mm
D8, D12, D20, D21: К1533ТМ2 (74LS74); DIP-14_W7.62mm
D10, D27, D37: К1533ЛА4 (74ALS10); DIP-14_W7.62mm
D11: К561ИЕ10 (CD4520); DIP-16_W7.62mm
D14, D22: К1533ЛЕ1 (74LS02); DIP-14_W7.62mm
D17: К1533ЛА3 (74ALS00); DIP-14_W7.62mm
D18: К1533ЛП5 (74LS86); DIP-14_W7.62mm
D23, D24, D25, D26, D46, D47: К1533КП12 (74ALS253); DIP-16_W7.62mm
D28, D29, D30, D31, D32, D33, D34, D35: К565РУ5 (4164); DIP-16_W7.62mm
D36: 27128 (ПЗУ); DIP-28_W15.24mm
D38: КР1533ИР27 (74273); DIP-20_W7.62mm
D39, D40, D41, D45: К555ИР16 (4-bit shift, keep LS); DIP-14_W7.62mm
D42: К1533ИР23 (74LS374); DIP-20_W7.62mm
D43, D44, D48, D51: К1533ИР22 (74LS373); DIP-20_W7.62mm
D49: К544СА3 (comparator); DIP-14_W7.62mm
D50: К1533АП3 (74LS244); DIP-20_W7.62mm
R1, R2: 470; R_Axial_DIN0207_L6.3mm_D2.5mm_P10.16mm_Horizontal
R4, R5, R6, R7, R10, R36, R39: 5.1k; R_Axial_DIN0207_L6.3mm_D2.5mm_P10.16mm_Horizontal
R37: 1.8M; R_Axial_DIN0207_L6.3mm_D2.5mm_P10.16mm_Horizontal
R38: 3k; R_Axial_DIN0207_L6.3mm_D2.5mm_P10.16mm_Horizontal
R69: 33k; R_Axial_DIN0207_L6.3mm_D2.5mm_P10.16mm_Horizontal
R71: 820; R_Axial_DIN0207_L6.3mm_D2.5mm_P10.16mm_Horizontal
VD9, VD10, VD11, VD12, VD13, VD14, VD15, VD16: КД522; D_DO-35_SOD27_P7.62mm_Horizontal
VT2, VT13: КТ315; TO-92_Inline
X1: JoyL; PinHeader_1x09_P2.54mm_Vertical
X2: JoyR; PinHeader_1x09_P2.54mm_Vertical
X3: Kbd; PinHeader_1x09_P2.54mm_Vertical
X4: DiskDO; PinHeader_1x09_P2.54mm_Vertical
X5: Tape; PinHeader_1x03_P2.54mm_Vertical
X6: DiskAA; PinHeader_1x08_P2.54mm_Vertical
Z1: 14MHz; Crystal_HC49-U_Vertical

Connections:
+5V: D1.14, D2.16, D3.16, D4.16, D5.16, D6.11, D7.14, D8.1, D8.4, D8.10, D8.13, D8.14, D9.14, D10.14, D11.16, D12.14, D13.14, D14.14, D15.14, D16.14, D17.14, D18.14, D19.16, D20.14, D21.14, D22.14, D23.16, D24.16, D25.16, D26.16, D27.14, D28.8, D29.8, D30.8, D31.8, D32.8, D33.8, D34.8, D35.8, D36.1, D36.27, D36.28, D37.14, D38.20, D39.14, D40.14, D41.14, D42.20, D43.20, D44.20, D45.14, D46.16, D47.16, D48.20, D49.2, D49.11, D50.20, D51.20, R4.1, R5.1, R6.1, R7.1, R10.1, R36.1, R38.2, R71.1
A0: D6.30, D23.6, D36.10, R39.1
A1: D6.31, D23.10, D36.9
A2: D6.32, D24.6, D36.8
A3: D6.33, D24.10, D36.7
A4: D6.34, D25.6, D36.6
A5: D6.35, D23.11, D36.5
A6: D6.36, D24.5, D36.4
A7: D6.37, D24.11, D36.3
A8: D6.38, D25.10, D36.25, D50.2
A9: D6.39, D26.6, D36.24, D50.4
A10: D6.40, D23.5, D36.21, D50.6
A11: D6.1, D25.5, D36.23, D50.8
A12: D6.2, D25.11, D36.2, D50.13
A13: D6.3, D26.5, D36.26, D50.11
A14: D6.4, D22.2, D26.10, D50.17
A15: D6.5, D22.3, D26.11, D50.15
AA8: VD9.2, X6.6
AA9: VD10.2, X6.3
AA10: VD11.2, X6.2
AA11: VD12.2, X1.7, X6.1
AA12: VD15.2, X2.7, X6.4
AA13: VD16.2, X6.5
AA14: VD13.2, X6.7
AA15: VD14.2, X6.8
ARB_OE0: D23.1, D24.1, D25.1, D26.1
ARB_SELA: D23.14, D24.14, D25.14, D26.14
ARB_SELB: D23.2, D24.2, D25.2, D26.2
B0: D42.2, D46.5
B1: D42.9, D46.6
BB: D46.3, D46.4, D48.2
BM: D45.2, D46.7
BORDER: D46.2, D47.2
CLK: D6.6, D8.9
CLK7: D2.5, D8.5, D8.11
CLK14: D1.4, D8.3, D39.9, D40.9, D41.9, D45.9, R2.2
D0: D6.14, D28.2, D36.11, D43.2, D44.2, D48.3, D51.2
D1: D6.15, D29.2, D36.12, D43.5, D44.5, D48.4, D51.5
D2: D6.12, D30.2, D36.13, D43.6, D44.6, D48.7, D51.6
D3: D6.8, D31.2, D36.15, D43.9, D44.9, D48.13, D51.9
D4: D6.7, D32.2, D36.16, D43.12, D44.12, D48.8, D51.12
D5: D6.9, D33.2, D36.17, D43.15, D44.15, D51.15
D6: D6.10, D34.2, D36.18, D43.16, D44.16, D51.16
D7: D6.13, D35.2, D36.19, D43.19, D44.19, D51.19
D49_QK: D49.9, R37.2, R38.1, R39.2
D50_OE: D50.1, D50.19
DO0: X1.3, X2.9, X4.4
DO1: X1.2, X2.5, X4.5
DO2: X1.4, X2.4, X4.6
DO3: X1.5, X2.2, X4.7
DO4: X1.9, X2.3, X4.8
G0: D42.6, D47.5
G1: D42.15, D47.6
GB: D47.3, D47.4, D48.6
GM: D45.4, D47.7
GND: C1.2, C2.2, D1.7, D2.8, D3.8, D4.8, D5.8, D5.15, D6.29, D7.7, D8.7, D9.7, D10.7, D11.8, D12.7, D13.7, D14.7, D15.7, D16.7, D17.7, D18.7, D19.8, D20.7, D21.7, D22.7, D23.8, D23.15, D24.8, D24.15, D25.8, D25.15, D26.3, D26.8, D26.13, D26.15, D27.7, D28.16, D29.16, D30.16, D31.16, D32.16, D33.16, D34.16, D35.16, D36.14, D37.7, D38.1, D38.10, D39.6, D39.7, D39.8, D40.6, D40.7, D40.8, D41.1, D41.6, D41.7, D41.8, D42.1, D42.10, D43.10, D44.1, D44.10, D44.11, D44.14, D44.17, D44.18, D45.1, D45.7, D45.8, D46.8, D46.15, D47.8, D47.15, D48.1, D48.10, D49.6, D50.10, D51.10, D51.11, D51.14, D51.18, VT2.1, VT13.1, X5.2
H1: D2.3, D23.12
H2: D2.2, D24.4
H3: D2.6, D24.12
H4: D2.7, D25.4
J0: D44.3, X3.2
J1: D44.4, X3.3
J2: D44.7, X3.4
J3: D44.8, X3.5
J4: D44.13, X3.9
K8: D5.12, D25.12
K9: D5.9, D26.4
K10: D7.6, D23.3
K11: D5.7, D25.3
K12: D5.4, D25.13
MEM_STB: D13.4, D13.9
MREQ_H: D9.2, D17.2
unnamed: D8.2, D8.6
unnamed: D8.8, D8.12
unnamed: D2.12, D19.5
unnamed: D3.5, D19.12
unnamed: D3.12, D4.5
unnamed: D40.1, D41.10
unnamed: D13.12, D39.1, D40.10
unnamed: C8.2, D49.4, R36.2, R37.1
OSC_IN: C1.1, D1.1, R1.1, Z1.1
OSC_MID: D1.2, D1.3, R1.2, R2.1, Z1.2
PIX_SER: D18.9, D39.10
R0: D42.5, D46.11
R1: D42.12, D46.10
RB: D46.12, D46.13, D48.5
RM: D45.3, D46.9
ROM_REGION: D17.1, D22.1
SPK_VT2_COLL: BA1.2, R69.1, VT2.3
TAPE_IN: C8.1, X5.3
V0: D3.3, D5.13
V1: D3.2, D5.10
V2: D3.6, D7.5
V3: D3.7, D23.13
V4: D4.3, D24.3
V5: D4.2, D24.13
V6: D4.6, D5.6, D5.14
V7: D4.7, D5.3, D5.11
VA0: D23.7, D28.5, D29.5, D30.5, D31.5, D32.5, D33.5, D34.5, D35.5
VA1: D23.9, D28.7, D29.7, D30.7, D31.7, D32.7, D33.7, D34.7, D35.7
VA2: D24.7, D28.6, D29.6, D30.6, D31.6, D32.6, D33.6, D34.6, D35.6
VA3: D24.9, D28.12, D29.12, D30.12, D31.12, D32.12, D33.12, D34.12, D35.12
VA4: D25.7, D28.11, D29.11, D30.11, D31.11, D32.11, D33.11, D34.11, D35.11
VA5: D25.9, D28.10, D29.10, D30.10, D31.10, D32.10, D33.10, D34.10, D35.10
VA6: D26.7, D28.13, D29.13, D30.13, D31.13, D32.13, D33.13, D34.13, D35.13
VA7: D26.9, D28.9, D29.9, D30.9, D31.9, D32.9, D33.9, D34.9, D35.9
VD0: D41.2, D42.3, D43.3
VD1: D41.3, D42.4, D43.4
VD2: D41.4, D42.7, D43.7
VD3: D41.5, D42.8, D43.8
VD4: D40.2, D42.13, D43.13
VD5: D40.3, D42.14, D43.14
VD6: D40.4, D42.17, D43.17
VD7: D40.5, D42.18, D43.18
VID_OE: D46.1, D47.1
VID_SEL: D46.14, D47.14
VT13_BASE: BA1.1, R69.2, VT13.2
VT13_COLL: R71.2, VT13.3
Y: D42.16, D47.10, D47.11
YM: D45.5, D47.9
a2: D5.2, D5.5, D26.12
dA8: D50.18, VD9.1
dA9: D50.16, VD10.1
dA10: D50.14, VD11.1
dA11: D50.12, VD12.1
dA12: D50.7, VD15.1
dA13: D50.9, VD16.1
dA14: D50.3, VD13.1
dA15: D50.5, VD14.1
nS2: D5.1, D7.4
~BUSRQ: D6.25, R6.2
~CAS: D13.8, D28.15, D29.15, D30.15, D31.15, D32.15, D33.15, D34.15, D35.15
~INT: D6.16, R4.2
~MREQ: D6.19, D9.1
~NMI: D6.17, R5.2
~RAS: D13.6, D28.4, D29.4, D30.4, D31.4, D32.4, D33.4, D34.4, D35.4
~RESET: C2.1, D6.26, R10.2
~ROMCS: D17.3, D36.20
~ROMOE: D6.21, D36.22
~WAIT: D6.24, R7.2
~WR: D6.22, D28.3, D29.3, D30.3, D31.3, D32.3, D33.3, D34.3, D35.3

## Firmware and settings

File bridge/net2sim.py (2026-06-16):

#!/usr/bin/env python3
"""net2sim.py — KiCad netlist (from SKiDL) -> SimulIDE .sim1 circuit.

Canonical bridge direction (spec §7, milestone T3). Reads kicad/sintez2.net,
maps each component to a SimulIDE library item, and emits sim/circuits/sintez2.sim1
with one Node + Connectors per net so it loads and runs in SimulIDE.

Pin mapping:
  • 74xx ICs  -> Subcircuit; pin NUMBER -> pin id read from SimulIDE's .package file
                 (so it is exact for whatever SimulIDE part we point at).
  • Z80       -> the SimulIDE Z80 model, mapped by a fixed number->id table.
  • R / C     -> Resistor / Capacitor items.
  • Power     -> +5V net to a Rail, GND to Ground.
Family timing (К555 LS vs К1533 ALS) selects the _LS.package variant where present.

v0 scope: emits all parts it can map cleanly + their nets; ROM/DRAM (SimulIDE
built-in Memory items, pinned differently) and a few non-exact parts are reported
as TODO rather than mis-wired. Run:
    .venv/bin/python bridge/net2sim.py
"""
import os, re, sys

ROOT = os.path.dirname(os.path.dirname(os.path.abspath(__file__)))
NET  = os.path.join(ROOT, "kicad", "sintez2.net")
OUT  = os.path.join(ROOT, "sim", "circuits", "sintez2.sim1")
SIM_DATA = os.path.expanduser(
    "~/.local/opt/simulide/SimulIDE_1.1.0-SR2_Lin64/data")

# SKiDL part name -> SimulIDE mapping.
#   kind: 'ic' (Subcircuit, .package-mapped), 'z80', 'mem', 'R', 'C', 'xtal'
#   sim : SimulIDE part folder name under data/ICs (for 'ic')
#   ls  : prefer the _LS.package (LS-family timing) when True
#   note: coverage caveat
PART_MAP = {
    "Z84C00":    {"kind": "z80"},
    "27128":     {"kind": "mem", "note": "ROM: SimulIDE Memory built-in (16Kx8) — pin-map TODO"},
    "K565RU5":   {"kind": "mem", "note": "DRAM РУ5 1-bit: behavioral model TODO (T5)"},
    "K1533TM2":  {"kind": "ic", "sim": "74HC74"},
    "K1533IE7":  {"kind": "ic", "sim": "74HC193"},
    "K1533KP11": {"kind": "ic", "sim": "74HC257"},
    "K1533KP12": {"kind": "ic", "sim": "74HC153", "note": "74HC153≈КП12 but non-tristate"},
    "K1533IR22": {"kind": "ic", "sim": "74HC373"},
    "K1533IR23": {"kind": "ic", "sim": "74HC374"},
    "KR1533IR27":{"kind": "ic", "sim": "74HC273"},
    "K1533AP3":  {"kind": "ic", "sim": "74XX244"},
    "K555IR16":  {"kind": "ic", "sim": "74XX166", "ls": True, "fam": "LS_IR16", "note": "74166 is 8-bit; ИР16 is 4-bit"},
    "K1533LN1":  {"kind": "ic", "sim": "74HC04"},
    "K1533LA3":  {"kind": "ic", "sim": "74HC00"},
    "K1533LA4":  {"kind": "ic", "sim": "74HC00", "note": "no 3-in NAND (74HC10) in lib; 74HC00 is 2-in — APPROX"},
    "K1533LI1":  {"kind": "ic", "sim": "74HC08"},
    "K1533LE1":  {"kind": "ic", "sim": "74HC02"},
    "R":         {"kind": "R"},
    "C":         {"kind": "C"},
    "Crystal":   {"kind": "xtal"},
}

# Z80 DIP-40 pin number -> SimulIDE Z80 *MCU* pin id. The MCU (itemtype="MCU")
# names its pins PORTA<n> (addr), PORTD<n> (data), CPORT0<SIG> (control) — NOT the
# .package ids. (From examples/Micro/Z80/ZX_Spectrum/*.sim1.) Vcc/Gnd are internal.
Z80_PINS = {
    1:"PORTA11",2:"PORTA12",3:"PORTA13",4:"PORTA14",5:"PORTA15",6:"CPORT0CLK",
    7:"PORTD4",8:"PORTD3",9:"PORTD5",10:"PORTD6",12:"PORTD2",13:"PORTD7",
    14:"PORTD0",15:"PORTD1",16:"CPORT0INT",17:"CPORT0NMI",18:"CPORT0HALT",
    19:"CPORT0MREQ",20:"CPORT0IORQ",21:"CPORT0RD",22:"CPORT0WR",23:"CPORT0BUSAK",
    24:"CPORT0WAIT",25:"CPORT0BUSRQ",26:"CPORT0RESET",27:"CPORT0M1",28:"CPORT0RFSH",
    30:"PORTA0",31:"PORTA1",32:"PORTA2",33:"PORTA3",34:"PORTA4",35:"PORTA5",
    36:"PORTA6",37:"PORTA7",38:"PORTA8",39:"PORTA9",40:"PORTA10",
}

# Per-logic-family SimulIDE timing (from the verified family-timing table). К1533=ALS
# (fast), К555=LS (slower), К555ИР16=LS with the deliberate ~27ns setup-margin choice
# (spec §3 — must NOT be ALS). Applied to each Subcircuit so LS vs ALS is preserved.
FAMILY = {
    "ALS":      'Tpd_ps="4000 ps" Tr_ps="2000 ps" Tf_ps="2000 ps" Out_High_V="3.4 V" Out_Low_V="0.35 V" Out_Imped="50 Ω"',
    "LS":       'Tpd_ps="15000 ps" Tr_ps="6000 ps" Tf_ps="6000 ps" Out_High_V="3.4 V" Out_Low_V="0.35 V" Out_Imped="160 Ω"',
    "LS_IR16":  'Tpd_ps="27000 ps" Tr_ps="8000 ps" Tf_ps="8000 ps" Out_High_V="3.4 V" Out_Low_V="0.35 V" Out_Imped="160 Ω"',
}

def parse_netlist(path):
    t = open(path).read()
    comps = {}
    cseg = t[t.index("(components"):t.index("(libparts") if "(libparts" in t else t.index("(nets")]
    for b in re.split(r"\n    \(comp\b", cseg)[1:]:
        ref = re.search(r'\(ref "([^"]+)"\)', b)
        part = re.search(r'\(part "([^"]+)"\)', b)
        val = re.search(r'\(value "([^"]*)"\)', b)
        if ref and part:
            comps[ref.group(1)] = {"part": part.group(1), "value": val.group(1) if val else ""}
    nets = []
    nseg = t[t.index("(nets"):]
    for b in re.split(r"\n    \(net\n", nseg)[1:]:
        nm = re.search(r'\(name "([^"]+)"\)', b)
        nodes = re.findall(r'\(ref "([^"]+)"\)\s*\(pin "([^"]+)"\)', b)
        if nm:
            nets.append((nm.group(1), nodes))
    return comps, nets

def package_pinmap(simpart, ls):
    """Read SimulIDE .package -> {pin_number(str): pin_id}."""
    d = os.path.join(SIM_DATA, "ICs", simpart)
    f = os.path.join(d, f"{simpart}_LS.package" if ls else f"{simpart}.package")
    if not os.path.exists(f):
        f = os.path.join(d, f"{simpart}.package")
    if not os.path.exists(f):
        return None
    txt = open(f).read()
    m = {}   # pin_number -> (id, xpos, ypos, angle)
    for i, mm in enumerate(re.finditer(r'<pin\b([^>]*)/>', txt), 1):
        attrs = mm.group(1)
        pid = re.search(r'\bid="([^"]+)"', attrs)
        xp = re.search(r'\bxpos="(-?\d+)"', attrs)
        yp = re.search(r'\bypos="(-?\d+)"', attrs)
        ang = re.search(r'\bangle="(-?\d+)"', attrs)
        num = re.search(r'packagePin(\d+)', txt[mm.end():mm.end()+40])
        n = num.group(1) if num else str(i)
        if pid:
            m[n] = (pid.group(1), int(xp.group(1)) if xp else 0,
                    int(yp.group(1)) if yp else 0, int(ang.group(1)) if ang else 0)
    return m
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

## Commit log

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2026-06-13 Inaugurate Sintez 2 project: spec, decisions, ledger, repo skeleton
    - Register canonical tech spec at docs/spec/sintez2-recon-spec.md
    - Record four non-negotiable constraints as decision records (0001-0004)
    - Seed discussion ledger: inception, architecture, tooling, sourcing topics
    with the project charter (resolved) and open questions
    - Lay down spec §9 repo skeleton (schematics, kicad, bridge, sim, llm, cpu,
    tests) with placeholder READMEs
    - Add parts_map.json stub and schematics/NOTES.md (T1) stub
    - Update docs index and top-level README
2026-06-13 Add reference materials, datasheets, and T1 schematic findings
    - Save owner-supplied primary sources under reference/ (committed):
    Sintez-2 mainboard schematic (scan + redraw), Beta Disk board photo,
    128KB expansion writeup, SCART/Jack video pinout
    - Catalog them with provenance in docs/references/sources-catalog.md
    - Collect datasheets + key parameters in docs/datasheets/README.md
    - parts_map.json v1: confirm К1533ИЕ7=74ALS193, КП12=74ALS253,
    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
2026-06-13 Extract mainboard BOM + wiring from schematic (tiles kept)
    - Segment the mainboard schematic into a 3x4 350-dpi grid; keep tiles in
    schematics/tiles/ (committed) with a grid map README
    - schematics/bom.json: ~40 packages identified with confidence flags —
    D6=Z80 (power pins 11/29), D28-D35=К565РУ5 DRAM, D36=16KB ROM,
    D39/D40/D61=ИР16 pixel chain, D23-D26=КП12 arbitration, D2/D3/D4/D19=ИЕ7
    - schematics/wiring.json: buses, control signals, connector pinouts, power
    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
2026-06-13 Tile + extract the colorized vector redraw (net names, K1533 family)
    - Tile reference/schematics/sintez2-original.pdf (vector redraw) into a 4x3
    grid in schematics/tiles-color/, plus per-color layer separations
    (parts=dark-red, net-labels=blue, wires=other colors) and high-zoom crops
    - Decode color semantics; redraw names nets + prints exact part numbers, so it
    is now the primary net source (scan is the cross-check)
    - BOM/wiring -> v0.2 corrections: family K1533 (registers K555IR16/22/23, DRAM
    K565RU5, CPU Z80A); D41 (not D61) = 3rd pixel shift reg; D13=LI1 makes
    /RAS+/CAS; D14=LE1; D45=IR16, D46/D47=KP12; YC-1..5 analog driver modules
    - X8 64-pin expansion bus pinout now high-conf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
2026-06-13 Record Russian-forum corroboration for the Sintez-2 BOM gaps
    - Web-searched zx-pk.ru (t-240), Habr, Pikabu: no per-designator BOM/netlist is
    published; our schematic (from ZX-Club #7) is authoritative. Forums confirm
    only top-level specs.
    - Concrete gains: 128K mod lifts 3 pins of the КП12 A14/A15 mux + 2nd РУ5 row
    with CAS split -> corroborates D26 КП12 as the A14/A15 paging mux
    - D36 ROM = 28-pin 16Kx8 EPROM (27128-class; К573РФ6/РФ8 or imported)
    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
2026-06-13 Resolve most BOM gaps from color tiles (IA unreachable)
    - Internet Archive (web.archive.org) and archive.ph are blocked by this
    environment's egress policy; forum mirrors are dead. Recorded as such.
    - Pivoted to high-zoom color-tile crops (no board/internet needed):
    D5=КП12 (video-addr K8-K12 from V-counters), D11=К561ИЕ10/CD4520 (resolves
    ИЕ10), D26=КП12, D36=27128 (labeled literally), D48=ИР22 (border BB/RB/GB)
    - Captured К565РУ5 address-pin -> VADDR map and K8-K12 video-fetch bus in
    wiring.json; BOM/wiring -> v0.3
    - Remaining open: D37/D44/D49/D50/D51 (disk/keyboard) - not online, no board
2026-06-13 Add Sintez-2 board photos from Russian web (habr, priborazbor)
    - Downloaded motherboard photos (image CDNs reachable; web.archive.org is not):
    reference/photos/sintez2-board-habr.jpg (1920x1278 original) + priborazbor view
    - Confirms CPU = imported Zilog Z8400 (ceramic), layout matches schematic,
    КТ315 output transistors; scrap-content count is a rough total-IC cross-check
    - 1920px too low to read individual silkscreen designators; D37/D44/D49/D50/D51
    still unresolved (need higher-res photo or more color-redraw high-zoom reads)
    - Record in bom.json external_corroboration + ledger
2026-06-13 Deeper image search: exhaust online board photos, add rear panel
    - Pulled all 8 habr article images at max res; habrastorage caps at 1920px and
    only one is a board shot. Full-res host beta.hstor.org is dead (no DNS).
    - Conclusion: no higher-res Sintez-2 board photo exists online than the 1920px
    habr shot - insufficient for tiny silkscreen designators
    - Saved reference/photos/sintez2-rear-panel.jpg (corroborates connector set:
    PS/TV/RESET + card-edge X8 bus + DB9/DIN; nameplate dates unit 1995)
    - D37/D44/D49/D50/D51 remain open -> color redraw is the viable route
2026-06-13 Deeper Russian search: repair threads corroborate BOM (no hi-res photo)
    - Russian-targeted queries surfaced Sintez-2 repair threads (zx-pk.ru 27280/
    19568, zx-pk.com 17915). Their photos are 799x599 thumbnails + TV diagnostic
    screens - no readable board close-up. S2_09.jpg = lower-res copy of our sheet
    (confirms page 29, ПРИЛОЖЕНИЕ 2, canonical)
    - Forum text corroborates: D39-D42 = pixel+attribute gen, КР1533КП12 video
    muxes, ИР16; rebuild notes (К555<->К1533, РУ5 В/Г, 27128->W27C512)
    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
2026-06-13 Add owner-supplied YouTube reference + online sources to catalog
    - Save https://youtu.be/0_mFe5sdLsc (Sintez-2 video) to sources-catalog.md
    - Record the web sources used in research (habr, zx-pk repair threads,
    priborazbor) and the egress reachability note
2026-06-13 Recover Muravyev Drive reference set + repair-video transcript
    Mirror the owner-supplied YouTube author's (Dmitry Muravyev) public Google-Drive
    reference pack into the repo and extract its findings:
    - reference/board/sintez2-element-placement.jpg — board silkscreen layout that
    physically locates all 51 ICs; resolves the open designators D37/D44/D49/D50/D51.
    - reference/schematics/{power-supply,keyboard}.jpg — PSU + keyboard schematics.
    - reference/manual/sintez2-user-manual.pdf — 11-page factory manual (03/1992).
    - docs/references/transcripts/ — ru+en auto-caption transcript of the repair video.
    Findings folded into sources-catalog.md: full 'Питание микросхем' pow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
2026-06-14 T1 complete: identify all 51 ICs + corrections from KiCad redraw
    Read every chip type off the Eeschema redraw 'Sintez_II_orig.sch' (NPO Signal
    Chișinău, 29 oct 2012) rendered at 600-800 dpi, cross-checked vs the power table.
    Resolved the 5 open designators:
    D37=К1533ЛА4 (74ALS10, kbd/joystick decode), D44=К1533ИР22 (74373, disk data),
    D49=К544СА3 (LM311-class comparator, tape-IN), D50=К1533АП3 (74244, disk addr),
    D51=К1533ИР22 (74373, disk data-in).
    Corrections to spec/earlier BOM:
    - D38=КР1533ИР27 (74273 octal D-FF), not ИР23/74LS374.
    - К555ИР16 (D39/40/41/45) = 4-bit/14-pin shift register, NOT 74LS165 (8-bit/16-pin).
    Resolves the v0.2 power-table d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
2026-06-14 Propagate T1 corrections to parts_map + datasheets
    - К555ИР16: 4-bit/14-pin shift register, NOT 74LS165 (8-bit/16-pin).
    - Tape part: К544СА3 analog comparator (D49), NOT К5545АЗ/LM567 tone decoder.
    - Class-5 redefined as 'tape input conditioning (comparator)'.
    - gitignore the .venv.
2026-06-14 T2 block 1: SKiDL schematic skeleton — CPU+clock+reset, netlist OK
    Author the canonical schematic as SKiDL/Python (decision 0005): emits a KiCad
    netlist for Pcbnew + the SimulIDE bridge; no hand-drawn .kicad_sch.
    - kicad/skidl/sintez_parts.py — Sintez part library with real pin lists from the
    datasheets/BOM (Z80 DIP-40, 27128, К1533ЛН1/ТМ2, passives). Footprints reuse
    KiCad Package_DIP:*; no KiCad symbol lib needed to make a netlist.
    - kicad/skidl/sintez2.py — block 1: D6 Z80 + Z1 14MHz oscillator (D1 К1533ЛН1,
    R1/R2/C1) + power-on reset (C2/R10) + control-input pull-ups (R4-R7).
    Generates kicad/sintez2.net with 0 ERC errors (warnings = bus pins not yet
    wired to ROM/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
2026-06-14 T2 block 2a: wire ROM (D36 27128) to CPU buses + power
    D36 27128 added to the SKiDL design and connected to the A0-A13 / D0-D7 buses and
    power (VPP/PGM=VCC, read mode). Netlist verified: A0=D6.30+D36.10, D0=D6.14+D36.11,
    A14 stays CPU-only (27128 is 16K). /CE,/OE left as named decode nets (~ROMCS/~ROMOE)
    pending the decode sub-block. 0 ERC errors; 43 nets, no merge bugs.
2026-06-14 Add proprietary LICENSE (Lightcypher SRL) + live SVG schematic viewer
    - LICENSE: proprietary/all-rights-reserved for Lightcypher SRL; this repo is NOT
    open-source. Third-party tools/datasheets keep their own licenses. README notes it.
    - kicad/skidl/sintez2.py now also emits a live schematic SVG (generate_svg via
    netlistsvg) on each run; node bin added to PATH so it resolves.
    - kicad/skidl/viewer.html: auto-refreshing page to watch the schematic grow
    block by block (open with xdg-open). *.svg/*.json are gitignored build artifacts.
2026-06-14 T2 block 2b: functional ROM address decode (~ROMCS/~ROMOE)
    Add decode-gate part defs (К1533ЛЕ1 74LS02, К1533ЛА3 74ALS00, К1533ЛА4 74ALS10)
    and wire the ROM select:
    ~ROMCS = NAND( (A14 NOR A15) , ¬/MREQ ) [D22 ЛЕ1, D9 ЛН1, D17 ЛА3]
    ROM /OE = /RD
    Verified in netlist: ~ROMCS=D17.3+D36.20, ~ROMOE=D36.22+D6.21, 0 ERC errors.
    ROM is now functionally selected. CONFIDENCE: logic is Spectrum-48K-correct; the
    exact gate-section/pin mapping is to be verified pin-by-pin against the scan.
2026-06-14 T2 block 3: DRAM array (D28-D35 К565РУ5) + /RAS/CAS (D13)
    Add К565РУ5 (4164 DIP-16) and К1533ЛИ1 (74LS08) part defs. Instantiate the 8x1-bit
    64 KB DRAM array sharing VA0-VA7 (address-pin->VA map taken from wiring.json
    dram_addr_map), /RAS, /CAS, /WE; per-bit DIN<-Dn, DOUT->DDn. D13 ЛИ1 generates
    /RAS,/CAS (R15/C5 delay, timing strobes from block 4/5 TBD); /WE merged with /WR.
    Verified: ~RAS=D13.6+8x pin4, ~CAS=D13.8+8x pin15, VA0=8x pin5; 65 nets, 0 ERC errors.
2026-06-14 T2 block 4 (partial): bus arbitration muxes drive VA0-VA5
    Add К1533КП12 (74ALS253 dual 4:1 mux) + КР1533ИР27 (74273) part defs. Place the
    arbitration ICs D5/D23/D24/D25/D26 (КП12) + D38 (ИР27) with power and map the mux
    outputs to the DRAM address bus: VA0/VA1<-D23, VA2/VA3<-D24, VA4/VA5<-D25; shared
    selects to ARB_ROWCOL/ARB_CPUVID. 21 ICs, 67 nets, 0 ERC errors.
    HONEST SCOPE: only confident output->VA mapping wired. The screen-address data-input
    mapping + select/enable timing (the crown-jewel logic) is left for a dedicated
    pin-by-pin trace rather than guessed, to keep the netlist trustworthy.
2026-06-14 T2 block 5: /4 CPU-clock divider (resolves CLK) + sync counters
    Add К1533ИЕ7 (74193) def. D8 ТМ2 ripple-divides the 14 MHz oscillator: /2 -> 7 MHz
    dot clock -> /2 -> 3.5 MHz CPU CLK (CLK net now driven: D6.6+D8.9). Place H/V sync
    counters D2/D19/D3/D4 (ИЕ7), powered + clocked from the dot clock + cascaded via
    carry. 26 ICs, 0 ERC errors. H/V sync decode gates functional/TODO.
    Note: generate_svg (movie) errored on this larger design (netlistsvg 'undefined');
    netlist is clean. SVG fix tracked separately.
2026-06-14 Validate schematic via trace-verify workflow; apply corrections + report
    8-block trace+adversarial-verify workflow (16 agents). Applied verified corrections:
    - D5 = К1533КП11 (quad 2:1 mux, 74257), NOT КП12 (schematic label; BOM was wrong).
    - R49 = 1.8K, not 1k.
    - RGB drivers are VT3-VT12; VT13 is the beep driver; VT13-VT18 'region' was wrong.
    - Net 'a' (red global label) = GND/0V.
    New report docs/references/validation-trace-verify-2026-06-14.md: per-block
    confirmed/ambiguous/missing nets. Key results: pixel-chain/color/rgb/disk/sync
    ICs ready to wire; ROM /CE/OE gating + arbitration screen-address select are
    unresolvable by vision tracing (vindicates the functional decode/arb in blocks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
2026-06-14 Fix installer SimulIDE detection: use find, not 'ls -t <glob>'
    With no matching file, 'ls -t <glob>' (nullglob) fell back to listing the cwd and
    mis-picked an unrelated entry (e.g. 'cyros-build'), then tar failed. Replace with a
    find scoped to ~/Downloads (real files, newest first) so 'none found' correctly
    prints the download instructions. ngspice install path unaffected.
2026-06-14 Document SimulIDE .sim1 format + bridge part-mapping plan (T3)
    SimulIDE 1.1.0-SR2 installed; explored its library + circuit format. bridge/README
    now specifies: the .sim1 XML structure (Subcircuit items with per-part logic-family
    timing Tpd_ps/Out_High_V, Connector/Node nets), the Soviet->SimulIDE item mapping
    (Z80 model, 74xx series incl. 74HC257=КП11/373/374/193/166, RAM/ROM), and the
    validation goal (simulate the nodes the trace-verify workflow could not resolve:
    ROM gating, arbitration select, RAS-before-CAS, boot-to-©). Build spec for net2sim.py.
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2026-06-15 T3 bridge v0: net2sim.py — SKiDL netlist -> SimulIDE .sim1
    Implement the KiCad->SimulIDE bridge. Parses kicad/sintez2.net, maps each part to a
    SimulIDE library item (Z80 via a fixed pin table; 74xx via SimulIDE .package
    number->id reads, with _LS variant for К555 timing; R/C->Resistor/Capacitor;
    crystal->14 MHz Clock), and emits sim/circuits/sintez2.sim1 (Node + Connectors per
    net). Run: 36 comps -> 27 items, 25 nets, 100 connectors; well-formed XML.
    Honest coverage notes printed: DRAM/ROM skipped (SimulIDE Memory built-ins, next),
    КП12->74HC153 / ИР16->74XX166 / ЛА4->74HC00 are approximations. .sim1 gitignored.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
    [net2sim.py]
2026-06-15 T3 bridge v1: SimulIDE circuit loads cleanly (0 errors)
    Fix net2sim to SimulIDE idioms (learned from the load-test + the ZX example):
    - Z80 -> itemtype=MCU (pins PORTA*/PORTD*/CPORT0*), not Subcircuit (was 'Cannot
    read file').
    - Nets -> Tunnels (named-net labels) instead of Node chaining (was 'null endpin');
    scales to any fan-out, matches SimulIDE's idiom.
    Headless load-test: simulide sim/circuits/sintez2.sim1 -> 0 errors. 36 comps ->
    27 items, 98 tunnels, 98 connectors. ROM/DRAM (Memory/DynamicMemory items) + family
    timing are the next additions; README updated with the plan + ZX template ref.
    [net2sim.py]
2026-06-15 net2sim: clean layout — spaced parts + pin-anchored tunnels
    Address overlap: parse pin xpos/ypos/angle from the .package, place each net Tunnel
    right at its pin (28px outward stub) instead of dumping tunnels in a band, and space
    components on a wide 360px grid so DIP bodies never overlap. With Tunnels carrying
    connectivity by name there are no long cross-component traces at all. Still loads
    with 0 errors. Z80(MCU) pins get a synthetic DIP-40-style 2-column layout.
    [net2sim.py]
2026-06-15 net2sim: drawn wires via channel router (lines, not tunnels)
    User prefers actual wires that just don't cross component bodies. SimulIDE has no
    auto-arrange/auto-route (confirmed via its circuit-canvas docs), so route in the
    generator: components in a single row, one horizontal track per net in a channel
    below them, a 3-pin Node under each pin, vertical pin->track drops. All tracks live
    below the components -> no wire crosses a component body (wires only cross each
    other). 0 load errors; 36 comps -> 27 items, 98 nodes, 171 connectors.
    [net2sim.py]
2026-06-15 net2sim: compact grid layout that fits the canvas (1200x1050)
    Drop the wide single-row+channel router (7920px wide). Components on a compact 7-col
    grid; nets = drawn wires chained via centroid Nodes with direct lines (wire overlap
    is fine per user). Extent ~1200x1050; 0 load errors; 27 items, 48 nodes, 121 wires.
    [net2sim.py]
2026-06-15 T3 bridge: add ROM (Memory 16Kx8) + DRAM (DynamicMemory 64Kx8)
    The next functional step: emit the 27128 ROM as one SimulIDE Memory(16Kx8) and the
    8x К565РУ5 array as one DynamicMemory(64Kx8, real RAS/CAS), wired by NET NAME
    (per-chip pins dropped — standard sim modeling). ROM: A0-13->in, D0-7->out,
    ~ROMCS->Cs, ~ROMOE->outEnable. DRAM: VA0-7->in, D0-7<->out, ~RAS/~CAS->Ras/Cas,
    ~WR->We. Fixed a SimulIDE segfault by including the full electrical attribute set
    (Input_High_V/Out_*/Tpd_ps...) the Memory components require. Verified: loads + runs
    12s, 0 errors, no crash; 29 items, 56 nodes, 170 wires. NOTE: DRAM data on the D bus
    (DOUT->DD->D43 read-latch path not modeled); load a ROM image i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
    [net2sim.py]
2026-06-15 Bridge: preload the ZX48-compatible ROM into the SimulIDE Memory
    Use the in-repo, accessible ROM (no web/procurement): roms/sintez-M.rom (José
    Leandro Sintez-M dump) — verified ZX-Spectrum-48K-compatible (start DI/XOR A/
    LD DE,FFFF/JP 11CB; IM1 handler at 0x38 = FRAMES counter; © glyph at the tail;
    md5 3fbd7a99). net2sim now reads it and writes the bytes into the ROM Memory's
    Mem= attribute as signed int8. Circuit (Z80+glue+ROM+DRAM) loads + runs 12s, 0
    errors, no crash. CPU can now fetch real ROM -> ready for the boot-to-© validation.
    [net2sim.py]
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2026-06-15 T2 block 6a: pixel chain (D39/D40/D41 К555ИР16) wired
    Add part defs К555ИР16 (4-bit shift), ИР22/ИР23/АП3/КП11/СА3 (for the upcoming
    color/disk/tape blocks). Wire the pixel chain from the verified trace: D41 loads
    VD0-3, D40 loads VD4-7; serial chain D41->D40->D39->FLASH XOR(D18); OE/PE/first-SI
    to GND (net 'a'); 14 MHz clock; D40.Q3 taps the FLASH AND (D13 sec4). 0 ERC errors;
    SimulIDE loads 0 errors. (netlistsvg SVG flaky on the larger design — netlist/.sim1 fine.)
2026-06-15 T2 block 6b: colour stage (D42/D43/D45/D46/D47/D48) wired
    Pin-exact from the trace-verify nets: VD0-7 latch into D42 (ИР23 -> colour bits
    B0/R0/G0/B1/R1/G1/Y) + D43 (ИР22 -> data bus); D46/D47 КП12 mux -> BM/RM/GM/YM;
    D45 ИР16 registers -> BR/RR/GR/YR; D48 ИР22 latches border D0-D4 -> BB/RB/GB.
    OE/2G ties to GND per trace; D46/D47 OE0+select left as named control nets
    (FLASH-gated SCREEN / arbitration — TODO trace). 35 ICs, 0 ERC errors, SimulIDE loads.
2026-06-15 T2 block 7a: disk/joystick I/O (D44/D51 ИР22, D50 АП3) wired
    Pin-exact from the trace: D44/D51 latch the disk data bus (D0-7, DI0-4, J0-4),
    D50 buffers disk address A8-A15 through 8 КД522 diodes -> AA8-AA15; connectors
    X1/X2 (joysticks), X3 (keyboard), X4 (disk data DO0-4), X6 (disk address). Add
    generic discrete part factories (BJT/DIODE/SPK/CONN). The board's address diodes
    are silk-labelled 'D9..D16' (collides with the logic ICs) -> named VD9..VD16 here.
    net 'a' tied to GND (global finding). 0 ERC errors, SimulIDE loads clean.
2026-06-15 Fix D5 to К1533КП11 (74257) in SKiDL — matches the validated correction
    D5 is a quad 2:1 mux (КП11/74257), not КП12 (the trace-verify workflow + bom v0.3).
    Its outputs weren't wired yet, so the type change is clean. 0 ERC errors.
2026-06-15 T2: netlist structurally complete — all 51 ICs instantiated
    Final block: instantiate the remaining glue/sync-decode gates (D7/D10/D11/D12/D14/
    D15/D16/D18/D20/D21/D27/D37) + D49 tape comparator, all powered. Wire FLASH XOR
    (D18: pixel ^ FLASH -> SCREEN) and the tape/beep block (D49 К544СА3 conditioning,
    VT2/VT13 push-pull -> BA1 speaker, X5 connector, verifier-corrected collector/base
    nodes). Add ЛП5/ИЕ10 part defs; fix К544СА3 pinout to the traced pins.
    51/51 ICs present, 0 ERC errors, SimulIDE loads clean. Remaining open pins = the
    combinational sync-decode/glue inter-gate nets + arbitration screen-address inputs
    the trace-verify workflow could not resolve from the redraw (docu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
2026-06-15 T8: seed PCB from netlist (kinet2pcb) — 85 footprints + outline + Gerbers
    netlist -> kinet2pcb -> kicad/sintez2.kicad_pcb (all 85 footprints), place_board.py
    spreads them on a 9x10 grid (337x320 mm) + adds an Edge.Cuts outline. Verified:
    Gerber + drill export produce 26 fab files; DRC = 23 courtyard/silk overlaps + 421
    unconnected (unrouted). The .kicad_pcb is now the layout source of truth. README
    documents the flow. Next: per-block placement + routing (Freerouting/manual) + clean DRC.
    [sintez2.kicad_pcb]
2026-06-15 Resolve sync-decode nets by direct tracing (not approximated)
    Per 'rezolva, nu aproxima': high-zoom read of the redraw resolves the HSYNC chain
    exactly — D9B inverts H2; D14A NOR(/H2,H3) -> D21B.D, clocked by H1 -> HS//HS;
    D21A.Q5=/EH; D10C NAND(V4,V5,V6) for vertical decode; D13A AND -> SCREEN; D18B XOR
    pin6='C' (pixel^FLASH, confirming D18=ЛП5 not ЛН1). Captured in wiring.json
    video-sync.traced_2026_06_15. Still tracing: VSYNC flip-flop set/reset (D15B/D16),
    /VS final gate, D10A/D7C inputs.
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2026-06-15 Resolve more video-sync nets by tracing (BORDER/FLASH/SCREEN/GH)
    Continued direct high-zoom read (not approximated): D10C=NAND(V4,V5,V6) vertical
    decode; D12A ТМ2 /Q=BORDER; D11 ИЕ10=FLASH timer; D14D ЛЕ1 NOR=GH gate; D13A ЛИ1
    AND(D18B='C')=SCREEN final pixel stream; D16A/D16B ТМ2=VSYNC flip-flops (->/VS);
    D17A+R72/C38 RC blanking. Captured in wiring.json. Still open: exact set/reset/clock
    pin sources of the sync flip-flops (count-decode topology) — continuing.
2026-06-16 Autonomous workflow: ngspice models + РУ5 behavioral model + results
    3 ngspice decks (clock /4 divider+crystal AC=14MHz ✅; RGB ladder 8 levels 0-0.72V ✅;
    WAIT 307ns timing-sensitive vs РУ5/4164 ⚠ CAS network assumed). К565РУ5 AngelScript
    behavioral model (RAS-before-CAS, РУ5 timing) — fixed the verifier-caught getVolt()->
    getInpState() bug. sim/AUTONOMOUS-RESULTS.md documents all results + adversarial verdicts.
    Raw workflow output under schematics/sources/ (gitignored dir? no — kept for record).
2026-06-16 Resolve the arbitration CROWN JEWEL + ROM decode (verified traces)
    The previously-unresolvable screen-address generator is now traced & adversarially
    verified (high confidence), captured in wiring.json addr-arbitration.resolved_2026_06_16:
    D5 КП11 makes K8-K12 from the V-counters; D23-D26 КП12 mux DATA inputs fully mapped
    (VA0-VA7 each = {cpu-A | video-K/H/V} x {row|col}). Only the 2-bit arbitration
    SELECT/enable timing (A/B/OE0, shared) remains ambiguous. Real ROM-decode chain also
    resolved: D22A NOR(A14,A15) -> D9E -> D27C NAND -> ROM /CE (supersedes the functional
    D17 guess); D26 = A14/A15 paging mux.
2026-06-16 Bridge: apply per-family logic timing (LS vs ALS) to SimulIDE subcircuits
    From the verified family-timing table: each Subcircuit now carries Tpd/Tr/Tf/Out_V/
    Out_Imped for its family — К1533=ALS (Tpd 4ns), К555=LS (15ns), and К555ИР16
    (D39/40/41/45) forced LS at Tpd 27ns (the deliberate setup-margin choice, spec §3,
    NOT ALS). Verified in the .sim1: D39=27000ps, D17=4000ps. Preserves the К555-vs-К1533
    fidelity distinction. 0 ERC errors, loads clean.
    [net2sim.py]
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2026-06-16 T2: wire the RESOLVED arbitration crown jewel into SKiDL
    Hoist VA/H/V/K buses to top; fix block-5 counter outputs to the verified trace
    (D2->H1-4, D3->V0-3, D4->V4-7, D19->F/S0-S2). Wire the full screen-address generator
    (wiring.json resolved_2026_06_16): D5 КП11 builds K8-K12 from the V-counters; D7B
    AND(/S2,V2)->K10; D23-D26 КП12 mux A* vs K*/H*/V* -> VA0-VA7. Verified: VA0=D23.7+DRAM,
    VA7=D26.9+DRAM (VA6/7 now driven), K8=D5.12+D25.12, K10=D7.6+D23.3. Only the shared
    arbitration select/enable timing stays as named nets. 0 ERC errors; SimulIDE loads clean.
2026-06-16 T8: re-seed PCB from the updated netlist (arbitration wired, 173 nets)
    kinet2pcb re-run after the arbitration/counter wiring; 85 footprints placed (9x10
    grid) + Edge.Cuts outline. DSN re-exported for routing.
    [sintez2.kicad_pcb]

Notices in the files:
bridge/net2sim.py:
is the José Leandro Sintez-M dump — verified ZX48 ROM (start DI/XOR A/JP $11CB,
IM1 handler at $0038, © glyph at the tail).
